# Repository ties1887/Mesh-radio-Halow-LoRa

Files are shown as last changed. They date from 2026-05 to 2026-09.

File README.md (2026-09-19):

# Mesh Radio

Open-source 3D-printable radio enclosures for Wi-Fi HaLow, MANET and LoRa experiments.

This repository contains CAD files, printable files, hardware references and short build notes. It is a DIY hardware/CAD release, not a full step-by-step wiring guide. Builders should verify fit, wiring, polarity, cooling, antenna mounting and power setup for their own hardware.

> [!TIP]
> **Support this project**  
> I am a **21-year-old full-time student** building this in my spare time. If this work helps you, donations help fund parts, prototypes and testing.  
> **[Support me on Ko-fi](https://ko-fi.com/ties1887)**

<p align="center">
  Mesh Radio V1, V2 and V3 prototypes
</p>

## Contents

- [Choose your build](#choose-your-build)
- [Standalone battery pack](#standalone-battery-pack)
- [What the files are for](#what-the-files-are-for)
- [Build notes](#build-notes)
- [Bill of materials](#bill-of-materials)
- [Planned builds](#planned-builds)
- [Software](#software)
- [Contributing and support](#contributing-and-support)
- [License](#license)

## Choose your build

| Build | Generation | Main hardware | Files |
|---|---|---|---|
| **[P4-Wio](./Second-Generation-Builds/P4-Wio/)** | Second generation | Raspberry Pi 4 + WM1302 Pi HAT + Wio-WM6108 | 3MF, STEP, SolidWorks 2025 |
| **[CM4 Carrier Board](./Second-Generation-Builds/CM4-Carrier-Board/)** | Second generation, development | Raspberry Pi CM4 + M.2 E-key Wi-Fi + optional MM8108 HaLow | KiCad source, local libraries, 3D models, review report |
| **[V3](./First-Generation-Builds/V3_18-6-2026/)** | First generation | Raspberry Pi 4 + WM1302 Pi HAT + Wio-WM6108 + RAK WisMesh 1W kit | 3MF, STEP, SolidWorks 2023/2025 |
| **[V2](./First-Generation-Builds/V2_30-5-2026/)** | First generation | Raspberry Pi 4 + WM1302 Pi HAT + Wio-WM6108 + RAK WisMesh 1W kit | 3MF, STL, STEP, SolidWorks 2023/2025 |
| **[V1](./First-Generation-Builds/V1_5-5-2026/)** | First generation | Raspberry Pi 4 + WM1302 Pi HAT + Wio-WM6108 + RAK WisMesh 1W kit | 3MF, STEP, SolidWorks 2023/2025 |

V1, V2 and V3 are still valid first generation builds. They may need more fitting or manual finishing, but they have been built, printed and used.

> [!CAUTION]
> **HaLow and LoRa together:** early tests with Wi-Fi HaLow and LoRa/Meshtastic running at the same time did not work well. The radios appeared to interfere with each other, even when using different channels. These tests were limited, so this is not a final RF conclusion, but builders should not expect HaLow and LoRa to work perfectly together without extra testing or design changes. Treat LoRa as a fallback/secondary system unless you have verified your own setup.

## Standalone battery pack

The **[Twist-Lock Battery Pack](./Twist-Lock-Battery-Pack/)** is a separate design, not part of only one build.

It is intended as a shared battery-pack design for both:

- first generation builds;
- second generation builds.

Available files include 3MF, STEP, STL and SolidWorks 2025 source archive.

## What the files are for

| File type | Use |
|---|---|
| `3MF` | Preferred print/project files for slicers |
| `STL` | Individual mesh exports when available |
| `STEP` | CAD exchange files for inspection, remixing or non-SolidWorks workflows |
| `SolidWorks` / `.zip` | Native source files or complete SolidWorks archives |

Download the complete build folder before opening a SolidWorks assembly so referenced parts remain available.

## Build notes

- **P4-Wio** is the current second generation build. It uses a Raspberry Pi 4, WM1302 Pi HAT style adapter and Seeed Studio Wio WM6108 Wi-Fi HaLow module.
- **P4-Wio is HaLow-only.** It does not include the separate LoRa/Meshtastic subsystem from the first generation prototypes.
- **V1** uses an integrated battery layout.
- **V2 and V3** use a removable twist-lock battery layout.
- **CM4 Carrier Board** source files are available for review and collaboration, but the design is not yet released for fabrication. Read its production-check report before making hardware.

<details>
<summary><strong>Prototype component and power-flow reference</strong></summary>

<br>

Prototype component and power-flow reference

This is a prototype reference for component relationships and power flow. It combines ideas from different versions and is not a final wiring guide.

</details>

<details>
<summary><strong>Prototype wiring reference</strong></summary>

<br>

Prototype wiring reference

This image documents prototype wiring. Verify every connection against the exact version and modules you are building.

</details>

## Bill of materials

The shared BOM contains parts used across multiple prototypes. **Do not order every listed part.** Check the build you are making first.

**[Open the current shared BOM](https://docs.google.com/spreadsheets/d/1Nt8EjYsgWTId0Qjl1BAAxPci3bh1FSZ7VQxQRFxyHnk/edit?usp=sharing)**

Supplier links, prices and availability may change. Confirm dimensions, connector type, voltage range and module version before ordering.

## Planned builds

<details>
<summary><strong>Future build names and targets</strong></summary>

<br>

| Build | Hardware target | Notes |
|---|---|---|
| `P4-LongWave` | Raspberry Pi 4 + Lunpid/LongWave MM8108 USB HaLow | Planned Pi 4 USB HaLow build |
| `C4-LongWave` | Raspberry Pi CM4 + Lunpid/LongWave MM8108 USB HaLow | Planned compact CM4 build |
| `C4-DualMesh` | Raspberry Pi CM4 + MM8108 HaLow + MT7916EUD | Research path for HaLow plus 2.4/5/6 GHz mesh |

```text
P4 = Raspberry Pi 4
C4 = Raspberry Pi Compute Module 4
Wio = Seeed Studio Wio WM6108 HaLow
LongWave = Lunpid/LongWave MM8108 USB HaLow
DualMesh = MM8108 HaLow plus MT7916EUD for 2.4/5/6 GHz mesh
```

A planned build should get its own folder when it has a selected hardware stack, CAD layout, printable/exported files and a short build README.

</details>

## Software

Software installation and support are provided by the upstream projects:

- **[OpenMANET documentation](https://openmanet.github.io/docs/)**
- **[OpenMANET firmware](https://github.com/OpenMANET/firmware)**
- **[Meshtastic documentation](https://meshtastic.org/docs/)**
- **[Meshtastic firmware](https://github.com/meshtastic/firmware)**

OpenMANET, Meshtastic and third-party hardware remain subject to their own licenses, documentation and support policies.

## Contributing and support

Questions, measurements, test results, issue reports, documentation corrections and design improvements are welcome.

- **[Open an issue](https://github.com/ties1887/Mesh-radio-Halow-LoRa/issues)**
- **[Create a pull request](https://github.com/ties1887/Mesh-radio-Halow-LoRa/pulls)**
- **Support the project:** https://ko-fi.com/ties1887
- **Contact:** Discord `ties1887`

Thank you to everyone who supports the project with feedback, testing, tips, donations or useful hardware/design suggestions.

## License

This repository is released under the **[Creative Commons Attribution-NonCommercial-ShareAlike 4.0 International License](./LICENSE)** (**CC BY-NC-SA 4.0**).

You may copy, build, modify and share the designs for personal, educational and non-commercial community use. You may not sell these designs, sell printed parts based on these designs, or use them commercially without written permission from the author.

Private modifications are allowed and do not need to be uploaded or published. If you share modified files publicly, they must stay under the same non-commercial share-alike license.

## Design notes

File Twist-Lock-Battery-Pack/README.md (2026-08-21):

# Twist-Lock Battery Pack

Standalone twist-lock battery pack design compatible with generation 1 and generation 2 builds.

## Status

Standalone battery pack CAD/export files are included.

## Files

| Folder | Contents |
|---|---|
| [`3MF`](./3MF/) | Print-ready project files |
| [`STEP`](./STEP/) | STEP exports |
| [`STL`](./STL/) | Individual STL exports |
| [`SolidWorks-2025`](./SolidWorks-2025/) | Native SolidWorks 2025 source files or archives |

## Notes

- Download the complete folder before opening SolidWorks assemblies so referenced parts remain available.
- Verify fit, polarity, wiring, cell configuration, BMS/charger setup and mechanical locking before use.

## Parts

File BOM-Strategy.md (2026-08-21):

# BOM Strategy Proposal

This note proposes a cleaner BOM structure for Mesh Radio builds.

## Current BOM observations

The current public Google Sheet BOM uses one shared table with version columns.

Observed structure:

- 27 part rows
- Categories: HaLow, LoRa, Battery and powermanagement, Enclosure, Extra hardware
- Version columns: V1, V2, V3, V4
- The sheet metadata still says `License: MIT`
- V4 is still present in the BOM although V4 was removed from the repository branch
- Many parts are shared across V1, V2 and V3, so fully separate BOMs would duplicate a lot of data

## Recommended approach

Use a **master parts list plus build-specific BOM views**.

This gives one place to maintain shared parts, while still making each build easy to understand.

## Suggested workbook tabs

| Tab | Purpose |
|---|---|
| `Parts` | Master list of every reusable part/component |
| `Build-Matrix` | Which build uses which part, with quantity per build |
| `V1-BOM` | Filtered view/export for V1 |
| `V2-BOM` | Filtered view/export for V2 |
| `V3-BOM` | Filtered view/export for V3 |
| `P4-Wio-BOM` | Filtered view/export for P4-Wio |
| `Battery-Pack-BOM` | Standalone twist-lock battery pack BOM, compatible with generation 1 and 2 builds |
| `Suppliers` | Supplier links, EU links, alternatives and notes |
| `Archive` | Deprecated/removed build references such as V4, if kept for history |

## Parts tab columns

| Column | Notes |
|---|---|
| `part_id` | Stable ID, e.g. `HALOW-WM6108`, `SBC-RPI4-2GB` |
| `category` | HaLow, LoRa, Power, Battery, Enclosure, Fasteners, Cables, Tools |
| `part_name` | Human-readable name |
| `description` | Short note |
| `manufacturer` | Optional |
| `mpn` | Manufacturer part number if known |
| `supplier` | Store/vendor |
| `supplier_url` | Purchase link |
| `unit_cost_eur` | Approximate cost |
| `notes` | Fitment, alternatives, warnings |
| `status` | active / optional / deprecated / unknown |

## Build-Matrix columns

| Column | Notes |
|---|---|
| `build_id` | `V1`, `V2`, `V3`, `P4-Wio`, `Battery-Pack` |
| `part_id` | Links to `Parts.part_id` |
| `quantity` | Quantity for this build |
| `required` | yes / optional / alternative |
| `role` | Main computer, HaLow module, LoRa module, power, fastener, etc. |
| `build_note` | Build-specific note |

## Why this is better

- Shared parts are maintained once.
- Each build can still have a simple filtered BOM.
- P4-Wio and the battery pack can each have their own clean view.
- Removed/experimental builds can be archived without confusing new builders.
- It avoids one giant confusing BOM and avoids many duplicated per-version BOMs.

## README recommendation

Keep the main README simple:

```md
## Bill of materials

The BOM is maintained as a shared parts list with build-specific views.
Open the BOM and use the tab for the build you are making.

- P4-Wio BOM
- Twist-Lock Battery Pack BOM
- First Generation V1/V2/V3 BOM views
```

## Next cleanup tasks

- Change BOM license metadata from MIT to CC BY-NC-SA 4.0.
- Remove or archive V4 from the active BOM tabs.
- Add `P4-Wio` and `Battery-Pack` as build IDs.
- Replace YES/NO version columns with a `Build-Matrix` tab if the sheet becomes hard to maintain.
- Keep supplier links and prices as approximate, because availability changes.

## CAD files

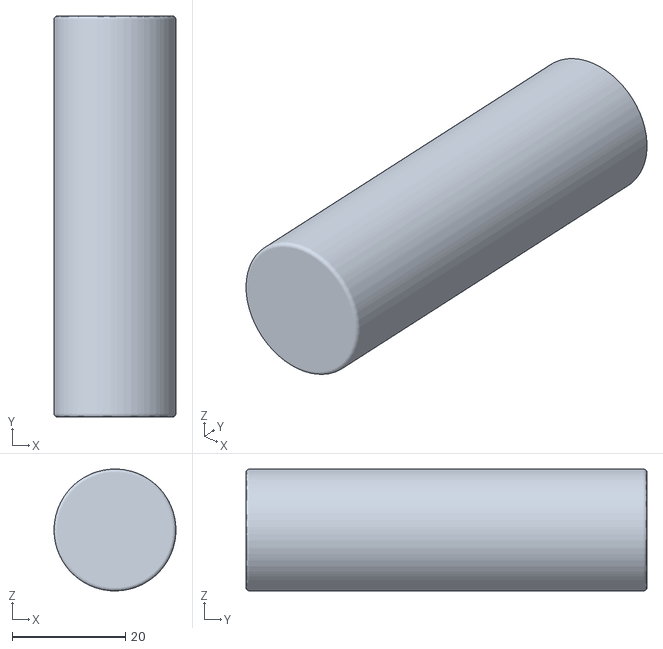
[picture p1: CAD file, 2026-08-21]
Twist-Lock-Battery-Pack/STL/Battery_Twist_Lock_Pack.SLDASM - Cell_21700-4.STL
21.5 x 70.7 x 21.5

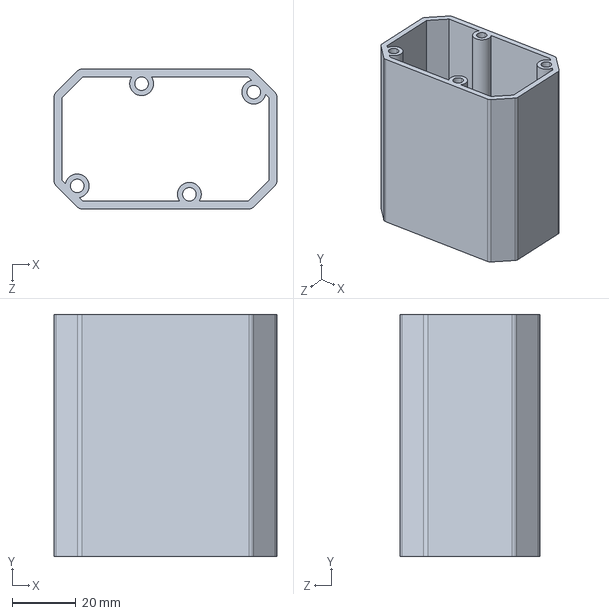
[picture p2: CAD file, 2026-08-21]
Twist-Lock-Battery-Pack/STEP/Battery_Case_Main.STEP
70.0 x 76.0 x 44.0 mm

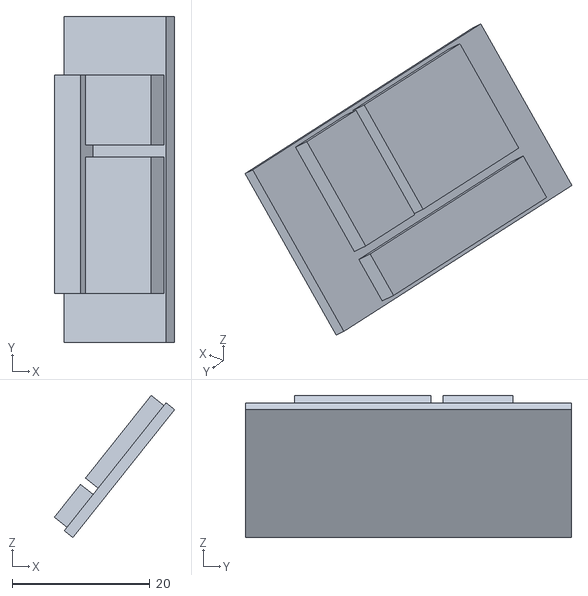
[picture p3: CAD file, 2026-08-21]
Twist-Lock-Battery-Pack/STL/Battery_Twist_Lock_Pack.SLDASM - bms 2s-1.STL
17.5 x 47.4 x 20.7

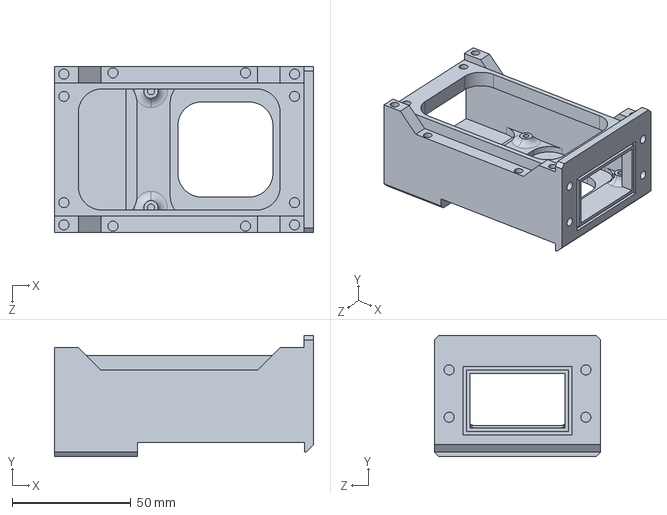
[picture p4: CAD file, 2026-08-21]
Second-Generation-Builds/P4-Wio/STEP/enclosure_main_chassis.STEP
109.0 x 51.0 x 70.0 mm

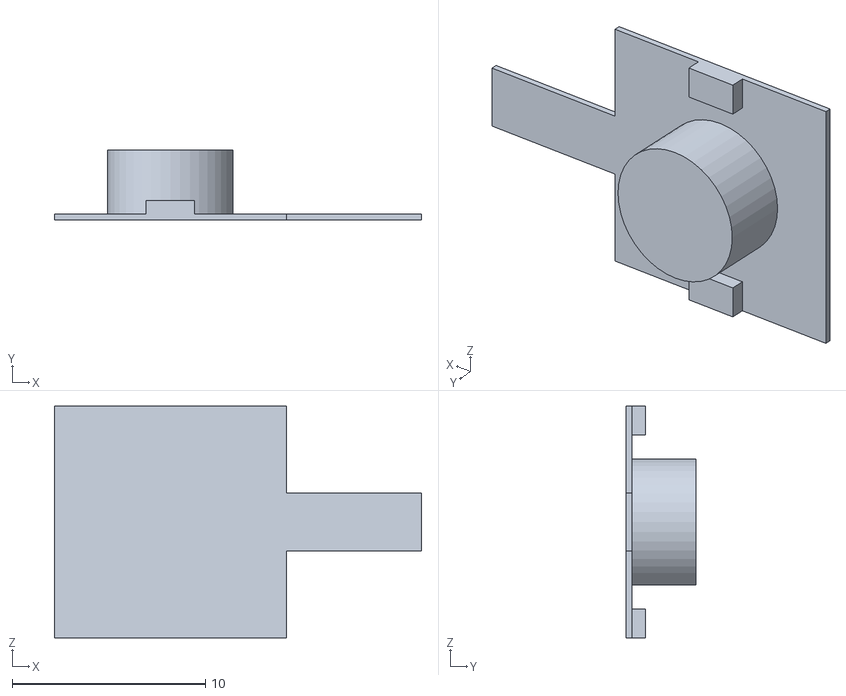
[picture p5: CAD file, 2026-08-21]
Twist-Lock-Battery-Pack/STL/Battery_Twist_Lock_Pack.SLDASM - Battery_Spring_Contact-3.STL
19.0 x 3.60 x 12.0

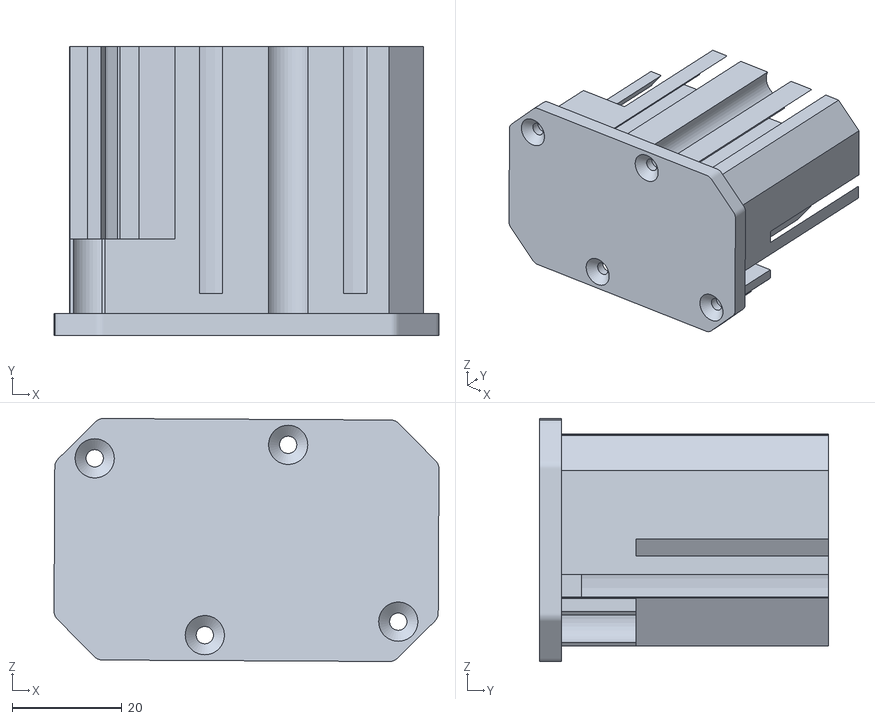
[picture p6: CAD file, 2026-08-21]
Twist-Lock-Battery-Pack/STL/Battery_Twist_Lock_Pack.SLDASM - Battery_Case_Bottom_Cover-1.STL
70.1 x 52.6 x 44.3

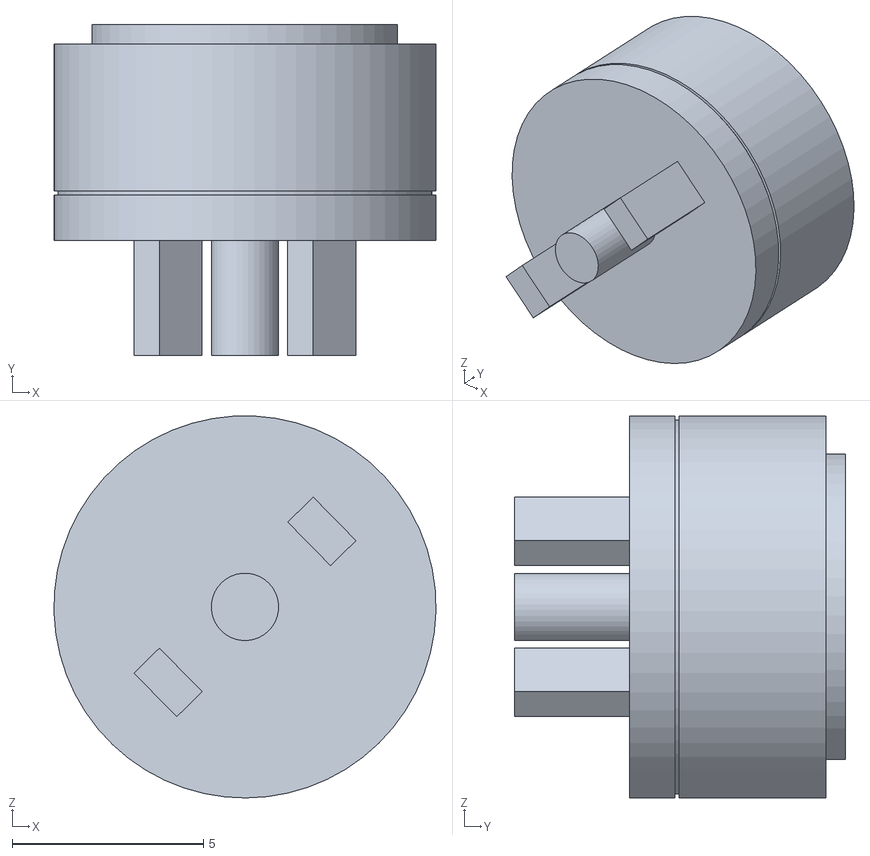
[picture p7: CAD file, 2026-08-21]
Twist-Lock-Battery-Pack/STL/Battery_Twist_Lock_Pack.SLDASM - magnetic pogo pin connector-1.STL
10.00 x 8.65 x 9.99

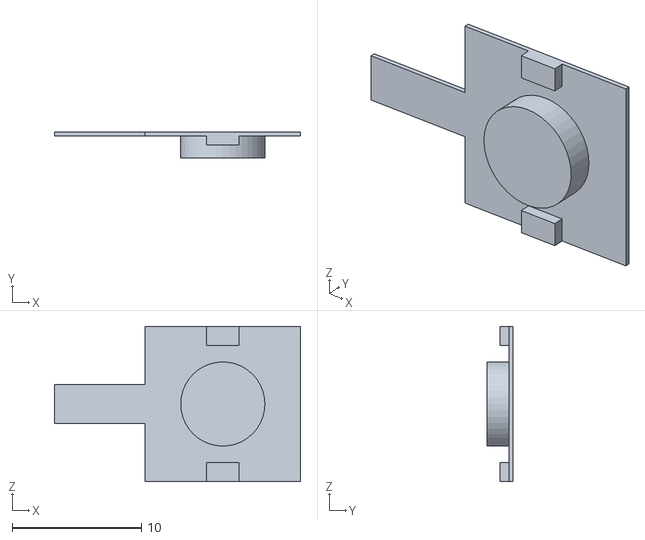
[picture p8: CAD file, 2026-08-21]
Twist-Lock-Battery-Pack/STL/Battery_Twist_Lock_Pack.SLDASM - Battery_pin_Contact-3.STL
19.0 x 2.00 x 12.0

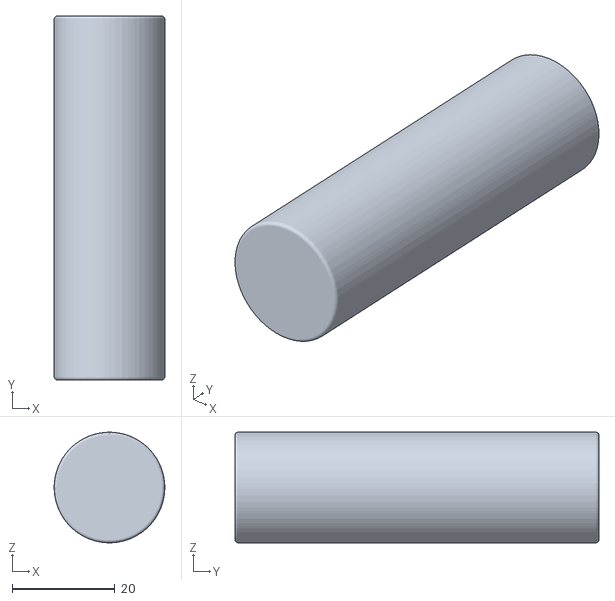
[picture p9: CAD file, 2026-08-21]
Twist-Lock-Battery-Pack/STL/Battery_Twist_Lock_Pack.SLDASM - Cell_21700-3.STL
21.5 x 70.7 x 21.5

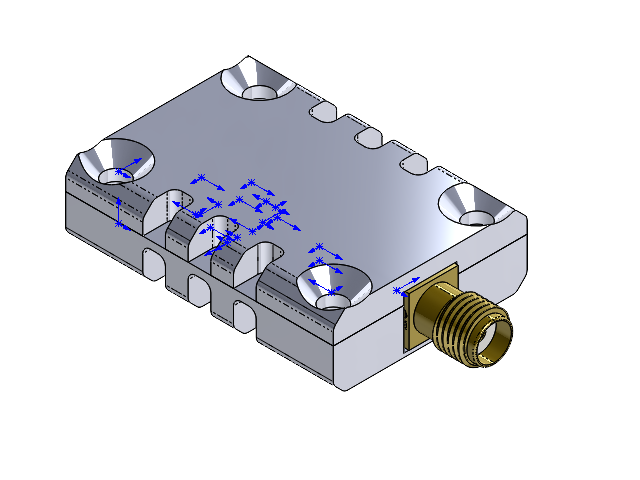
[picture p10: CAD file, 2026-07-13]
First-Generation-Builds/Standalone-Lunpid-enclosure/Solidworks 2023/enclosure.SLDASM
Bottom part
Part5^enclosure
SOT-23-5_L2.9-W1.6-P0.95-LS2.8-BL~SOT-23-5_L2.9-W1.6-P0.95-LS2.8-BL~8fiY.step
R0402~C0402_L1.0-W0.5-H0.5~8fiY.step x 8
R0402~R0402_L1.0-W0.5-H0.4~8fiY.step x 3
SMA-SMD_BWSMA-KE-P001~SMA-TH_5P-L6.5-W6.5-H9.5_BWSMA-KE-P001~8fiY.step
SC-70-3_L2.0-W1.3-P0.65-LS2.1-BL~SC-70-3_L2.0-W1.3-P0.65-LS2.1-BL~8fiY.step
LGA-38_L11.0-W10.0-P1.00-TL~LGA-38_L11.0-W10.0-P1.00-TL~8fiY.step
USB-C-SMD_TYPE-C-6PIN-2MD-073~USB-C-SMD_TYPEC-304YDSW-ACP16~8fiY.step
Board~8fiY.step

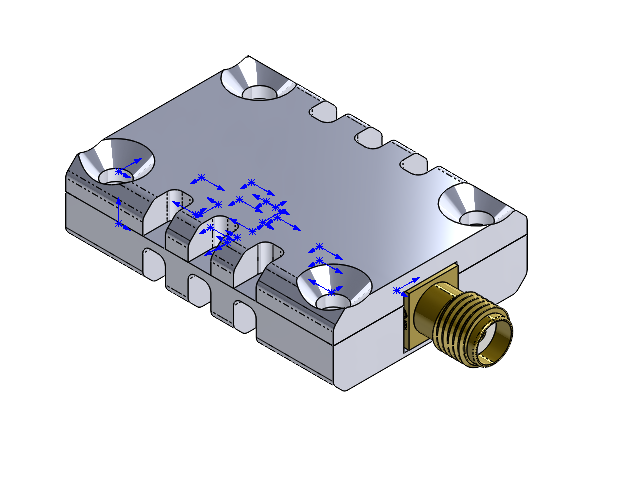
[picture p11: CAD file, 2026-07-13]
First-Generation-Builds/Standalone-Lunpid-enclosure/Solidworks 2025/enclosure.SLDASM
Bottom part
Part5^enclosure
SOT-23-5_L2.9-W1.6-P0.95-LS2.8-BL~SOT-23-5_L2.9-W1.6-P0.95-LS2.8-BL~8fiY.step
R0402~C0402_L1.0-W0.5-H0.5~8fiY.step x 8
R0402~R0402_L1.0-W0.5-H0.4~8fiY.step x 3
SMA-SMD_BWSMA-KE-P001~SMA-TH_5P-L6.5-W6.5-H9.5_BWSMA-KE-P001~8fiY.step
SC-70-3_L2.0-W1.3-P0.65-LS2.1-BL~SC-70-3_L2.0-W1.3-P0.65-LS2.1-BL~8fiY.step
LGA-38_L11.0-W10.0-P1.00-TL~LGA-38_L11.0-W10.0-P1.00-TL~8fiY.step
USB-C-SMD_TYPE-C-6PIN-2MD-073~USB-C-SMD_TYPEC-304YDSW-ACP16~8fiY.step
Board~8fiY.step

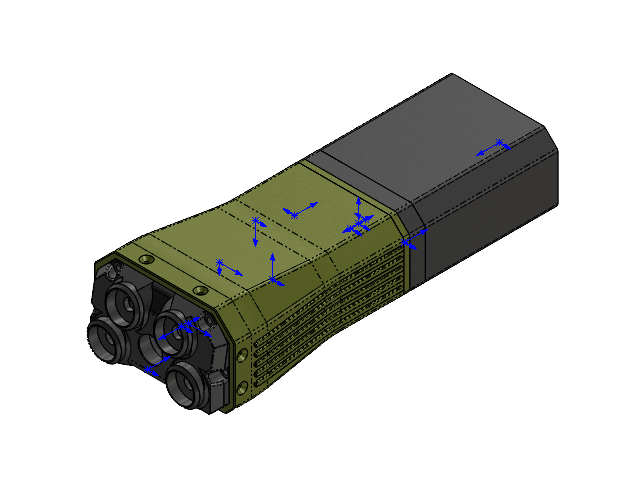
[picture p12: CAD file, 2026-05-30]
First-Generation-Builds/V2_30-5-2026/Solidworks 2025/Assem2.SLDASM
3D_RAK19007 base module + booster
pi4withall
buck converter
base
Twist lock radio part V3
middel part
Twist lock battery part V3
batcase
top
PCB frame
wing part x 2

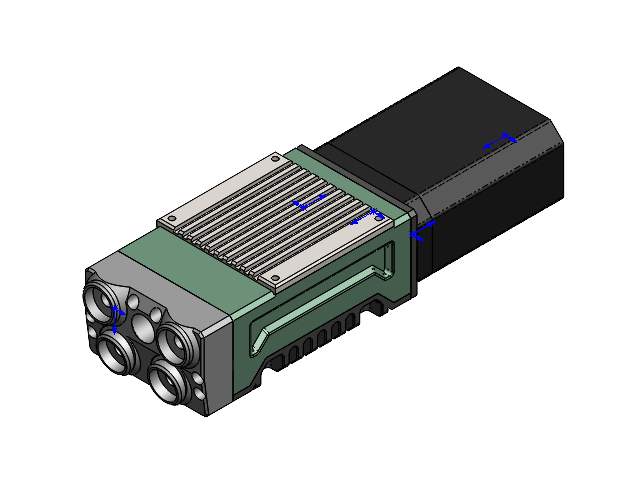
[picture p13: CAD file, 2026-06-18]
First-Generation-Builds/V3_18-6-2026/Solidworks 2025/Assem2.SLDASM
3D_RAK19007 base module + booster
pi4withall
buck converter
PCB frame
cooling
Twist lock radio part V3
Top new
middel part
batcase
Twist lock battery part V3
wing part x 2

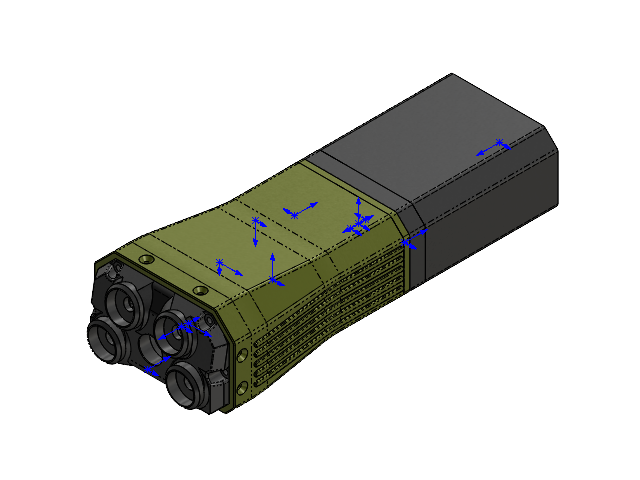
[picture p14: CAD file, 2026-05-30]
First-Generation-Builds/V2_30-5-2026/Solidworks 2023/Assem2.SLDASM
3D_RAK19007 base module + booster
pi4withall
buck converter
base
Twist lock radio part V3
middel part
Twist lock battery part V3
batcase
top
PCB frame
wing part x 2

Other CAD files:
Twist-Lock-Battery-Pack/STEP/Battery_Twist_Lock_Pack.SLDASM.STEP
First-Generation-Builds/V3_18-6-2026/Solidworks 2023/Assem2.SLDASM
Twist-Lock-Battery-Pack/STL/Battery_Twist_Lock_Pack.SLDASM - bms 2s-2.STL
Twist-Lock-Battery-Pack/STL/Battery_Twist_Lock_Pack.SLDASM - Battery_Spring_Contact-2.STL
First-Generation-Builds/Standalone-Lunpid-enclosure/3MF/enclosure.3MF
First-Generation-Builds/Standalone-Lunpid-enclosure/STEP/Bottom part.STEP
First-Generation-Builds/Standalone-Lunpid-enclosure/STEP/Top part.STEP
First-Generation-Builds/Standalone-Lunpid-enclosure/Solidworks 2023/Bottom part.SLDPRT
First-Generation-Builds/Standalone-Lunpid-enclosure/Solidworks 2023/lunpid_longwave_v0.1.step
First-Generation-Builds/Standalone-Lunpid-enclosure/Solidworks 2025/Bottom part.SLDPRT
First-Generation-Builds/Standalone-Lunpid-enclosure/Solidworks 2025/lunpid_longwave_v0.1.step
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

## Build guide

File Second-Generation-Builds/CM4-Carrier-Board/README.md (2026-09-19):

# CM4 MANET carrier board

KiCad source project for the experimental Raspberry Pi Compute Module 4 MANET carrier board.

> [!WARNING]
> **Development design — not released for fabrication.** The current production review still lists unresolved ERC, GND-connectivity, SI/PI, mechanical and manufacturing-output items. Read [`docs/PRODUCTIECHECK-2026-09-19.md`](./docs/PRODUCTIECHECK-2026-09-19.md) before using the design.

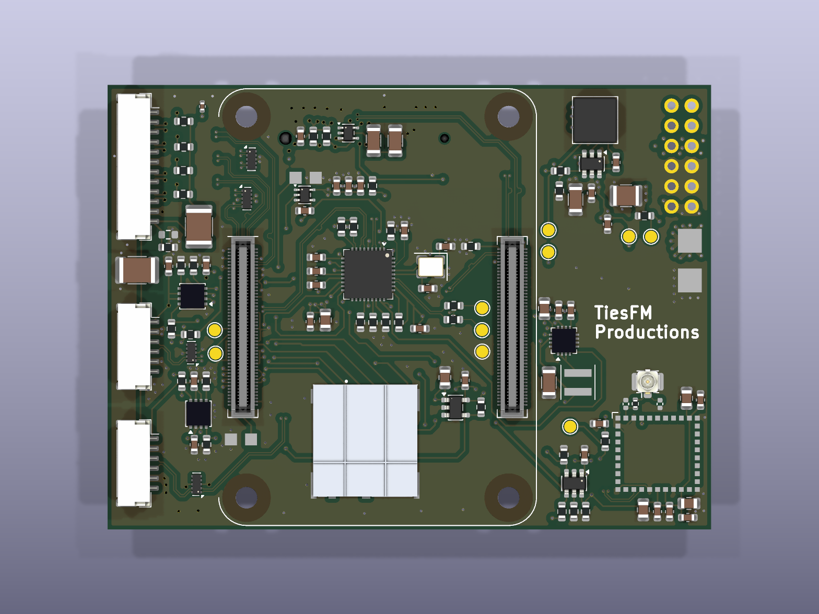
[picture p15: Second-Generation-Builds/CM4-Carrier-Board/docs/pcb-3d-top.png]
Current top-side 3D view


## Hardware target

The carrier combines:

- Raspberry Pi Compute Module 4;
- M.2 E-key Wi-Fi/MANET radio interface;
- onboard Morse Micro MM8108 HaLow option;
- USB2514B USB hub and two external USB interfaces;
- microSD, Ethernet, power regulation and service interfaces;
- Pololu D42V55F5 5 V regulator module.

## Open the project

1. Install **KiCad 10** or newer.
2. Download or clone this complete folder so the local libraries and 3D models remain beside the project.
3. Open [`CM4_MANET.kicad_pro`](./CM4_MANET.kicad_pro).
4. KiCad should resolve the bundled libraries through [`sym-lib-table`](./sym-lib-table) and [`fp-lib-table`](./fp-lib-table).

The project uses KiCad's standard symbol, footprint and 3D libraries in addition to the bundled local files.

## Included files

| Path | Purpose |
|---|---|
| `CM4_MANET.kicad_pro` | KiCad project settings and design rules |
| `CM4_MANET.kicad_sch` | Hierarchical top-level schematic |
| `01_…16_*.kicad_sch` | Schematic sheets |
| `CM4_MANET.kicad_pcb` | Routed six-layer PCB |
| `MANET.kicad_sym` | Bundled project symbols |
| `MANET.pretty/` | Bundled project footprints |
| `G2401CE.kicad_sym` | Ethernet magnetics symbol |
| `G2401CE.pretty/` | Ethernet magnetics footprint |
| `models/`, `G2401CE.3dshapes/` | Local 3D models referenced by the board |
| `docs/PLAN-EN-STATUS.md` | Canonical design context and decisions |
| `docs/PRODUCTIECHECK-2026-09-19.md` | Latest production-readiness review and correction checklist |
| `DATASHEET-INDEX-V0.11.md` | Component/source index |

## Verified source snapshot

The upload was prepared from the latest saved and synchronized project snapshot available on 19 September 2026.

| File | SHA-256 |
|---|---|
| `CM4_MANET.kicad_pro` | `29031d407538b3dbcb6472aa7c64797e4d6ba71f1556e2ef84310c6bf45d1d5d` |
| `CM4_MANET.kicad_sch` | `d8fc85620186ded0c0d289be1d9e3905773756102ce121de9318bc477c56a758` |
| `CM4_MANET.kicad_pcb` | `218439d0e7e71eeba17b0bce05ddc644826dbbb2ce876aa322ecba9a2478592e` |

## Deliberately not included

The following local files were excluded because they are stale, generated, machine-specific or not needed to inspect/edit the source:

- old Gerbers and drill files;
- old BOM/CPL quotation exports;
- old STEP assembly export;
- KiCad lock/preferences files;
- temporary validation output;
- `.history`, caches and backups;
- local copies of third-party datasheets.

Generate new fabrication files only after the correction checklist is closed and the design has passed a fresh production review.

## License

This folder follows the repository license: [CC BY-NC-SA 4.0](../../LICENSE).

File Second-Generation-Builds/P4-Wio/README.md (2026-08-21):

# P4-Wio

Second generation Mesh Radio build: Raspberry Pi 4 based HaLow-only radio enclosure using the Seeed Studio Wio WM6108 module through a WM1302 Pi HAT style adapter.

## Status

Updated P4-Wio CAD/export files are included for review and building.

## Hardware target

| Part | Role |
|---|---|
| Raspberry Pi 4 | Main computer for HaLow/IP networking |
| WM1302 Pi HAT style adapter | Mini-PCIe adapter path for the HaLow module |
| Seeed Studio Wio WM6108 | Wi-Fi HaLow radio module |

This is a **HaLow-only** build. It does not include the separate LoRa/Meshtastic subsystem from the first generation V1-V3 prototypes.

## Files

| Folder | Contents |
|---|---|
| [`3MF`](./3MF/) | Print-ready project file |
| [`STEP`](./STEP/) | Full assembly and individual CAD exchange files |
| [`SolidWorks-2025`](./SolidWorks-2025/) | Native SolidWorks 2025 source archive |

## Included CAD exports

| File | Purpose |
|---|---|
| [`P4-WIO_v1.1.3MF`](./3MF/P4-WIO_v1.1.3MF) | Print/project file |
| [`P4-WIO.STEP`](./STEP/P4-WIO.STEP) | Full assembly STEP export |
| [`raspberry_pi4_wm6108_halow_stack.STEP`](./STEP/raspberry_pi4_wm6108_halow_stack.STEP) | Pi 4 + WM6108 HaLow stack reference |
| [`enclosure_main_chassis.STEP`](./STEP/enclosure_main_chassis.STEP) | Main enclosure body |
| [`enclosure_front_cover.STEP`](./STEP/enclosure_front_cover.STEP) | Front cover |
| [`enclosure_top_cover.STEP`](./STEP/enclosure_top_cover.STEP) | Top cover |
| [`bottom seal.STEP`](./STEP/bottom%20seal.STEP) | Bottom seal |
| [`gasket_front_cover.STEP`](./STEP/gasket_front_cover.STEP) | Front cover gasket |
| [`gasket_top_cover.STEP`](./STEP/gasket_top_cover.STEP) | Top cover gasket |
| [`gasket_heatsink_external.STEP`](./STEP/gasket_heatsink_external.STEP) | External heatsink gasket |
| [`mount_twist_lock_magnetic_radio.STEP`](./STEP/mount_twist_lock_magnetic_radio.STEP) | Battery/radio interface mount |
| [`heatsink_external_70x70x3-6mm.STEP`](./STEP/heatsink_external_70x70x3-6mm.STEP) | External heatsink reference |
| [`pololu_buck_converter.STEP`](./STEP/pololu_buck_converter.STEP) | Buck regulator reference |
| [`Mpu5 antenna.STEP`](./STEP/Mpu5%20antenna.STEP) | Antenna reference |
| [`gnns gps.STEP`](./STEP/gnns%20gps.STEP) | GNSS/GPS reference |
| [`middel part.STEP`](./STEP/middel%20part.STEP) | Middle part |
| [`P4-WIO_v1.1.zip`](./SolidWorks-2025/P4-WIO_v1.1.zip) | SolidWorks 2025 source archive |

## Notes

- Download the complete folder before opening the SolidWorks assembly.
- The STEP files are provided for inspection, remixing and non-SolidWorks workflows.
- Verify tolerances, wiring, polarity, cooling, antenna fit and power setup for your own parts before applying power.

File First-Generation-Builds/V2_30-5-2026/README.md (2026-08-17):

# First Generation V2

More compact Pi 4/Wio prototype with the first integrated removable twist-lock battery.

## Visual Overview AI Render

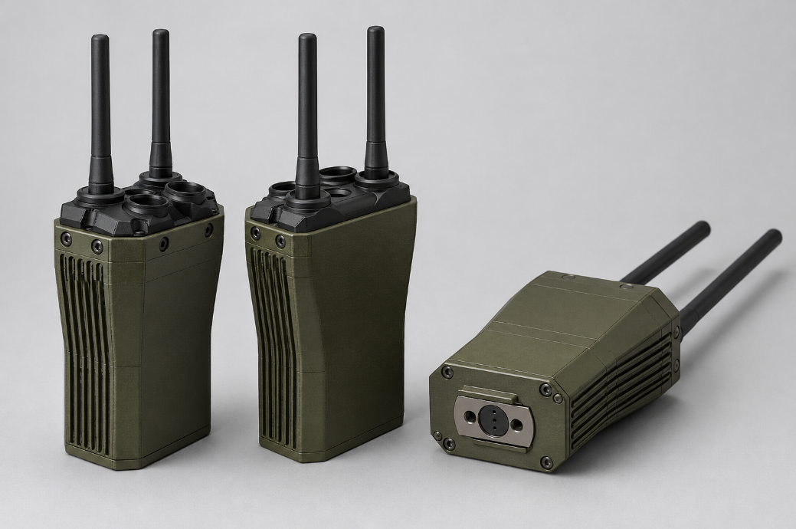
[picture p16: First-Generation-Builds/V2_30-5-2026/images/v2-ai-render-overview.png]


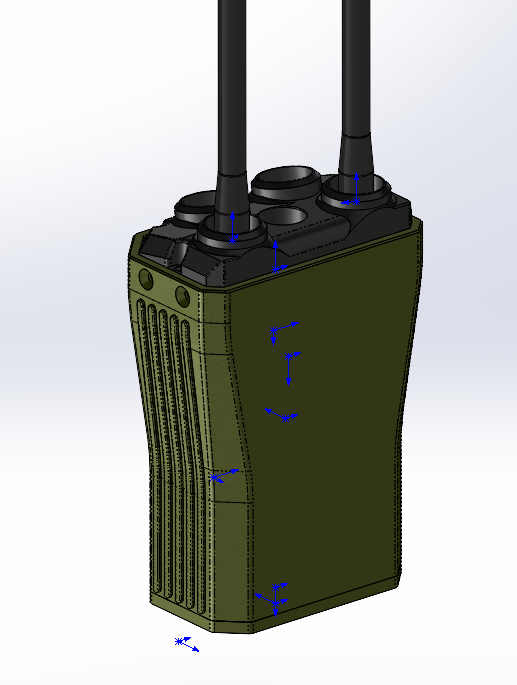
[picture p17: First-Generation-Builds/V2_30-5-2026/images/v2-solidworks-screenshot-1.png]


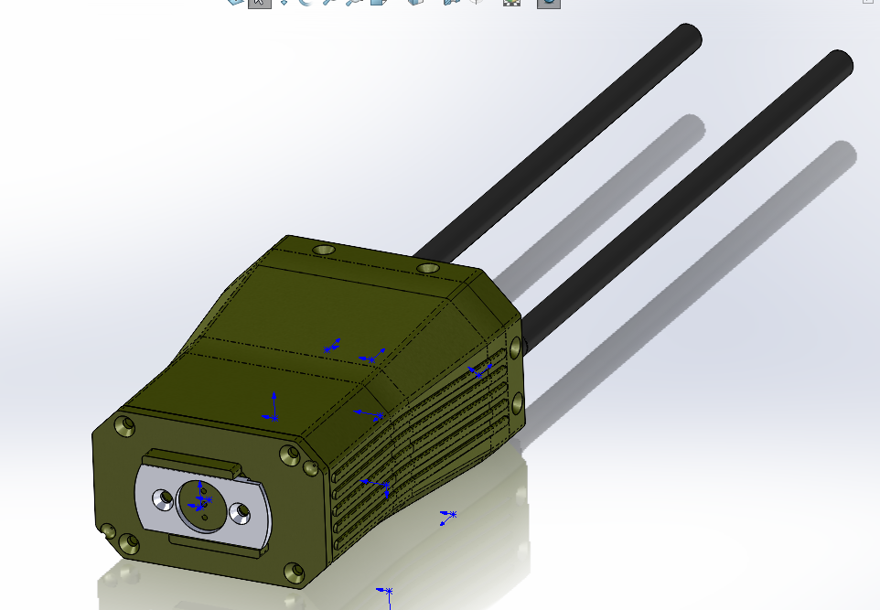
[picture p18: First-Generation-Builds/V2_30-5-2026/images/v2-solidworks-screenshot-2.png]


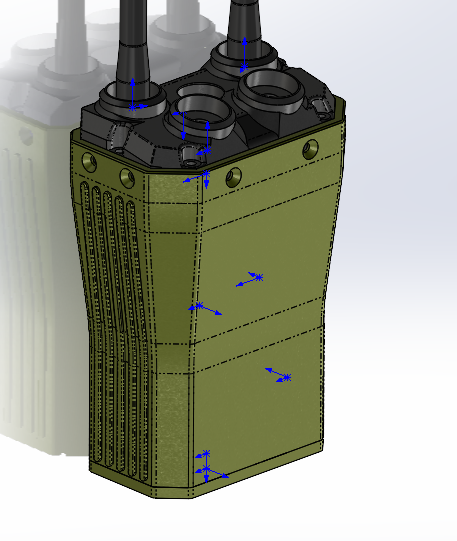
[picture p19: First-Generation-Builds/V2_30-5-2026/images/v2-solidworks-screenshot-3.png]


## Hardware

| Part | Notes |
|---|---|
| Raspberry Pi 4 | Main computer |
| WM1302 Pi HAT | Mini-PCIe adapter path |
| Seeed Studio Wio WM6108 | Wi-Fi HaLow module |
| RAK WisMesh 1W kit | Separate Meshtastic / LoRa subsystem |

## Battery

Removable twist-lock battery system.

## Files

- `3MF/` print-ready files
- `STL/` individual printable parts
- `step/` STEP exports
- `Solidworks 2023/` native files
- `Solidworks 2025/` native files

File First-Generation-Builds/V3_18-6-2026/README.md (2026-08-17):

# First Generation V3

Most complete old Raspberry Pi 4 prototype.

## Visual Overview AI Render

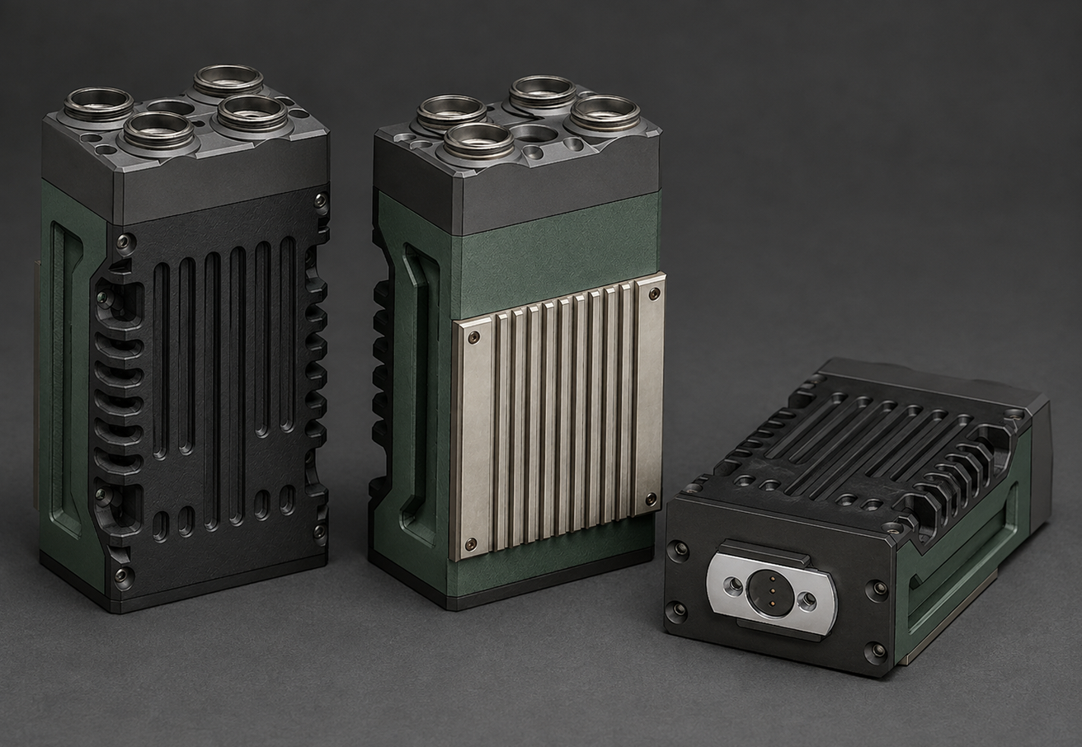
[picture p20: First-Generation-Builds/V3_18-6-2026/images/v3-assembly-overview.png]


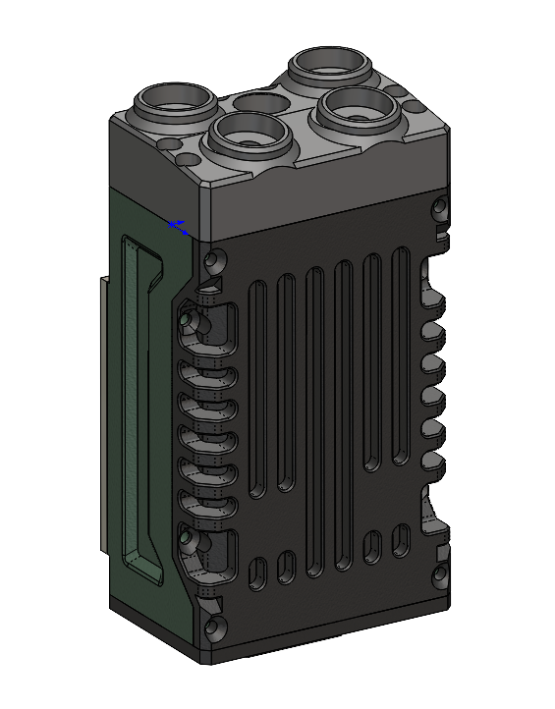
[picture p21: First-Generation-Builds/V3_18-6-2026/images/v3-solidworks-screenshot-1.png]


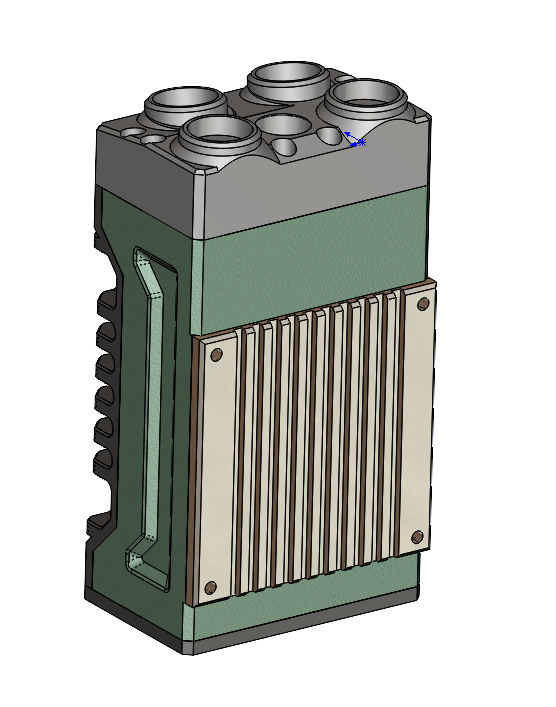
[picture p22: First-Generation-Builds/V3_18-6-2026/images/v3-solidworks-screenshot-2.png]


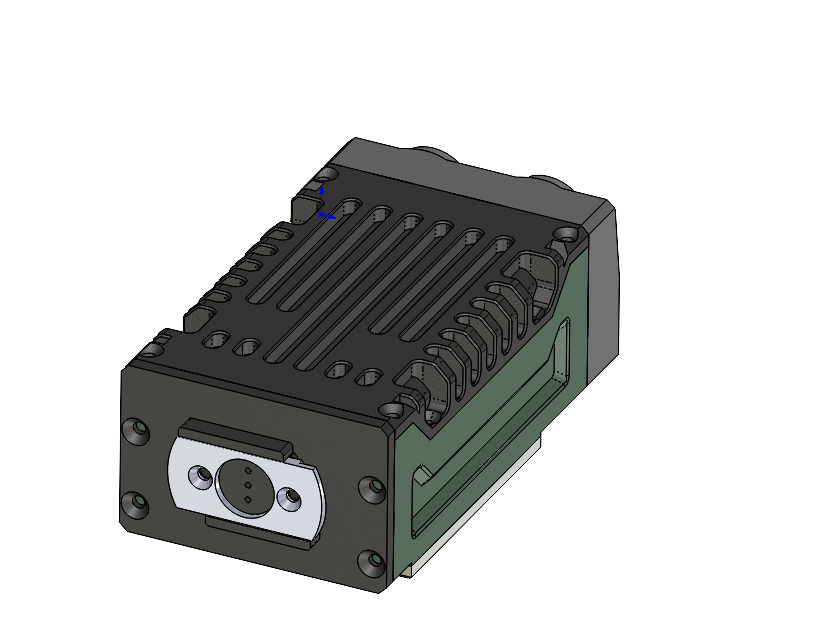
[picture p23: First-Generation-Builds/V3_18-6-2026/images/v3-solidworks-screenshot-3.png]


## Hardware

| Part | Notes |
|---|---|
| Raspberry Pi 4 | Main computer |
| WM1302 Pi HAT | Mini-PCIe adapter path |
| Seeed Studio Wio WM6108 | Wi-Fi HaLow module |
| RAK WisMesh 1W kit | Separate Meshtastic / LoRa subsystem |

## Battery

Revised removable twist-lock battery system.

## Files

- `3MF/` print-ready files
- `STEP/` STEP exports
- `Solidworks 2023/` native files
- `Solidworks 2025/` native files
- [`README BEFORE BUILD.md`](./README%20BEFORE%20BUILD.md) build notes

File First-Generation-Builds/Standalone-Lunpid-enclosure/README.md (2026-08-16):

# Standalone Lunpid enclosure

Standalone enclosure asset for the Lunpid/LongWave MM8108 USB HaLow module.

## Files

- `3MF/` print-ready files
- `STEP/` STEP exports
- `Solidworks 2023/` native files
- `Solidworks 2025/` native files

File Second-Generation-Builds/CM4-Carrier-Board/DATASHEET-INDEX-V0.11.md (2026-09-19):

# CM4-MANET v0.11 — gerichte bronindex

Deze index bevat alleen bronnen die nodig zijn om open ontwerpvragen te sluiten. De canonieke eisen en status staan in `PLAN-EN-STATUS.md`. Aanwezigheid van een bron is geen bewijs dat de review is uitgevoerd.

Legenda: **PRIMARY** officiële fabrikantbron; **REFERENCE** officieel referentieontwerp/appnote; **PENDING** nog te beoordelen of exact te selecteren; **SECONDARY** niet als enige bron gebruiken voor kritieke pinout.

## Vaste keuzes

- Pololu D42V55F5/product 5571 blijft de 5V-hoofdregelaar.
- PCB: JLCPCB JLC06161H-3313, 6 lagen, nominaal 1,6 mm.
- USB: CM4 → USB2514B → onboard MM8108-pad + twee externe USB2-poorten.
- Ethernetdoel: 100BASE-TX-magnetics op carrier → JST-GH J500 → korte twisted-pair kabel → externe RJ45.
- HaLow: onboard MM8108, met Lunpid via bestaande USB als fallback.

## Kritieke bronmatrix

| Blok | Lokale bron | Status | Nog te bewijzen |
|---|---|---|---|
| CM4 pinout en eisen | `datasheets/raspberry-pi/cm4-datasheet.pdf` | PRIMARY | alle gebruikte pinnen, voeding, boot/reset, Ethernet en PCIe |
| CM4 carrierreferentie | `datasheets/raspberry-pi/cm4iousb3-appnote.pdf` en `datasheets/raspberry-pi/CM4IOUSB3-KiCAD/` | REFERENCE | mapping, ESD, high-speed en connectorgebruik |
| CM4 connectors | Hirose-bron bij `models/DF40HC_3.0_100DS.stp` | PRIMARY | twee fysieke connectors, footprint, BOM/CPL-posities |
| Hoofdvoeding | `datasheets/pololu/D42V55F5-product-page.html` | PRIMARY/ACCEPTED | 2S–4S-belasting, thermiek en carrierkoper |
| Wi-Fi-regelaar | `datasheets/ti/tps565201.pdf`, `datasheets/ti/tps565201-EVM-user-guide.pdf` | PRIMARY/REFERENCE | stroomlus, feedback, thermiek en piekbelasting |
| Aux-regelaar | `datasheets/ti/tps62142.pdf` | PRIMARY | stroomlus, PG/EN/reset en belasting |
| AW7916 | `datasheets/asiarf/AW7916-AED-datasheet.pdf` | PRIMARY | PCIe/sideband/power en gelijktijdige belasting |
| M.2 socket J400 | `datasheets/lian-xin/APCI0085-P005A.pdf` | PRIMARY | actuele gecorrigeerde footprint, kaartregistratie en keepout |
| USB2514B | `datasheets/microchip/USB2514B-official-datasheet.pdf` | PRIMARY | configuratie, VBUS_DET, EN/OC, reset en klok |
| USB-hublayout | `datasheets/microchip/USB2514B-hardware-design-checklist.pdf`, `datasheets/microchip/AN15.17-USB2514-layout.pdf`, `datasheets/microchip/AN26.2-USB-layout.pdf` | PRIMARY/REFERENCE | ontkoppeling, kristal, routing en retourpad |
| USB-power switches | `datasheets/ti/tps2557.pdf`, `datasheets/ti/tps2553.pdf` | PRIMARY | 500 mA-poorten, ILIM, foutlogica en HaLow-rail |
| USB ESD | `datasheets/ti/tpd4eusb30.pdf` | PRIMARY | capaciteit, plaatsing en connectorovergangen |
| MM8108 | `datasheets/morse-micro/MM8108-MF15457_Data_Sheet.pdf`, `datasheets/morse-micro/MM8108-MF15457_Hardware_Design_Guide.pdf` | PRIMARY | voeding, USB, RF, matching, DNP-variant en layout |
| U.FL | `datasheets/hirose/U.FL-R-SMT-1-specsheet.pdf` | PRIMARY | footprint en U.FL/SMA-pigtailmechanica |
| microSD | `datasheets/molex/5033981892-product-brief.pdf`, `datasheets/richtek/RT9742-official.pdf` | PRIMARY | footprint, power switch en kaartdetectie/power |
| 24MHz hubkristal | actuele Y210-data plus USB2514B-eisen | PENDING | exacte fabrikantbron, CL, ESR, drive en condensatoren |

## Open bron-/onderdeelselecties

Deze punten moeten vóór schema- of productievrijgave worden gesloten:

1. **100BASE-TX-magnetics:** exact compact SMT-onderdeel, primaire datasheet, center-tap/terminatie, isolatiespecificatie, footprint en JLC-assemblagebaarheid.
2. **Ethernet ESD/chassis:** geschikte lage-capaciteitsbeveiliging en expliciete shield/chassisstrategie; TPD4EUSB30 niet zonder onderbouwing hergebruiken.
3. **Ethernet kabelpinout:** J500-pinout na magnetics, twisted-pairtoewijzing, maximale lengte en RJ45-bedrading.
4. **USB-kabels:** pinout voor J220/J240 naar externe USB-aansluitingen, twisted D+/D−, shield/chassis en maximale lengte.
5. **Y210:** exacte primaire fabrikantdatasheet voor TX322524M4DBDD2T/C5308005 of een bewust gekozen vervanger.
6. **MM8108-productievariant:** actuele beschikbaarheid en JLC-plaatsbaarheid; anders DNP-BOM en Lunpid-fallbackdocumentatie.
7. **U.FL-naar-SMA-pigtail:** exacte mechanische BOM-keuze voor behuizingsintegratie.
8. **JLC-stackup:** actuele fabrikantbevestiging van JLC06161H-3313 en productiegeometrie voor kritieke impedanties.

## Productiebronnen en momentopnamen

- `controle/JLCPCB-sourcing-audit.csv` is alleen een historische momentopname van 14 september 2026 en moet vóór vrijgave worden vervangen.
- `controle/DRC-modellen-footprint-2026-09-16.json` en `controle/ERC-na-sourcing.rpt` blijven voorlopig bewijs van de huidige niet-vrijgegeven toestand; vervang ze na geldige nieuwe native controles.
- `datasheets/SOURCE-MANIFEST.json` registreert bronbestanden. Gebruik voor kritieke beslissingen altijd de primaire lokale bron, niet alleen een productpagina of distributeurtekst.

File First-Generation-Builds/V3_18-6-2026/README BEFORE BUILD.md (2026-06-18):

# Read before building V3

The V3 build is a slightly more complex build than the earlier versions, so here are some tips to help you on your way!
Please take your time and check every part carefully before assembly.

This version is still in beta. Some parts may need small adjustments, sanding, fitting, or extra work during the build.

## Important notes

* Make sure you use the correct screw lengths.
* Screws that are too long can go too deep into the frame and may cause shorts by touching internal electronics, PCB parts, or solder pads.
* When sliding the PCBs into the enclosure, there is very little tolerance. Move them in carefully and make sure you do not push off or damage any small components.
* All positive and negative power wires should be twisted together as pairs. This helps reduce electrical noise and keeps the wiring cleaner.
* It is recommended to use 16 AWG or 18 AWG wire for the main power wiring. Thicker wire has lower resistance, which helps reduce voltage drop and heat generation.
* The buck converter can generate a lot of electrical noise. It is recommended to shield/isolate the buck converter from the rest of the electronics using copper tape.
* If copper tape is used as shielding, it should be connected/soldered to ground. Make sure the copper tape cannot touch any live contacts, solder pads, or components, otherwise it can create a short.
* It is recommended to install a small heatsink kit on the Raspberry Pi.
* The rear heatsink included in the build files as a 3MF and STEP file is mainly intended for visual/reference purposes. In the BOM, there is a link to the real metal version of this heatsink. It is recommended to buy and use the metal version instead of the 3D-printed version.
* The twist-lock battery connection system is still being improved. The current pogo-pin connection will likely be replaced soon with a stronger magnetic connection that clicks in more firmly and is easier to solder.
* For the front and rear seals, there is a groove designed for a 2 mm diameter rubber cord or rubber O-ring material.
* A practical way to make these seals is to buy large rubber O-rings, cut them to the correct length, and glue the ends together.
* This should be considered water-resistant, not fully waterproof. No waterproof rating or guarantee is given.
* All parts are designed to be 3D printed without supports.db9d3973-dfbc-4dac-b72b-2cc7cdb6f751

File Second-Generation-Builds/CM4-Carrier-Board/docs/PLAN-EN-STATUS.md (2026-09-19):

# CM4-MANET v0.11 — canonieke status en plan

Bijgewerkt: 19 september 2026 na een volledige productiecheck van de nieuwste aantoonbaar gesynchroniseerde schema-, PCB- en fabricagebestanden.

> **Status: niet productierijp; niet bestellen.** Dit document is de enige canonieke ontwerpcontext. Het plan geeft volgorde en acceptatiecriteria, maar machtigt een AI-model alleen voor de expliciet toegewezen taak of fase.

## 1. Productdoel

Een productierijpe CM4-MANET-carrier voor één serie van **5 identieke boards**, grotendeels geassembleerd door JLCPCB. De carrier combineert CM4, AW7916 Wi-Fi, HaLow, USB, Ethernet, microSD, voeding en servicefuncties.

**Productierijp betekent hier:** reproduceerbaar ontwerp en assemblagepakket, gesloten elektrische en mechanische ontwerpvragen, actuele sourcing, nul onverklaarde ontwerpcontrolefouten en een uitvoerbare acceptatietest. Het betekent niet dat werking zonder fysieke prototypes kan worden gegarandeerd.

## 2. Actieve bestanden en bewijs

- Project: `CM4_MANET.kicad_pro`
- Top-schema: `CM4_MANET.kicad_sch` met 16 genummerde subsheets
- PCB: `CM4_MANET.kicad_pcb`
- Lokale bibliotheken: `MANET.kicad_sym`, `MANET.pretty/`
- Modellen: `models/`
- Bronnen: `datasheets/`
- Bewijs: `controle/`

### Actuele productiecheck — 19 september 2026

- Volledig rapport en afvinkbare correctielijst: `PRODUCTIECHECK-2026-09-19.md`.
- PCB SHA256: `218439d0e7e71eeba17b0bce05ddc644826dbbb2ce876aa322ecba9a2478592e`; Nextcloud-metadata en lokale mtime kwamen overeen op `2026-09-19 12:25:02 UTC` en er stond geen pending transfer/conflict geregistreerd.
- Schema en projectinstellingen zijn sinds de vorige audit niet gewijzigd; PCB wel.
- Schema-ERC: 2 fouttypen op dezelfde `U100 pin 2 [GND]`: niet aangesloten en power-input niet aangedreven; 0 waarschuwingen.
- Schema↔PCB-pariteit: 0 meldingen; 122 schemaonderdelen en 122 PCB-footprints.
- PCB-DRC verbeterde van 65 naar **37** onverbonden items, allemaal GND. Resterende losse eindpunten zijn 30 GND-pads van U100, U120.2, U20.15 en gescheiden GND-zones.
- Standaard-DRC: U100-librarymismatch, 2 dangling via's (`BAT_POS`, `CM4_nRPIBOOT`) en 2 geïsoleerde `+3V3_AUX`-kopereilanden. Strikte audit voegt J120-footprinttype en ontbrekende courtyards van J1/J110/J111 toe.
- Geen niet-GND-signaalopens, shorts, clearancefouten of parityproblemen gevonden. D500/D501 en J400 staan niet meer in de openlijst.
- Ethernet is gerouteerd, maar `ETH_C0…ETH_C3` valt nog op de standaard 0,2-mm-netclass; ook ETH3 bevat een afwijkend 0,2-mm-segment.
- Retourvia-afstanden zijn verbeterd maar nog onvoldoende bij meerdere PCIe-, USB- en Ethernetlaagwissels; powerdimensionering en thermiek zijn nog niet gesloten.
- BOM/CPL-varianttransformatie blijft niet reproduceerbaar: actuele POS heeft 122 refs, offerte-BOM/CPL 106; U100 wordt handmatig gesplitst naar J100/J101 en uitsluitingen staan niet eenduidig in de bron.
- 3D-render slaagt zonder evidente botsing, maar PS1, U300, J1/J110/J111 missen een model en L20 verwijst naar een niet-bestaand modelbestand.
- Productie-output is verouderd: actuele verse drill heeft 411 PTH-hits tegenover 310 in het bestaande bestand; bestaande Gerbers, drills, BOM/CPL, STEP en sourcing-audit mogen niet worden gebruikt voor bestelling.
- Na de nacontrole is KiCad opgeslagen en gesloten; de opnieuw gecontroleerde hash bleef gelijk aan de hierboven genoemde baseline.
- Vrijgavebesluit: **niet bestellen** totdat de volledige P0/P1-correctielijst is afgewerkt en alle vrijgavepoorten opnieuw zijn gecontroleerd.

### Actuele 3D-modelcontrole — 18 september 2026

- Actuele PCB SHA256: `e055fe37a17c02e47db81858e040c445bb8d37cab2e0fce70c23fd5a6851b239`.
- Uitgangspunt: gebruikersbestand van 18 september, SHA256 `2ae3ba5cbf042bc7f38d0ddd3b72e0417ed1c64bb4559dcbb51462d4b373d992`; geen actieve KiCad-editor of lock aangetroffen.
- J120: ontbrekend `./CM4IO.3dshapes/5033981892.stp` vervangen door `models/Molex_5033981892_simplified.wrl`, met nuloffset en nulrotatie. Vereenvoudigde houder met metalen kap, opening, basis en contacten; 13,10 × 14,05 mm volgens bestaande footprint en hoogte 1,28 mm volgens de lokale Molex-productbrief. Geen fabrikant-CAD of mechanische vrijgave; WRL voor de 3D-viewer, niet voor STEP-export. De officiële Molex STEP-download gaf herhaaldelijk verbindingsfouten.
- T500: lokale Z-offset van 0 naar +2,25 mm. STEP-geometrie gemeten met OpenCascade: oorspronkelijke Z-grenzen −2,25 tot +2,00 mm, gecorrigeerd 0 tot +4,25 mm ten opzichte van het montagevlak. T500 blijft B.Cu; de positieve lokale offset verplaatst het model naar buiten aan de onderzijde.
- Beide aanpassingen ook verwerkt in de bijbehorende lokale footprintbibliotheken.
- Via KiCad opnieuw geladen en gecontroleerd: na verwijderen van uitsluitend modelvelden uit tijdelijke vergelijkingskopieën zijn alle overige geserialiseerde PCB-gegevens byte-identiek. Andere modelkoppelingen en transformaties gelijk. Geen elektrische wijzigingen of nieuwe ERC/DRC uitgevoerd.
- Nieuwe renders van boven- en onderzijde visueel bekeken: `controle/3D-modellen-boven.png` en `controle/3D-modellen-onder.png`. Meet- en vergelijkingsresultaat: `controle/3D-modelcontrole.json`.
- Back-up en werkscripts zijn lokaal buiten deze repository bewaard.
- Gebruikersafspraken in `AGENTS.md`: vrije toolkeuze, opdracht inclusief noodzakelijke kleine correcties, grotere ontwerpkeuzes eerst bespreken, bij open editor eerst laten opslaan en sluiten.

### Eerdere 3D-modelcontrole — 17 september 2026

- Actuele PCB SHA256: `d0ff44ffc95e4b04cfe4c602514808cdaec2135e3ad440347146007d0f9684dd`.
- Uitgangspunt was de nieuwere PCB met SHA256 `059a720c1e970e70148941845fc17f877f1abb17a8ee9d698a9f030afc41d92f`; T500 was daarin al geplaatst aan B.Cu. Eerdere vermeldingen hieronder dat T500 ontbreekt beschrijven dus een oudere momentopname.
- U200/USB2514B: lokaal KiCad STEP-model, QFN-36 6 × 6 mm, pitch 0,5 mm, exposed pad 3,7 × 3,7 mm volgens de Microchip-datasheet, pagina 49. Het bestaande footprintkoper is niet aangepast.
- U220/U240/TPS2557: lokaal, vereenvoudigd VRML-behuizingsmodel op basis van TI DRB0008B, 3 × 3 mm, pitch 0,65 mm, exposed pad 1,65 × 2,4 mm; bron `datasheets/ti/tps2557.pdf`, pagina 27.
- U20/TPS62142: lokaal, vereenvoudigd VRML-behuizingsmodel op basis van TI RGT0016C, 3 × 3 mm, pitch 0,5 mm, exposed pad 1,68 × 1,68 mm; bron `datasheets/ti/tps62142.pdf`, pagina 39. De twee TI-modellen zijn nominale visualisatiemodellen, geen originele fabrikant-CAD; WRL is bedoeld voor de 3D-viewer en niet voor STEP-export.
- T500/G2401CE: bestaand STEP-model gekopieerd naar `models/G2401CE.step`; zichtbaar aan de onderzijde. Alle vijf koppelingen gebruiken `${KIPRJMOD}/models/`. Ook de vier bijbehorende lokale footprintbibliotheekbestanden zijn bijgewerkt, inclusief het oude `/tmp/`-pad in de G2401CE-library.
- Gecontroleerd na opnieuw laden met KiCads native API: footprintposities/rotaties/zijden, padposities/afmetingen/netten, tracks/via's, zonekenmerken en boardtekeningen gelijk; overige 3D-modelkoppelingen gelijk. Geen schemawijziging of routing uitgevoerd. `kicad-tool` was niet beschikbaar; uitsluitend 3D-links zijn via de native API gewijzigd.
- Beide zijden visueel gecontroleerd: `controle/3D-modellen-boven.png` en `controle/3D-modellen-onder.png`. Geen nieuwe ERC/DRC-vrijgaveclaim.
- De historische lokale backup is niet in deze repository opgenomen.

Volledige signaalpadcontrole op 17 september 2026:

- PCB SHA256: `0a4a7189c81cf52d06b4d5ab019335664fc9d19bbfe7e0259a17088c8192a2b1`.
- Project SHA256: `9b9278b30e732ab3ec014140c1c49c85556643b9aa0d8f65db484c9f89e72d88`.
- Volledig rapport: `controle/SIGNAALPADEN-STATUS-2026-09-17.md`.
- Geen signal-shorts of clearancefouten gevonden.
- USB-, PCIe- en RF-breedtes en hoofd-pair-gaps zijn correct; `USBA/USBB` zijn van `In3.Cu` naar F.Cu/B.Cu verplaatst.
- Buiten Ethernet blijft één gewone signaalopen: `AUX_SS` tussen U20.9 en C23.1.
- Twee dangling signaalvia's blijven: `USBA_FAULT_N` en `USBB_EN`.
- Kritieke P/N-via-aantallen zijn symmetrisch. Er zijn 23 GND-via's, maar geen lokale retourvia binnen 1 mm van een kritieke laagwissel.
- Ethernet-schema is herontworpen: CM4-MDI0..3 → D500/D501 → `T500` G2401CE → `ETH_C0..3_P/N` → J500. PHY-center taps gaan via `C501` 100 nF naar GND; kabel-center taps via `R502`–`R505` 75 Ω en `C502` 1 nF/2 kV naar CHASSIS.
- Verse schema-ERC: 2 fouten, beide reeds bestaande `U100.2`-GND-problemen; geen nieuwe Ethernet-ERC-meldingen. De netlist bevestigt alle 24 T500-pinnen en de bedoelde galvanische netscheiding.
- PCB is nog niet gesynchroniseerd: `T500`, `C501`, `C502` en `R502`–`R505` ontbreken op de PCB (naast het reeds ontbrekende `PS1`). Actuele PCB-controle: 30 DRC-meldingen, 218 unconnected items en 142 paritymeldingen.
- Ethernetsporen hebben op de huidige PCB geen segmenten; impedantie en routing van het nieuwe magnetics-pad zijn daarom nog niet vrijgegeven.

**Bewijslabel:** nominale breedte en gap zijn geometrisch gecontroleerd; fysieke impedantie, elektrische werking, thermiek, mechanica, assemblage en sourcing zijn nog niet bewezen.

## 3. Vaste architectuur en gebruikersbesluiten

### Assemblage en varianten

- Serieomvang: exact 5 boards.
- JLCPCB plaatst vrijwel alle vaste SMD- en THT-carrieronderdelen die hun proces ondersteunt.
- CM4, AW7916 en Pololu D42V55F5 worden altijd door de gebruiker gemonteerd en moeten correct uit BOM/CPL-plaatsing worden uitgesloten.
- MM8108 blijft als onboard ontwerpoptie aanwezig.
- Als MM8108 niet leverbaar is of niet werkt, wordt een Lunpid HaLow-module via een bestaande externe USB-poort gebruikt.
- Onboard MM8108 en Lunpid hoeven niet gelijktijdig te werken.
- AW7916 plus de gekozen HaLow-oplossing moeten wel gelijktijdig onder hoge belasting werken.

### Voeding

- Ingang: 2S–4S Li-ion/LiPo via de bestaande BAT+/GND-soldeerpads, maximaal 16,8 V en maximaal 7 A.
- Accu/BMS verzorgt celbewaking, onderspanningsafschakeling en accubeveiliging; de carrier voegt dit niet toe.
- Hoofdregelaar blijft Pololu D42V55F5/product 5571, 5 V. Geen alternatief of eigen moduleontwerp zonder opdracht.
- Externe USB-poorten: circa 500 mA per poort.
- Voedingsbudget, spanningsval, thermiek, contacten, sporen, via’s en retourpaden moeten AW7916 plus MM8108 óf Lunpid onder gelijktijdige belasting dragen.

### USB en HaLow

- USB-topologie blijft: CM4 USB2 → USB2514B → onboard MM8108-pad en twee externe USB2-poorten.
- `J220` en `J240` blijven 6-polige JST-GH-connectors. De gebruiker maakt kabels naar externe USB-aansluitingen.
- Voor onboard MM8108 blijft de RF-keten: U.FL op carrier → U.FL-naar-SMA-pigtail → SMA-antenne.
- C307–C309 zijn actieve bypasscondensatoren. C305/C306 blijven DNP en R301 blijft 0 Ω totdat RF-review iets anders onderbouwt.

### Ethernet

- Ethernet blijft aanwezig; snelheid is ondergeschikt aan compactheid en betrouwbaarheid.
- Doelarchitectuur: robuuste 100BASE-TX, met vierpaar/Gigabit-compatibele `G2401CE`-magnetics zodat alle CM4-MDI-paren behouden blijven.
- `T500` is G2401CE, LCSC `C2904710`, op de carrier tussen CM4/ESD en kabelconnector.
- De bestaande 12-polige JST-GH `J500` blijft, tenzij een aantoonbaar vergelijkbare compacte connector noodzakelijk is.
- De gebruiker maakt een korte kabel van J500 naar een gewone externe RJ45.
- De directe CM4 → J500-schemaverbinding is vervangen; PCB-plaatsing/routing en fysieke kabelvalidatie staan nog open.

### Mechanica en PCB

- Fabrikant/stackup: JLCPCB `JLC06161H-3313`, 6 lagen, nominaal 1,6 mm, ENIG.
- Lagen: F.Cu kritisch/high-speed; In1.Cu GND; In2.Cu voeding/signaal; In3.Cu voeding/signaal; In4.Cu GND; B.Cu kritisch/high-speed.
- Geen signaalrouting op de twee GND-lagen.
- Gewone through-via’s zijn de standaard; HDI/blind/buried vias zijn niet vrijgegeven.
- Hoofdposities en zijden van U100, J400, PS1, J220, J240 en J500 blijven vast tenzij expliciet anders opgedragen.
- Onderdelen onder de CM4 zijn door de gebruiker mechanisch geaccepteerd; heropen dit niet zonder nieuwe concrete botsing.
- PS1 blijft verhoogd op F.Cu; alleen soldeergaten worden gebruikt.
- Geen componenten onder het AW7916-kaartvlak aan de kaartzijde; geïsoleerde sporen mogen daar lopen.
- Carrierafmetingen, montagegaten, connectorposities, kabelrichtingen en kaart-envelopes worden vóór vrijgave definitief. De behuizing volgt daarna de carrier.

## 4. Actuele blokkades

### P0 — architectuur en schema

1. **Schema afgerond:** G2401CE (`C2904710`) met vier PHY-paren, center taps, Bob-Smith-afsluiting, bestaande ESD en J500-pinout. Nog open: PCB-plaatsing/routing en prototypevalidatie.
2. Verbind en controleer `U100.2` als GND in het schema; verifieer alle 200 CM4-pinnen en de samengestelde footprint tegen primaire Raspberry Pi/Hirose-bronnen.
3. Beoordeel `U200.20` slash-escaping en zorg dat schema en PCB exact dezelfde bedoelde ongebruikte netstatus hebben.
4. Leg twee assemblagevarianten vast: MM8108 geplaatst en MM8108 DNP/Lunpid extern. Voorkom zwevende rails/signalen of misleidende BOM-regels.
5. Sluit nog open elektrische reviews: U10/U20 stroomlussen en feedback, USB2514B-klok/ontkoppeling/defaults, reset/enable/boot, CM4/AW7916-mapping, microSD, USB-power switches, Ethernet-ESD/chassis en MM8108 RF.

### P1 — schema/PCB-pariteit en routing

1. Los de twee echte parity-netconflicten op.
2. Synchroniseer het `Review`-veldbeleid en BOM-exclude-instellingen zonder nuttige metadata te verliezen.
3. Werk J400-herstelrouting af: PCIe TX/RX/CLK, CLKREQ en GND; behoud bewust ongebruikte PS1-VRP-functie.
4. Verwijder of herstel alle doodlopende koperstukken en de doodlopende via.
5. Los de U100-bibliotheekafwijking bewust op; behoud het gevalideerde footprintmodel en de twee fysieke Hirose-connectors.
6. Controleer planecontinuïteit, retourpaden en stitching na routing.
7. Synchroniseer en plaats `T500`, `C501`, `C502`, `R502`–`R505`; routeer de vier MDI-paren gecontroleerd aan beide zijden van de magnetics en herhaal DRC/parity/impedantiecontrole.

### P2 — layout, SI/PI, thermiek en mechanica

1. Bevestig JLC-stackup en werkelijke impedantiegeometrie met fabrikantdata.
2. Controleer PCIe/USB2/RF/Ethernet-paarvoering, lengtes, skew, laagwissels en referentievlakken.
3. Dimensioneer BAT+, 5 V, 3V3_WIFI, 3V3_AUX en 3V3_HALOW inclusief halsjes, via’s, contacten en temperatuurstijging.
4. Controleer schakelregelaars tegen referentielayouts en voer een gerichte EMC-/retourstroomreview uit.
5. Valideer J400-kaartregistratie, connectoren, kabeluitgangen, U.FL/SMA-pigtail, soldeermasker/paste en via-in-pad-afwerking.

### P3 — productie en test

1. Maak actuele JLC-sourcingaudit voor exact 5 boards plus passende reserveonderdelen.
2. Verifieer alle MPN/LCSC/Manufacturer-velden en maak correcte BOM/CPL-regels; CM4, AW7916 en Pololu uitsluiten.
3. Behandel de twee fysieke CM4-Hirose-connectors als afzonderlijke plaatsingsregels met echte positie en rotatie.
4. Maak gecontroleerde Gerber-, boor-, BOM- en CPL-export en voer onafhankelijke import-/viewercontrole uit.
5. Documenteer handmontage van CM4, AW7916 en Pololu en de kabelpinouts voor USB, Ethernet en U.FL/SMA.
6. Test alle 5 boards volledig; voer op minstens 1 board een langdurige gecombineerde stresstest uit.

## 5. Uitvoeringsvolgorde

Voer alleen een expliciet toegewezen fase uit.

| Fase | Werk | Klaar wanneer |
|---|---|---|
| 0 | Baseline en requirements | Actuele hashes/lock/status bekend; opdracht begrensd; backup buiten project |
| 1 | Ethernet-architectuur + schemafixes | Exacte 100BASE-TX-oplossing gekozen; ERC schoon; netlistwijzigingen verklaard |
| 2 | Volledige elektrische review | Elk kritisch blok tegen primaire bron gecontroleerd; besluiten en restpunten vastgelegd |
| 3 | Schema-PCB-sync en J400-routing | Nul onbedoelde parityconflicten of opens; DRC-uitzonderingen verklaard |
| 4 | SI/PI/thermiek/mechanica | Geometrie, stroomcapaciteit, thermiek en fysieke interfaces aantoonbaar beoordeeld |
| 5 | BOM/CPL/sourcing | Exacte productievariant en alle plaatsings-/handmontageregels reproduceerbaar |
| 6 | Productie-export | Native controles en onafhankelijke exportcontrole voldoen aan vrijgavepoort |
| 7 | Bouw en acceptatietest | Alle 5 functioneel geslaagd; 1 langdurige stresstest geslaagd |

## 6. Vrijgavepoort

Vrijgave voor productie vereist tegelijk:

- 0 ERC-fouten;
- 0 onverklaarde schema↔PCB-netconflicten;
- 0 onbedoelde onverbonden items;
- 0 onbedoelde DRC-errors of waarschuwingen;
- elke genegeerde DRC-categorie afzonderlijk beoordeeld en gemotiveerd;
- primaire-broncontrole van pinmapping, footprints en kritieke schakelingen;
- geverifieerde zeslaagse stackup en kritieke impedantie-/retourpaden;
- gesloten stroom-, spanningsval- en thermische beoordeling;
- gesloten mechanische interfaces en kabelpinouts;
- actuele sourcing en gecontroleerde BOM/CPL;
- onafhankelijk gecontroleerde Gerber-/boorbestanden;
- gedocumenteerde testprocedure en handmontage-instructies.

Na assemblage vereist acceptatie:

- alle 5 boards: rails/shorts, CM4-opstart, USB-hub en beide externe poorten, AW7916, gekozen HaLow-pad, Ethernet, microSD en reset/servicefuncties;
- minstens 1 board: langdurige AW7916 + HaLow + USB-belasting met gemeten temperaturen en spanningsval, zonder brown-out, instabiliteit of overschrijding van componentlimieten.

## 7. Bewijsbeheer en bekende toolbeperking

- In `controle/` blijven uiteindelijk alleen de nieuwste geldige vrijgave-ERC, DRC/parity, BOM/CPL-audit en sourcingmomentopname.
- Verwijder oude bewijzen pas nadat geldige vervangers bestaan.
- `kicad-tool pcb sync --dry-run` faalde op dit KiCad-10-board met `block does not start with (footprint ...)`. Dit is een toolbeperking, geen ontwerpbewijs. Volgens de gebruikersafspraak van 18 september zijn betrouwbare alternatieven zoals KiCads native API toegestaan. Maak een back-up, begrens wijzigingen tot de opdracht en controleer na opnieuw laden de bedoelde wijziging en het behoud van overige ontwerpgegevens; gebruik geen blinde hergeneratie als workaround.
- Let op: `kicad-tool pcb drc` roept KiCad aan met `--refill-zones --save-board`; de controle van 17 september heeft daardoor zones opnieuw gevuld en de PCB-hash gewijzigd naar `979001498ecc9217cee7c8b02d6a73fc7c589d4343fa0a0866a73a7a9f0731f2`, zonder componentplaatsing of handmatige power/GND-layoutwijziging. Gebruik voortaan een werkkopie voor DRC.
- Een actieve KiCad-lock betekent: niet schrijven totdat de gebruiker/editor gesloten is en de actuele bestanden opnieuw zijn gecontroleerd.

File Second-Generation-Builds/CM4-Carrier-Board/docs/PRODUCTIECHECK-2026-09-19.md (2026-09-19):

# CM4-MANET v0.11 — productiecheck en correctielijst

Datum: 19 september 2026  
Status: **NIET PRODUCTIERIJP — NIET BESTELLEN**

## 1. Geldigheid van deze controle

Deze controle geldt voor de nieuwste aantoonbaar opgeslagen en gesynchroniseerde versie die tijdens de audit beschikbaar was.

| Bestand | SHA-256 |
|---|---|
| `CM4_MANET.kicad_pro` | `29031d407538b3dbcb6472aa7c64797e4d6ba71f1556e2ef84310c6bf45d1d5d` |
| `CM4_MANET.kicad_sch` | `d8fc85620186ded0c0d289be1d9e3905773756102ce121de9318bc477c56a758` |
| `CM4_MANET.kicad_pcb` | `218439d0e7e71eeba17b0bce05ddc644826dbbb2ce876aa322ecba9a2478592e` |

Bewijs voor de syncstatus:

- de Nextcloud-client draaide en bereikte de `Codex`-map succesvol;
- de lokale Nextcloud-syncdatabase vermeldde voor de PCB dezelfde mtime als het lokale bestand: `2026-09-19 12:25:02 UTC`;
- voor de PCB stond geen pending upload/download/conflict geregistreerd;
- bij aanvang waren geen KiCad-locks aanwezig;
- bron en auditkopie hadden identieke hashes;
- na de controles waren alle drie bronhashes nog onveranderd.

Na afloop verscheen tijdelijk opnieuw een KiCad-lock. Voor deze GitHub-snapshot is KiCad vervolgens opgeslagen en gesloten; een nieuwe stabiliteitscontrole bevestigde dat de drie bronhashes gelijk bleven aan de hierboven genoemde baseline.

Alle ERC/DRC- en exporthandelingen zijn op een tijdelijke werkkopie uitgevoerd. De KiCad-bronnen zijn niet door deze audit gewijzigd.

## 2. Korte conclusie

Er is duidelijke vooruitgang ten opzichte van 18 september:

- onverbonden items: **65 → 37**;
- tracks: **1578 → 1791**;
- via's: **321 → 399**;
- GND-opens bij `D500`, `D501` en `J400` zijn niet meer aanwezig;
- schema↔PCB-pariteit blijft schoon: **0 meldingen**;
- alle beoordeelde USB-, PCIe- en Ethernetparen zijn gerouteerd en hebben symmetrische P/N-via-aantallen.

De vrijgave blijft geblokkeerd door twee ERC-fouten, 37 GND-opens, twee dangling via's, twee geïsoleerde `+3V3_AUX`-kopereilanden, niet-afgeronde Ethernet-/retourpad-/powercontrole en verouderde productie-uitvoer.

# 3. Correctielijst

## P0 — eerst oplossen; harde productieblokkers

### [ ] P0.1 — Schema: `U100 pin 2 [GND]` correct verbinden

Verse ERC: **2 errors, 0 warnings**.

Beide fouten staan op `/04 CM4 Power GPIO/`, `(161,29 mm, 44,45 mm)`:

1. `pin_not_connected` — `U100 Pin 2 [GND, Power input]`;
2. `power_pin_not_driven` — dezelfde GND-power-inputpin wordt niet door een power-output gevoed.

**Correctie:** verbind de pin aantoonbaar met GND en gebruik zo nodig een correcte `PWR_FLAG`/powertype-oplossing. Onderdruk deze controle niet zonder elektrische onderbouwing.

### [ ] P0.2 — PCB: alle 37 GND-unconnected items oplossen

Verse DRC: **37 unconnected items**, allemaal net `GND`. Dit zijn geen 37 verschillende componentpinnen maar de door KiCad berekende ontbrekende verbindingen tussen één verzameling losse GND-eilanden.

Aangetoonde losse eindpunten:

- `U100`: 30 unieke GND-pads:
  - oneven rij: `107, 113, 119, 125, 131, 137, 155, 161, 167, 173, 179, 185, 191, 197`;
  - even rij: `108, 114, 120, 126, 132, 138, 144, 150, 156, 162, 168, 174, 180, 186, 192, 198`;
- `U120.2 [GND]` rond `(146,825; 108,825)`;
- `U20.15 [GND]` rond `(160,158; 100,645)`;
- verbinding tussen de multilayer-GND-zone en `GND_In4.Cu_1` ontbreekt.

**Correctie:**

1. controleer na zone-refill welke U100-padgroepen werkelijk geen planecontact hebben;
2. verbind beide CM4-connectorrijen met voldoende lokale GND-via's naar de referentielagen;
3. verbind `U120.2` en `U20.15` direct en kort met het GND-net;
4. verbind de In4-GND-zone met de overige GND-zones;
5. refill alle zones en herhaal DRC totdat `unconnected_items = 0`.

### [ ] P0.3 — Twee dangling via's herstellen of verwijderen

- `BAT_POS` via op `(176,500; 76,125)`;
- `CM4_nRPIBOOT` via op `(127,825; 79,875)`.

**Correctie:** sluit beide via's op de bedoelde tweede laag aan of verwijder ze wanneer zij geen functie hebben. Controleer bij `BAT_POS` daarna opnieuw stroompad en koperdoorsnede.

### [ ] P0.4 — Twee geïsoleerde `+3V3_AUX`-kopereilanden oplossen

DRC meldt tweemaal `isolated_copper` in de `+3V3_AUX`-zone op `In3.Cu` (zoneanker `(110,975; 97,300)`).

**Correctie:** refill en inspecteer de volledige zone. Verwijder niet-functionele eilanden of verbind bedoelde eilanden met voldoende koper/via's. Controleer daarna dat er geen smalle nek of onbedoeld afgesneden voedingsgebied overblijft.

### [ ] P0.5 — Actuele fabricagebestanden maken; huidige pakket niet gebruiken

De bestaande outputs zijn ouder dan de gecontroleerde PCB:

- actuele PCB: `2026-09-19 12:25 UTC`;
- bestaande Gerbers/drills: `2026-09-17`;
- offerte-BOM/CPL: `2026-09-17`;
- STEP: `2026-09-16`;
- sourcing-audit: `2026-09-15`.

Vergelijking drillbestanden:

| Bestand | Bestaand | Vers uit actuele PCB |
|---|---:|---:|
| PTH-hits | 310 | 411 |
| NPTH-hits | 6 | 6 |

De actuele PTH-set bevat 106 nieuwe en mist 5 oude boorlocaties ten opzichte van het bestaande bestand. **Het oude fabricagepakket mag niet worden besteld.**

**Correctie:** pas na alle elektrische/layoutcorrecties opnieuw Gerbers, drills, BOM, CPL, jobfile en STEP exporteren en onafhankelijk in een viewer/importcontrole beoordelen.

### [ ] P0.6 — Ontwerpbesluit voor `U200.20` formeel sluiten

De verse netlist bevat nog:

`unconnected-(U200-PRTPWR4{slash}BC_EN4-Pad20)`.

De slash-escaping werkt, maar de USB2514B-pin is nog een expliciet unconnected net zonder gesloten productieargument.

**Correctie:** controleer de bedoelde functie tegen de USB2514B-configuratie. Markeer de pin aantoonbaar als bewust NC wanneer dat correct is, of sluit hem volgens het gekozen hub-/battery-chargingbeleid aan.

## P1 — SI/PI, layout en reproduceerbaarheid

### [ ] P1.1 — Ethernet kabelzijde aan de juiste impedantieklasse koppelen

De projectconfiguratie koppelt alleen `ETH0_?` t/m `ETH3_?` aan `ETH_100ohm_3313`:

- bedoelde klasse: width `0,10414 mm`, gap `0,1524 mm`;
- `ETH_C0_?` t/m `ETH_C3_?` ontbreekt in de netclass-patterns;
- alle kabelzijdetracks gebruiken daardoor nog `0,200 mm`.

Ook `ETH3_P/N` bevat naast `0,10414 mm` nog een segment van `0,200 mm`.

**Correctie:** voeg `ETH_C0_?` t/m `ETH_C3_?` aan de 100-ohmklasse toe, verwijder de afwijkende `ETH3`-breedte en routeer/refill opnieuw. Laat de uiteindelijke geometrie bevestigen tegen de definitieve JLC06161H-3313-stackup; een naam of trackbreedte alleen bewijst geen 100 Ω.

### [ ] P1.2 — Nabije GND-retourvia's bij alle kritieke laagwissels afwerken

Na de verbeteringen zijn er meer GND-via's, maar meerdere kritieke via's liggen nog meer dan 1 mm van de dichtstbijzijnde GND-via.

Belangrijkste resterende afstanden:

- PCIe TX: circa `9,1–9,7 mm`;
- PCIe RX: circa `6,0–6,3 mm`;
- PCIe CLK: circa `1,5–1,8 mm`;
- HaLow USB: circa `2,6–4,4 mm`;
- Ethernet PHY-zijde: veelal `2,3–5,3 mm`;
- Ethernet kabelzijde: circa `1,5–6,0 mm`;
- externe USB-paren: enkele overgangen circa `1,4–2,9 mm`.

**Correctie:** plaats per P/N-laagwissel een nabije GND-retourvia of compact via-paar zonder het differentiële pad te verstoren. Controleer dat de gebruikte referentielaag continu blijft.

### [ ] P1.3 — U100-footprint/library-afwijking bewust sluiten

DRC: `U100` footprint `Raspberry-Pi-4-Compute-Module` wijkt af van de actuele kopie in library `MANET`.

**Correctie:** vergelijk pads, connectorafstand, courtyard, modellen en pinmapping. Kies daarna bewust één gevalideerde versie en update óf footprint óf library. Niet blind “update from library”.

### [ ] P1.4 — Strikte footprintmeldingen beoordelen

- `J120`: footprinttype verwacht SMD maar bevat through-hole-pads;
- ontbrekende courtyards: `J1`, `J110`, `J111`.

**Correctie:** zet voor `J120` het juiste footprinttype of motiveer de hybride constructie. Voeg realistische courtyards toe aan de drie connectoren/soldeerinterfaces.

### [ ] P1.5 — Voedingsdimensionering en thermiek aantoonbaar sluiten

De boarddata bevat voor `BAT_POS`, `+5V_MAIN`, `+3V3_WIFI`, `+3V3_AUX` en `+3V3_HALOW` veel 0,2-mm-segmenten naast zones. Uit alleen de layoutdata is niet bewezen dat halsjes, via's, connectorpads en planes de gecombineerde AW7916 + HaLow + USB-belasting dragen.

**Correctie:** maak per rail een stroomtabel en controleer minimaal:

- maximale continue en piekstroom;
- smalste effectieve koperdoorsnede;
- aantal/diameter van stroomvia's;
- spanningsval door sporen, connectoren en zekeringen/switches;
- temperatuurstijging van koper, U10/U20 en Pololu-aansluiting;
- retourpad naar de voedingsbron.

### [ ] P1.6 — BOM/CPL-varianten reproduceerbaar maken

De actuele ruwe exports bevatten 122 schema-/PCB-referenties. Het offertepakket bevat 106 BOM- en 106 CPL-referenties. Voor de 104 gemeenschappelijke CPL-referenties zijn positie, zijde en rotatie nog gelijk, maar de omzetting is handmatig en niet reproduceerbaar uit de huidige bronvelden.

Actuele bron-POS maar niet in offerte-CPL:

`C305, C306, J1, J110, J111, PS1, R501, TP1, TP2, TP3, TP10, TP20, TP110, TP111, TP112, TP113, TP260, U100`.

Offerte-CPL maar niet als afzonderlijke actuele footprintreferentie:

`J100, J101` — de twee fysieke CM4-Hirose-connectoren zijn in `U100` gecombineerd.

**Correctie:**

1. leg in KiCad of in een gecontroleerd exportscript exact vast wat JLC plaatst;
2. sluit CM4, AW7916 en Pololu expliciet uit;
3. leg MM8108-geplaatst en MM8108-DNP/Lunpid als twee varianten vast;
4. documenteer hoe `U100` naar twee echte `J100/J101`-plaatsingsregels wordt omgezet;
5. zorg dat DNP/testpunten/handmontage niet per ongeluk in de upload-CPL belanden.

### [ ] P1.7 — Ontbrekende productievelden aanvullen

In de ruwe schema-BOM missen `Manufacturer`, `MPN` en `LCSC` bij 19 referenties. Een deel is bewust DNP, testpunt of handmontage; dat moet expliciet worden vastgelegd. Productierelevant:

- `T500`: waarde noemt `C2904710`, maar de eigen Manufacturer/MPN/LCSC-velden zijn leeg;
- `J1`, `J110`, `J111`: geen volledige partgegevens;
- `PS1`, `U100`: handmontage maar niet expliciet uitgesloten in de geëxporteerde velden;
- `C305`, `C306`: DNP is ingevuld, maar variantbeleid moet in de export worden toegepast;
- `R501`: part-/plaatsingsstatus expliciet vastleggen.

### [ ] P1.8 — Sourcing opnieuw uitvoeren

De sourcing-audit is ouder dan de Ethernetwijzigingen. De eerdere audit:

- bevat geen volledige actuele controle van `T500/C501/C502/R502–R505`;
- bevat nog de obsolete referentie `C900`;
- meldt voor MM8108 `NO_PROVEN_IN_STOCK_REPLACEMENT` en voorraad 0.

**Correctie:** voer na variantkeuze een nieuwe sourcingrun uit voor exact vijf boards plus reserve, met actuele prijs, voorraad, lifecycle en JLC assembly availability.

### [ ] P1.9 — JLC-assemblagemodus expliciet vastleggen

De actuele plaatsingsdata bevat bottom-side onderdelen `C221`, `C241`, `J400` en `T500`.

**Correctie:** gebruik bij JLCPCB een proces dat tweezijdige assemblage ondersteunt, zoals Standard; Economic/top-only is niet passend. Leg handmontage en uitgesloten onderdelen apart vast.

## P2 — 3D, mechanica en documentkwaliteit

### [ ] P2.1 — Ontbrekende en defecte 3D-modellen herstellen

Actuele telling:

- 122 footprints;
- 108 modelkoppelingen;
- 15 footprints zonder model.

Mechanisch belangrijke footprints zonder model:

- `PS1` Pololu;
- `U300` MM8108;
- `J1`, `J110`, `J111`;
- overige ontbrekende modellen zijn testpunten.

Daarnaast verwijst `L20` naar het niet-bestaande bestand:

`${KICAD10_3DMODEL_DIR}/Inductor_SMD.3dshapes/L_Coilcraft_XxL4020.step`.

Het bestaande `CM4_MANET.step` is 12.333.077 bytes met SHA-256 `d503ca9c…e045695`. Een verse export uit de gecontroleerde PCB produceerde 13.377.988 bytes met een andere hash. Die verse export eindigde zelf met exitcode 2 omdat vier lokale WRL-modellen niet betrouwbaar naar STEP konden worden omgezet. Zowel het oude STEP-bestand als deze tijdelijke export is daarom onvoldoende voor mechanische vrijgave.

De actuele top- en bottom-render konden worden gemaakt en tonen geen evidente botsing of onderdeel buiten de bordrand. Door de ontbrekende hoofdmodellen is dit echter geen volledige mechanische vrijgave.

### [ ] P2.2 — Mechanische interfaces definitief meten

Boardoutline: rechthoek circa `76,0 × 56,0 mm`.

**Nog te sluiten:** connector-envelope en kabelrichting, PS1-hoogte, MM8108-envelope/RF-pigtail, AW7916-kaartregistratie, CM4-standoff/onderdelen, montagegatvrijloop en behuizingsreferentie. Controleer deze met actuele modellen of fabrikanttekeningen.

### [ ] P2.3 — Schema leesbaarheid opschonen

De schema-inspectie vond geen nieuwe elektrische ERC-fouten buiten `U100 pin 2`, maar wel leesbaarheidsproblemen:

- op HaLow RF overlappen onder andere waarde-/referentieteksten rond `C303/C307/C308/C309`;
- op het Ethernetblad raken center-taplabels zoals `ETH_C0_CT…ETH_C3_CT` en `ETH_PHY_CT` pin-/draadteksten; de verbinding zelf is normaal, maar de tekst is moeilijk leesbaar.

Dit is geen elektrische blocker, wel aanbevolen documentatiecorrectie.

# 4. Gemeten kritieke paren

Alle onderstaande P/N-paren hebben symmetrische via-aantallen. Lengtes zijn geometrische spoorlengtes uit de PCB, geen volledige package-/connectorvertraging.

| Paar | P/N-lengte mm | Skew mm | Via's P/N | Breedte mm |
|---|---:|---:|---:|---:|
| CM4 USB | 16,459 / 16,836 | 0,377 | 2 / 2 | 0,135636 |
| USB-A | 66,170 / 66,301 | 0,131 | 2 / 2 | 0,135636 |
| USB-B | 47,289 / 47,428 | 0,139 | 2 / 2 | 0,135636 |
| HaLow USB | 54,539 / 54,620 | 0,081 | 2 / 2 | 0,135636 |
| PCIe TX | 37,811 / 37,942 | 0,131 | 1 / 1 | 0,135636 |
| PCIe RX | 33,134 / 33,265 | 0,131 | 1 / 1 | 0,135636 |
| PCIe CLK | 39,594 / 39,721 | 0,128 | 1 / 1 | 0,135636 |
| ETH0 | 31,156 / 31,006 | 0,150 | 2 / 2 | 0,10414 |
| ETH1 | 25,481 / 25,648 | 0,167 | 2 / 2 | 0,10414 |
| ETH2 | 24,367 / 24,310 | 0,058 | 2 / 2 | 0,10414 |
| ETH3 | 14,313 / 14,228 | 0,085 | 1 / 1 | 0,10414 + afwijkend 0,2-segment |
| ETH_C0 | 7,272 / 7,107 | 0,166 | 1 / 1 | 0,2 |
| ETH_C1 | 7,126 / 6,960 | 0,166 | 1 / 1 | 0,2 |
| ETH_C2 | 7,040 / 6,874 | 0,166 | 1 / 1 | 0,2 |
| ETH_C3 | 7,172 / 7,006 | 0,166 | 1 / 1 | 0,2 |

Deze geometrie is nuttig als regressiebaseline, maar is geen vervanging voor een stackup-/impedantieberekening en retourpadcontrole.

# 5. Positieve bevindingen

- 17 schema-sheets, 122 componenten/footprints.
- Netlistexport succesvol.
- Schema↔PCB-pariteit: **0**.
- Geen shorts of clearancefouten gemeld.
- Geen niet-GND-unconnected items.
- `D500`, `D501` en `J400` staan niet meer in de GND-openlijst.
- USB-, PCIe- en Ethernetparen zijn gerouteerd.
- P/N-via-aantallen zijn per beoordeeld paar gelijk.
- De twee GND-referentielagen bevatten geen gewone signaalrouting; `In1.Cu` bevat alleen GND-sporen en `In4.Cu` geen tracks.
- Boardoutline is gesloten en renderbaar.
- Actuele 3D-top- en bottomrenders tonen geen evidente componentbotsing of overschrijding van de bordrand.
- De 104 plaatsingen die zowel in actuele POS als bestaande offerte-CPL voorkomen, hebben gelijke positie, zijde en rotatie.

# 6. Hercontrolevolgorde

Voer na correcties deze volgorde aan:

1. opslaan en KiCad volledig sluiten;
2. Nextcloud-sync laten afronden;
3. nieuwe hashes vastleggen;
4. ERC: doel **0 errors**;
5. zones refill;
6. standaard en strikte DRC: doel **0 onbedoelde violations en 0 unconnected items**;
7. schema↔PCB-pariteit: doel **0**;
8. netclass-, pair-, retourpad- en powerreview herhalen;
9. actuele 3D-/mechanische controle;
10. definitieve variant en sourcing sluiten;
11. verse BOM/CPL/Gerber/drill/STEP exporteren;
12. drilltelling, Gerberviewer en JLC-import onafhankelijk controleren.

Pas daarna kan opnieuw een productievrijgave worden beoordeeld.

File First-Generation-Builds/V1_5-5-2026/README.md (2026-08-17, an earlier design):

# First Generation V1

First complete large prototype.

## Visual Overview

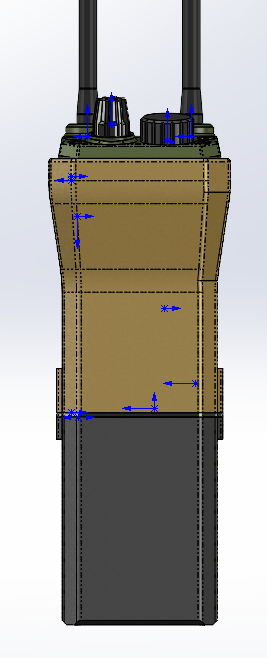
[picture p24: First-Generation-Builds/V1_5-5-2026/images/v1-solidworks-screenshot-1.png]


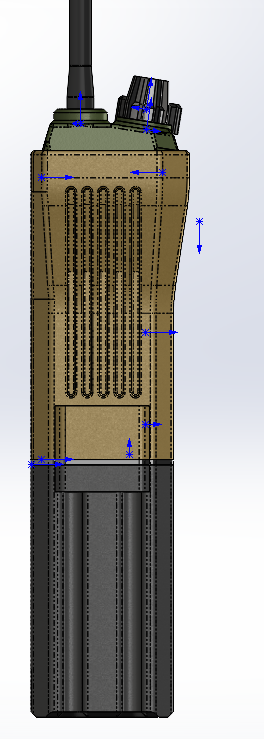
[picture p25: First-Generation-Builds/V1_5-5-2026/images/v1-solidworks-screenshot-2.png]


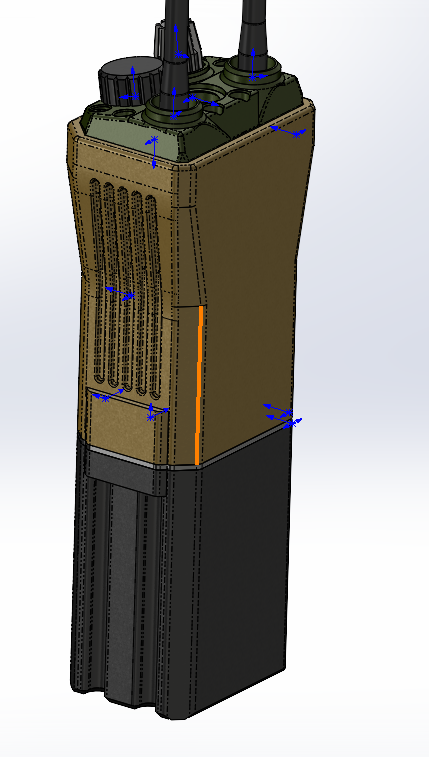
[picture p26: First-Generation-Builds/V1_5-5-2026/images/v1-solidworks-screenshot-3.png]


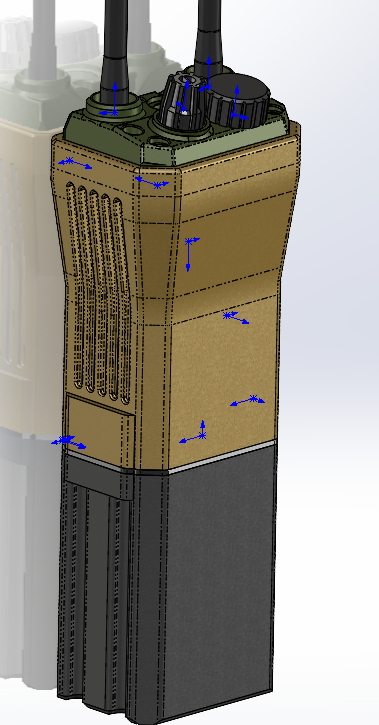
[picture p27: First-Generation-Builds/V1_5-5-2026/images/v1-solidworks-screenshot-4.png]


## Hardware

| Part | Notes |
|---|---|
| Raspberry Pi 4 | Main computer |
| WM1302 Pi HAT | Mini-PCIe adapter path |
| Seeed Studio Wio WM6108 | Wi-Fi HaLow module |
| RAK WisMesh 1W kit | Separate Meshtastic / LoRa subsystem |

## Battery

Integrated battery. The original V1 build does **not** use the twist-lock battery system. A later twist-lock add-on is included in [`Twist lock add on`](./Twist%20lock%20add%20on/).

## Files

- `3MF/` print-ready files
- `step/` STEP exports
- `Solidworks 2023/` native files
- `Solidworks 2025/` native files

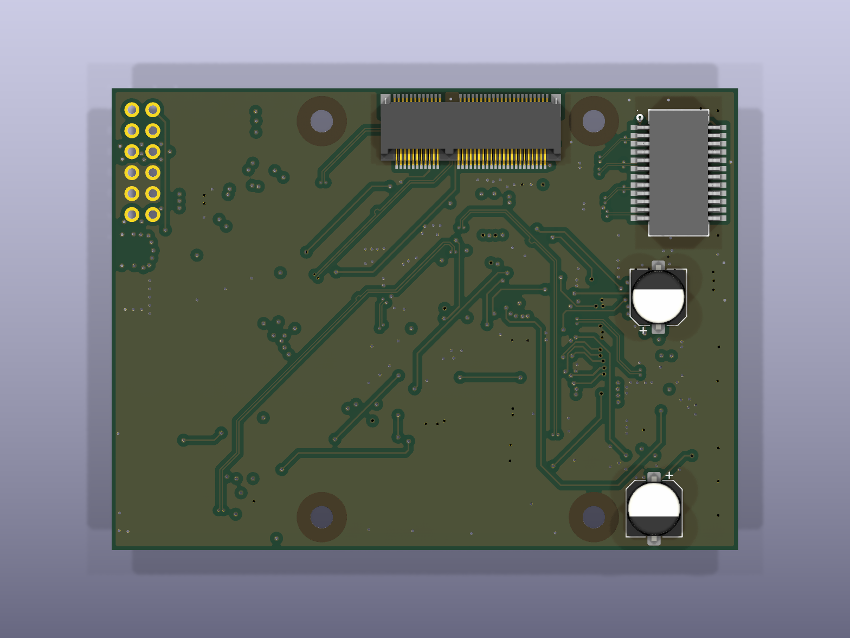
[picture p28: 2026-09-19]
Second-Generation-Builds/CM4-Carrier-Board/docs/pcb-3d-bottom.png

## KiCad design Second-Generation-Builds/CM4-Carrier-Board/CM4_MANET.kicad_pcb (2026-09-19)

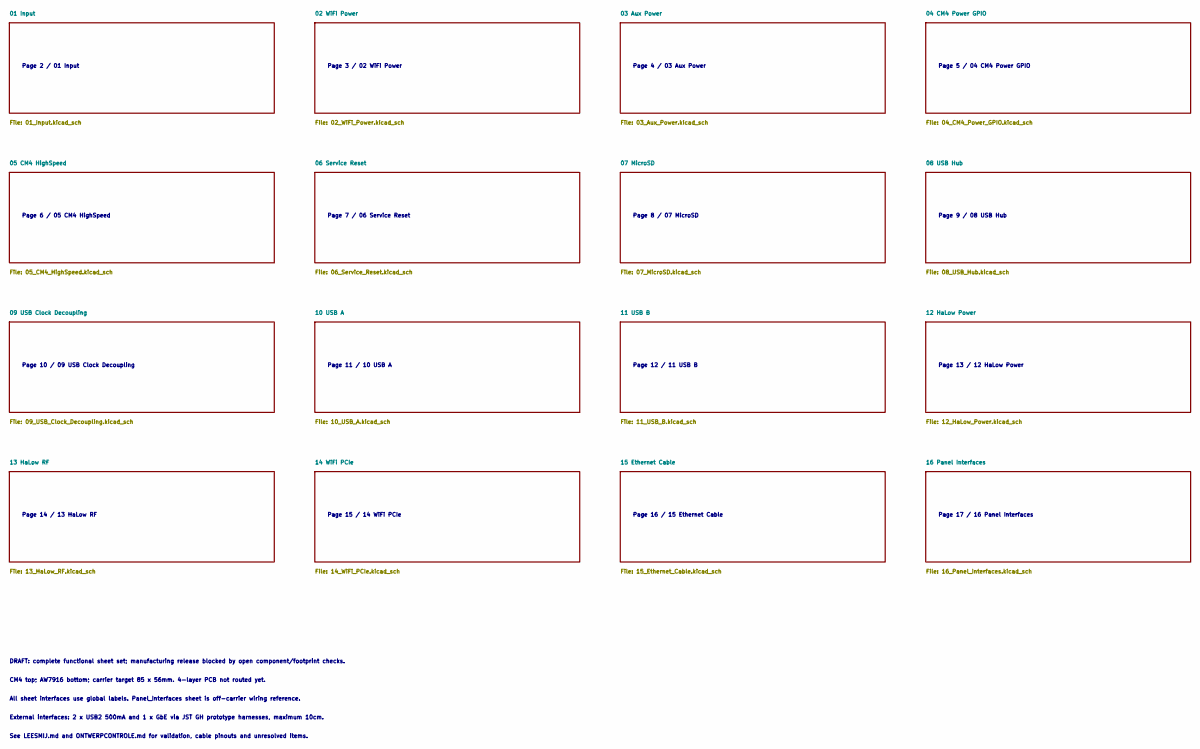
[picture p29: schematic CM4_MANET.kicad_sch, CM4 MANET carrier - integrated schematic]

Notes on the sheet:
DRAFT: complete functional sheet set; manufacturing release blocked by open component/footprint checks.
Page 11 / 10 USB A
CM4 top; AW7916 bottom; carrier target 85 x 56mm. 4-layer PCB not routed yet.
Page 4 / 03 Aux Power
Page 16 / 15 Ethernet Cable
Page 8 / 07 MicroSD
Page 5 / 04 CM4 Power GPIO
Page 15 / 14 WiFi PCIe
Page 12 / 11 USB B
Page 9 / 08 USB Hub
Page 17 / 16 Panel Interfaces
Page 14 / 13 HaLow RF
External interfaces: 2 x USB2 500mA and 1 x GbE via JST GH prototype harnesses, maximum 10cm.
Page 2 / 01 Input
Page 13 / 12 HaLow Power
See LEESMIJ.md and ONTWERPCONTROLE.md for validation, cable pinouts and unresolved items.
Page 7 / 06 Service Reset
All sheet interfaces use global labels. Panel_Interfaces sheet is off-carrier wiring reference.
Page 3 / 02 WiFi Power
Page 10 / 09 USB Clock Decoupling
Page 6 / 05 CM4 HighSpeed

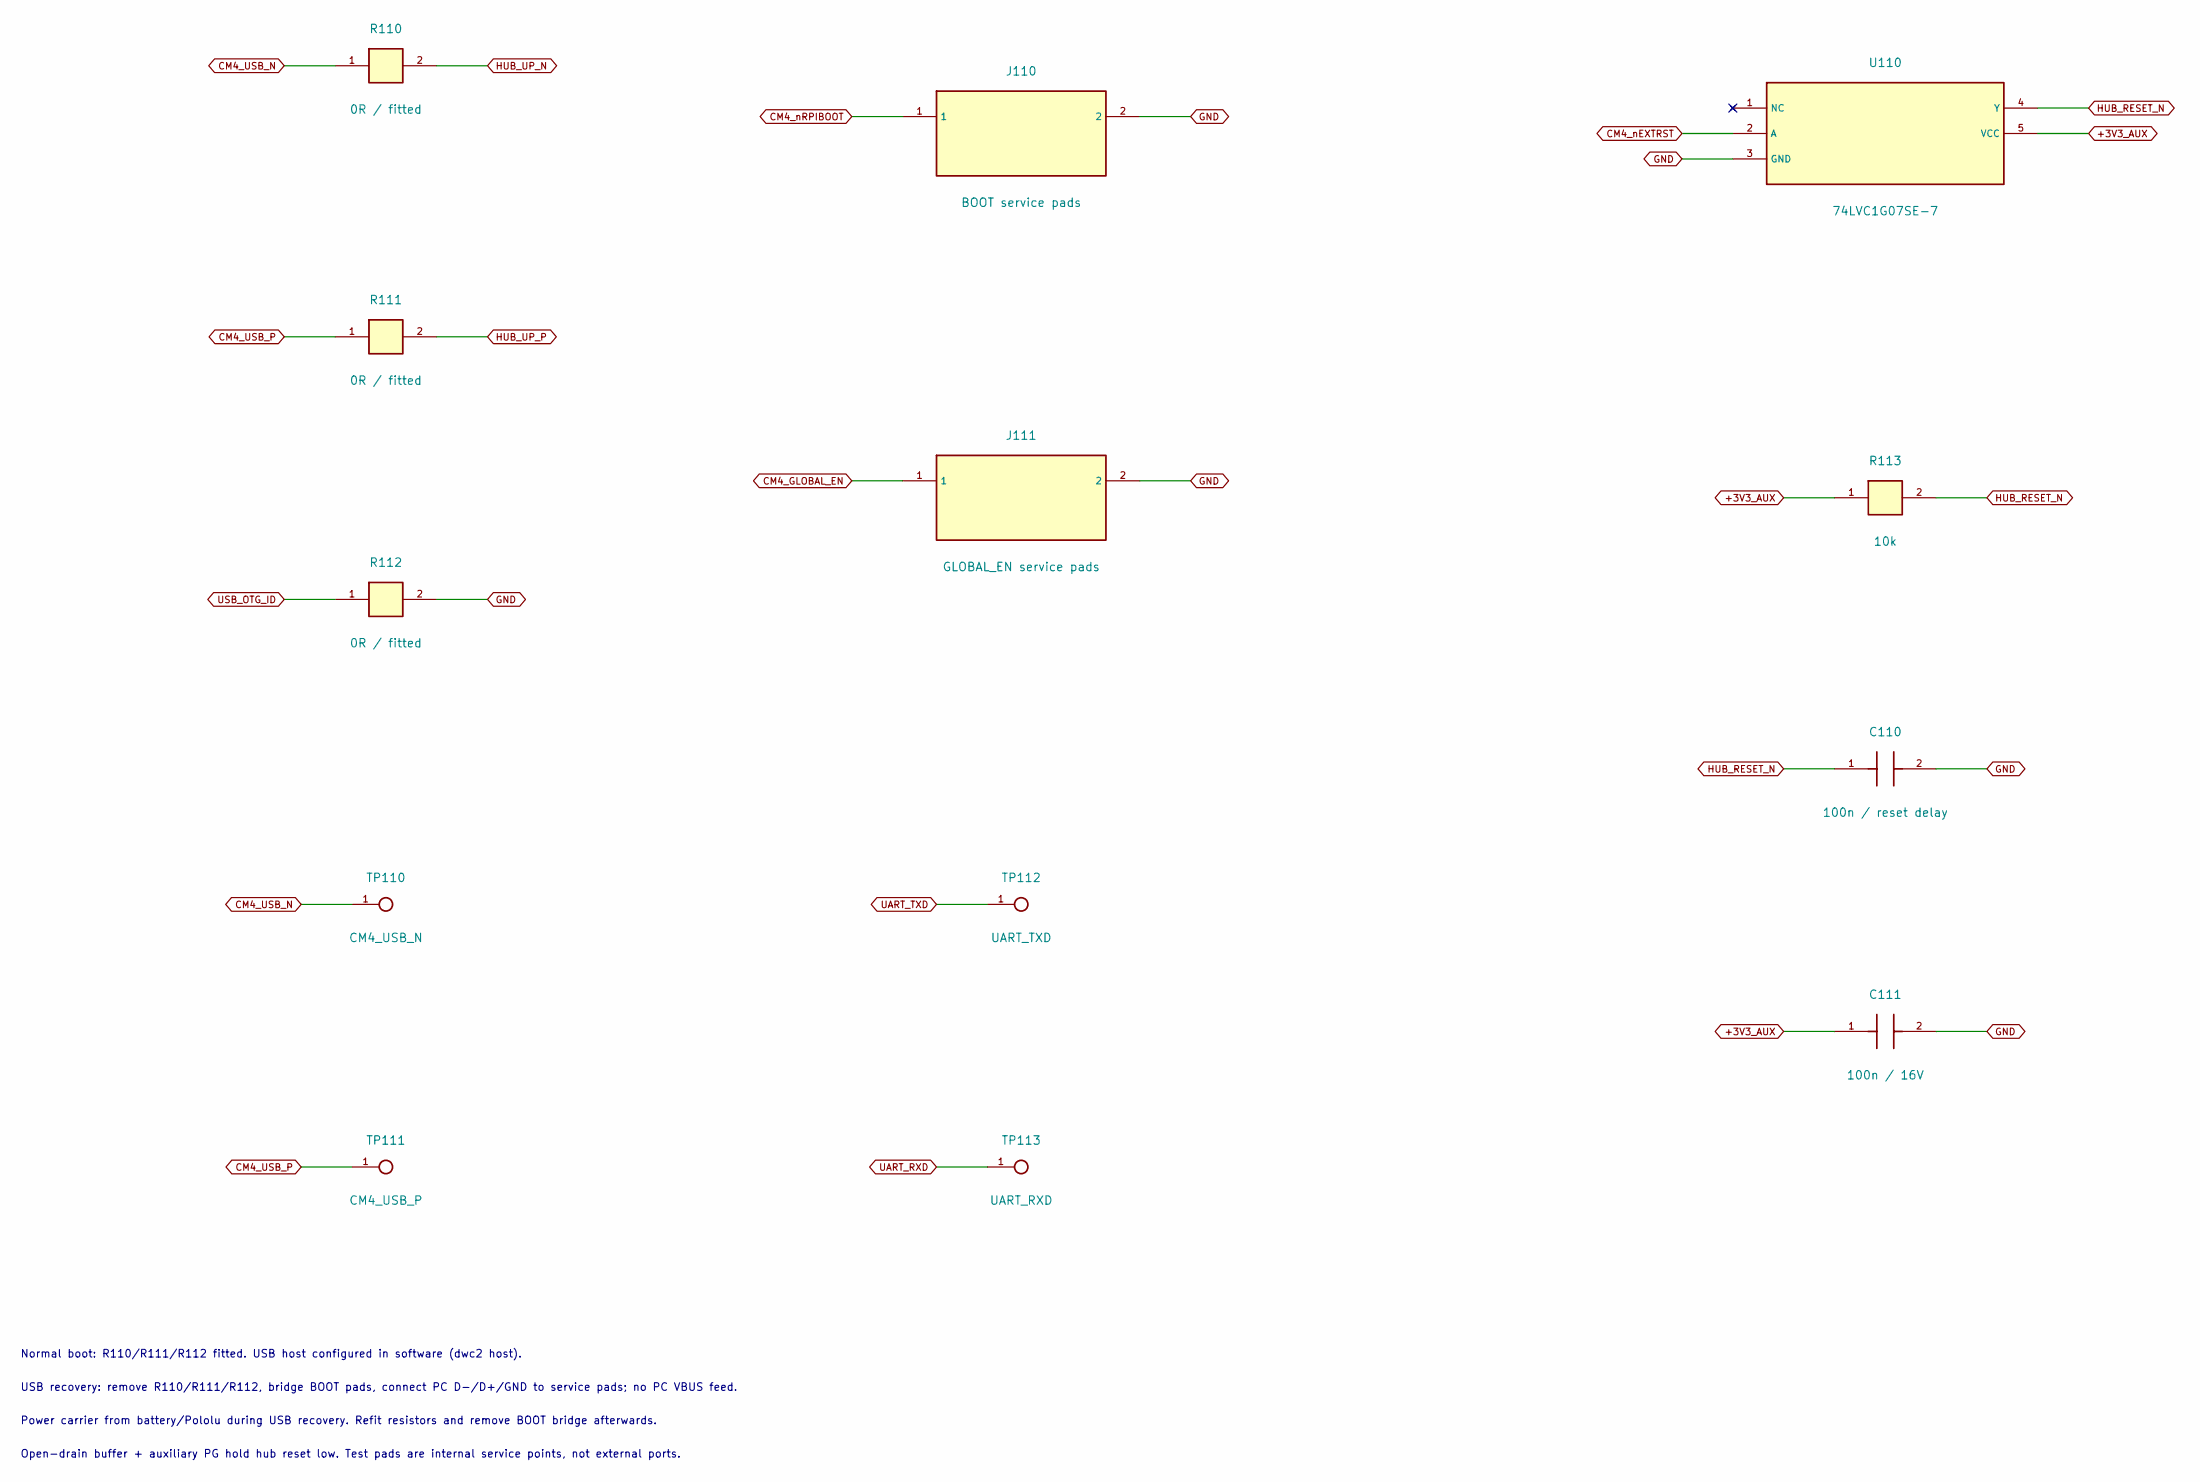
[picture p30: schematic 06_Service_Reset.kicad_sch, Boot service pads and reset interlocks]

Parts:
C110: 100n / reset delay; C_0603_1608Metric; MPN CL10B104KB8NNNC; LCSC C1591
C111: 100n / 16V; C_0603_1608Metric; MPN CL10B104KB8NNNC; LCSC C1591
J110: BOOT service pads; Service_Pads; JLCPCB Status EXCLUDE_FROM_JLCPCB_ASSEMBLY
J111: GLOBAL_EN service pads; Service_Pads; JLCPCB Status EXCLUDE_FROM_JLCPCB_ASSEMBLY
R110, R111, R112: 0R / fitted; R_0603_1608Metric; MPN 0603WAF0000T5E; LCSC C21189
R113: 10k; R_0603_1608Metric; MPN 0603WAF1002T5E; LCSC C25804
TP110: CM4_USB_N; TestPoint_Pad_D1.5mm; JLCPCB Status EXCLUDE_FROM_JLCPCB_ASSEMBLY
TP111: CM4_USB_P; TestPoint_Pad_D1.5mm; JLCPCB Status EXCLUDE_FROM_JLCPCB_ASSEMBLY
TP112: UART_TXD; TestPoint_Pad_D1.5mm; JLCPCB Status EXCLUDE_FROM_JLCPCB_ASSEMBLY
TP113: UART_RXD; TestPoint_Pad_D1.5mm; JLCPCB Status EXCLUDE_FROM_JLCPCB_ASSEMBLY
U110: 74LVC1G07SE-7; SOT-353_SC-70-5; MPN 74LVC1G07SE-7; LCSC C67531

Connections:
+3V3_AUX: C111.1, R113.1, U110.5 (VCC); also elsewhere on the board
CM4_GLOBAL_EN: J111.1; also elsewhere on the board
CM4_USB_N: R110.1, TP110.1; also elsewhere on the board
CM4_USB_P: R111.1, TP111.1; also elsewhere on the board
CM4_nEXTRST: U110.2 (A); also elsewhere on the board
CM4_nRPIBOOT: J110.1; also elsewhere on the board
GND: C110.2, C111.2, J110.2, J111.2, R112.2, U110.3 (GND); also elsewhere on the board
HUB_RESET_N: C110.1, R113.2, U110.4 (Y); also elsewhere on the board
HUB_UP_N: R110.2; also elsewhere on the board
HUB_UP_P: R111.2; also elsewhere on the board
UART_RXD: TP113.1; also elsewhere on the board
UART_TXD: TP112.1; also elsewhere on the board
USB_OTG_ID: R112.1; also elsewhere on the board

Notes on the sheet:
Open-drain buffer + auxiliary PG hold hub reset low. Test pads are internal service points, not external ports.
Normal boot: R110/R111/R112 fitted. USB host configured in software (dwc2 host).
Power carrier from battery/Pololu during USB recovery. Refit resistors and remove BOOT bridge afterwards.
USB recovery: remove R110/R111/R112, bridge BOOT pads, connect PC D-/D+/GND to service pads; no PC VBUS feed.

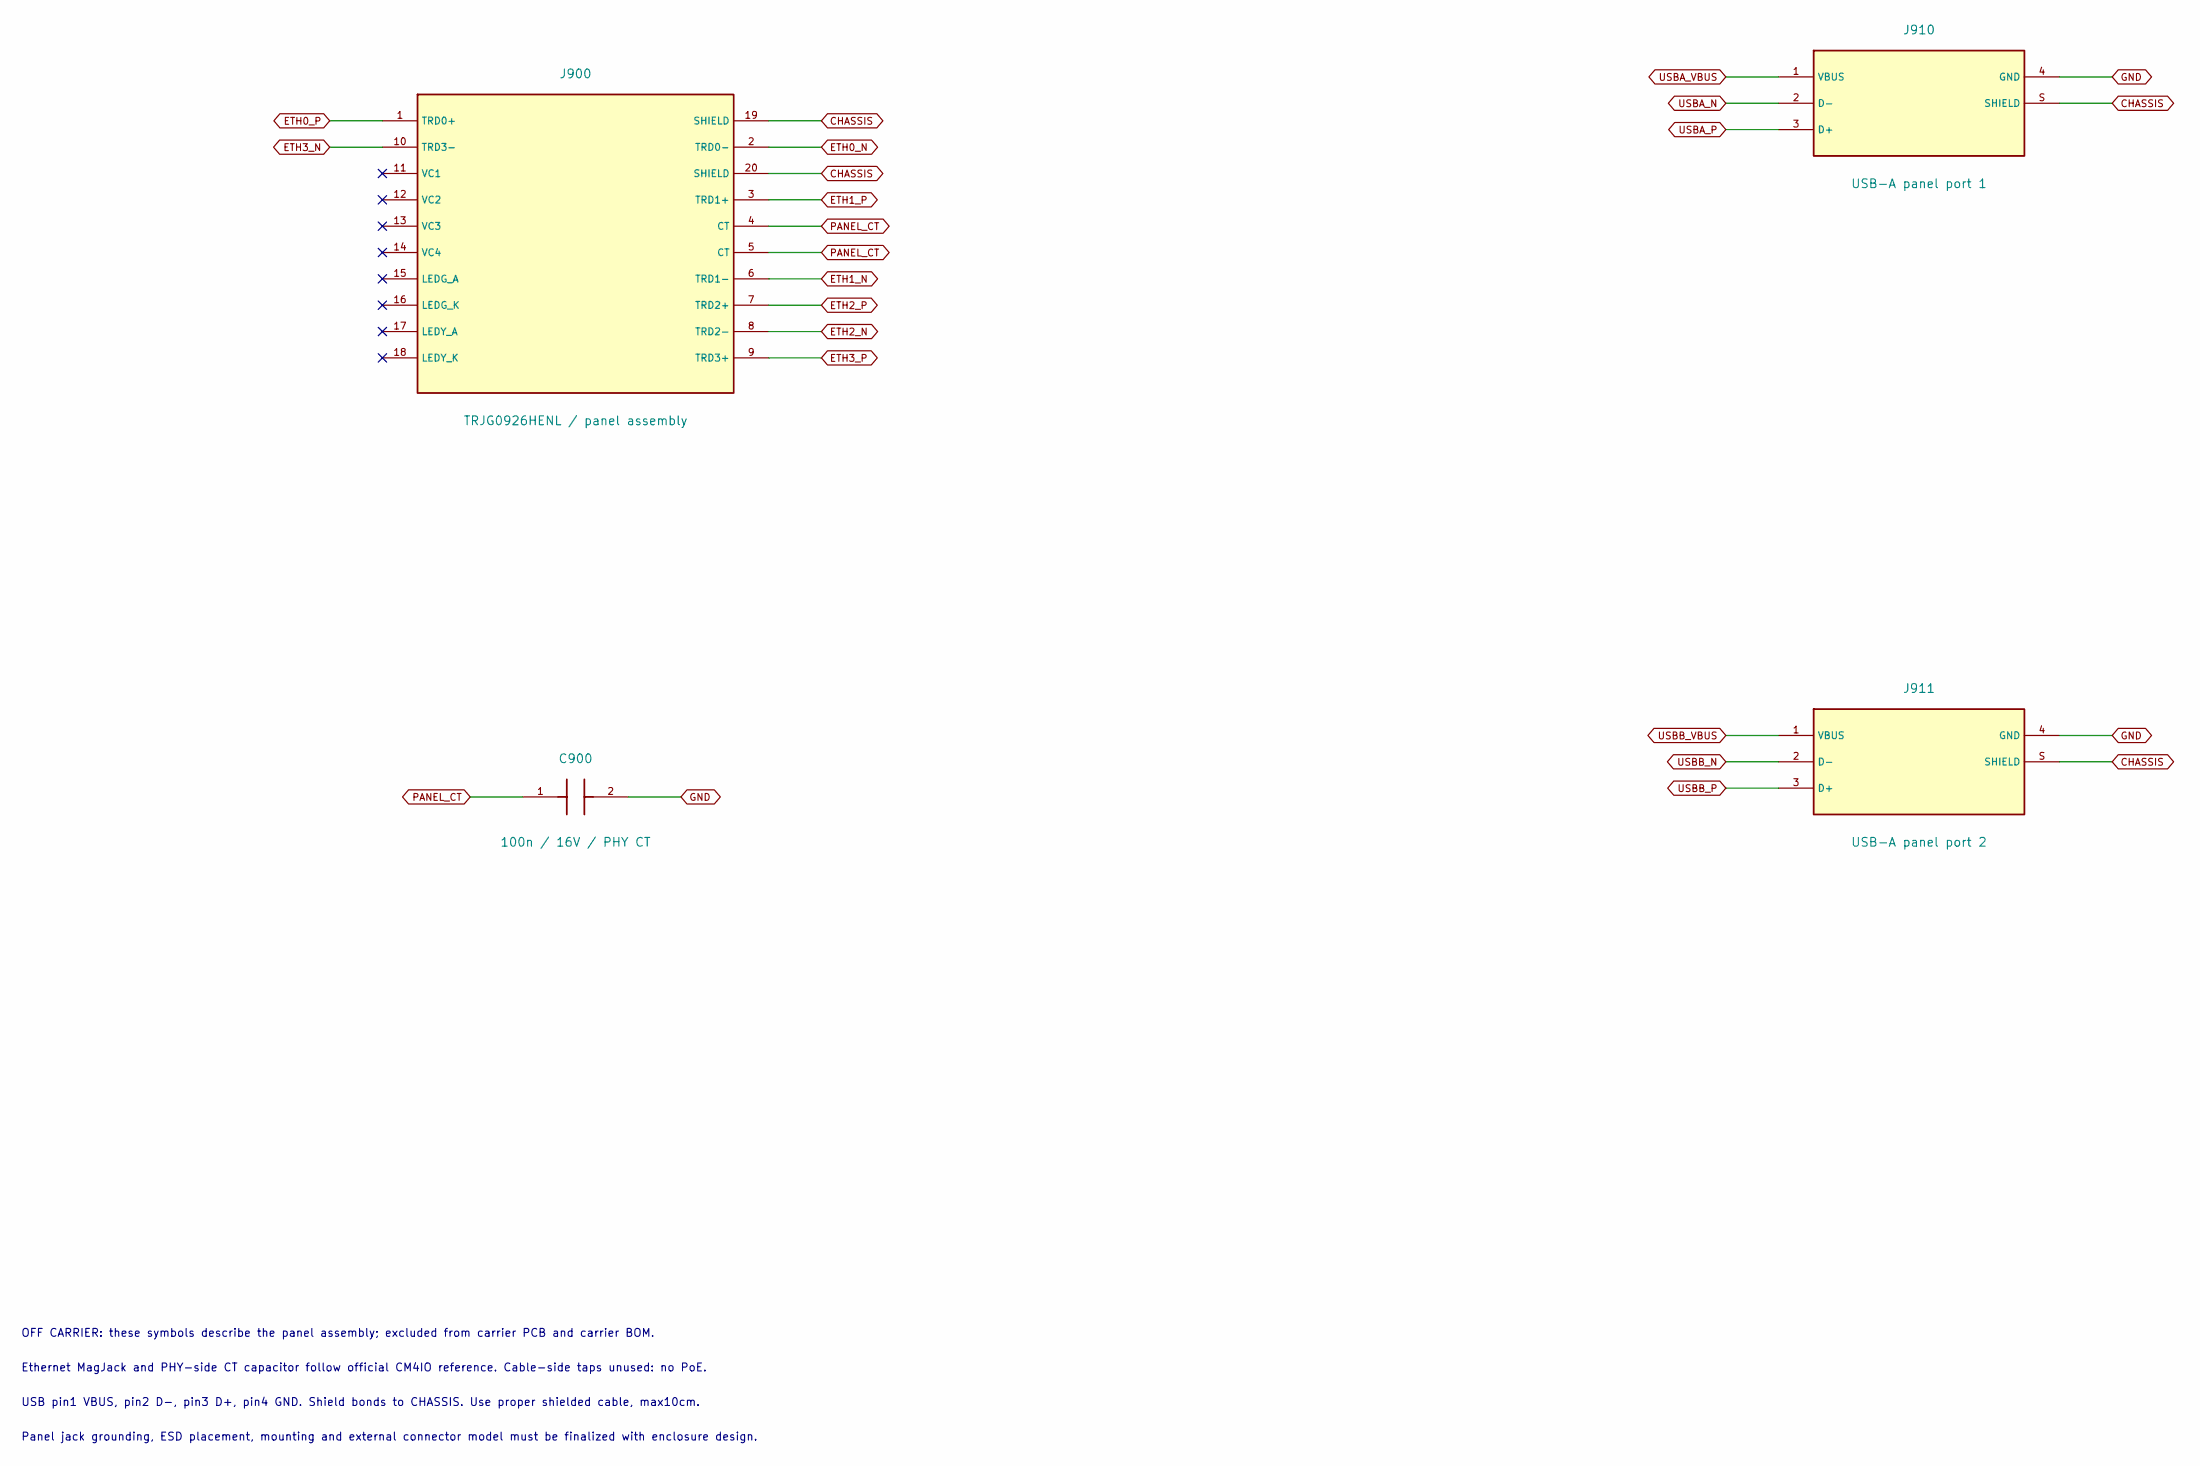
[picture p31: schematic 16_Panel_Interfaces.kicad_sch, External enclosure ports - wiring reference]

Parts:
C900: 100n / 16V / PHY CT; C_0603_1608Metric; JLCPCB Status EXCLUDE_FROM_JLCPCB_ASSEMBLY
J900: TRJG0926HENL / panel assembly; JLCPCB Status EXCLUDE_FROM_JLCPCB_ASSEMBLY
J910: USB-A panel port 1; JLCPCB Status EXCLUDE_FROM_JLCPCB_ASSEMBLY
J911: USB-A panel port 2; JLCPCB Status EXCLUDE_FROM_JLCPCB_ASSEMBLY

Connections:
unnamed: C900.1, J900.4 (CT), J900.5 (CT)
unnamed: C900.2, J910.4 (GND), J911.4 (GND)
unnamed: J900.19 (SHIELD), J900.20 (SHIELD), J910.S (SHIELD), J911.S (SHIELD)

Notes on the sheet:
Ethernet MagJack and PHY-side CT capacitor follow official CM4IO reference. Cable-side taps unused: no PoE.
Panel jack grounding, ESD placement, mounting and external connector model must be finalized with enclosure design.
USB pin1 VBUS, pin2 D-, pin3 D+, pin4 GND. Shield bonds to CHASSIS. Use proper shielded cable, max10cm.
OFF CARRIER: these symbols describe the panel assembly; excluded from carrier PCB and carrier BOM.

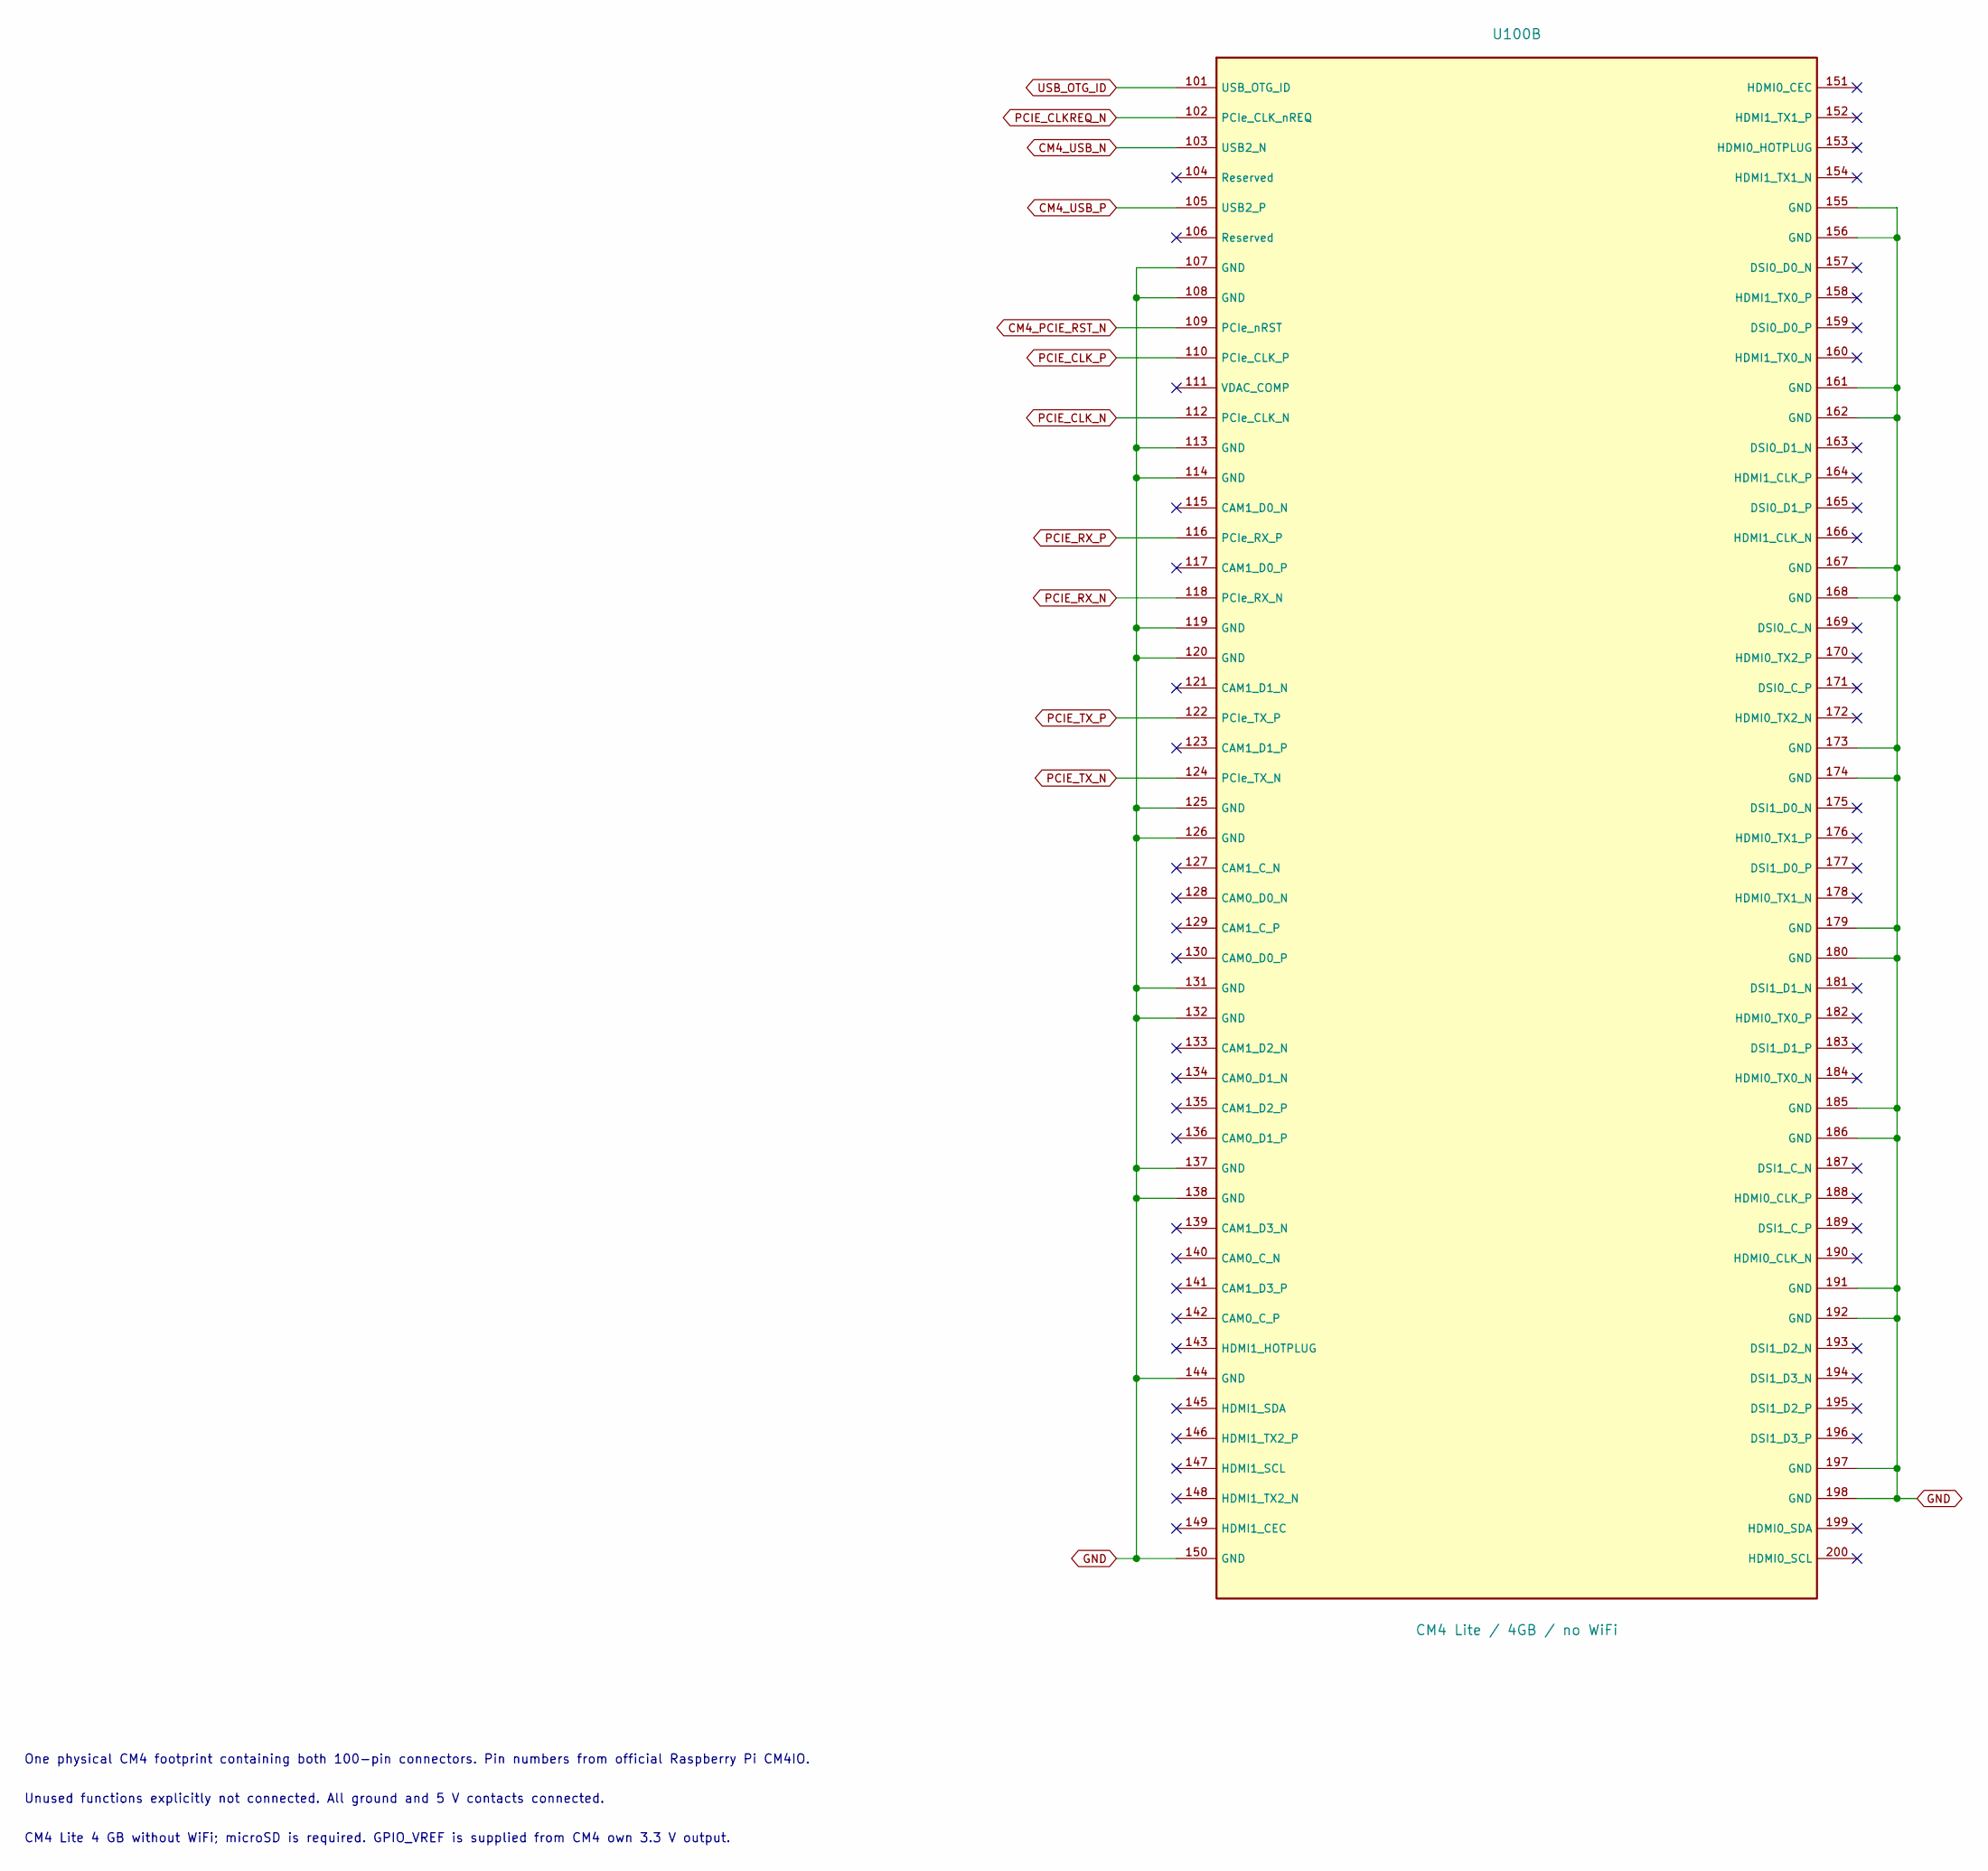
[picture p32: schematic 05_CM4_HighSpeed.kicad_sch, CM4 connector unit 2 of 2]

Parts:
U100: CM4 Lite / 4GB / no WiFi; Raspberry-Pi-4-Compute-Module; JLCPCB Status EXCLUDE_FROM_JLCPCB_ASSEMBLY

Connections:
CM4_PCIE_RST_N: U100.109 (PCIe_nRST); also elsewhere on the board
CM4_USB_N: U100.103 (USB2_N); also elsewhere on the board
CM4_USB_P: U100.105 (USB2_P); also elsewhere on the board
GND: U100.107 (GND), U100.108 (GND), U100.113 (GND), U100.114 (GND), U100.119 (GND), U100.120 (GND), U100.125 (GND), U100.126 (GND), U100.131 (GND), U100.132 (GND), U100.137 (GND), U100.138 (GND), U100.144 (GND), U100.150 (GND), U100.155 (GND), U100.156 (GND), U100.161 (GND), U100.162 (GND), U100.167 (GND), U100.168 (GND), U100.173 (GND), U100.174 (GND), U100.179 (GND), U100.180 (GND), U100.185 (GND), U100.186 (GND), U100.191 (GND), U100.192 (GND), U100.197 (GND), U100.198 (GND); also elsewhere on the board
PCIE_CLKREQ_N: U100.102 (PCIe_CLK_nREQ); also elsewhere on the board
PCIE_CLK_N: U100.112 (PCIe_CLK_N); also elsewhere on the board
PCIE_CLK_P: U100.110 (PCIe_CLK_P); also elsewhere on the board
PCIE_RX_N: U100.118 (PCIe_RX_N); also elsewhere on the board
PCIE_RX_P: U100.116 (PCIe_RX_P); also elsewhere on the board
PCIE_TX_N: U100.124 (PCIe_TX_N); also elsewhere on the board
PCIE_TX_P: U100.122 (PCIe_TX_P); also elsewhere on the board
USB_OTG_ID: U100.101 (USB_OTG_ID); also elsewhere on the board

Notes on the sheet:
One physical CM4 footprint containing both 100-pin connectors. Pin numbers from official Raspberry Pi CM4IO.
CM4 Lite 4 GB without WiFi; microSD is required. GPIO_VREF is supplied from CM4 own 3.3 V output.
Unused functions explicitly not connected. All ground and 5 V contacts connected.

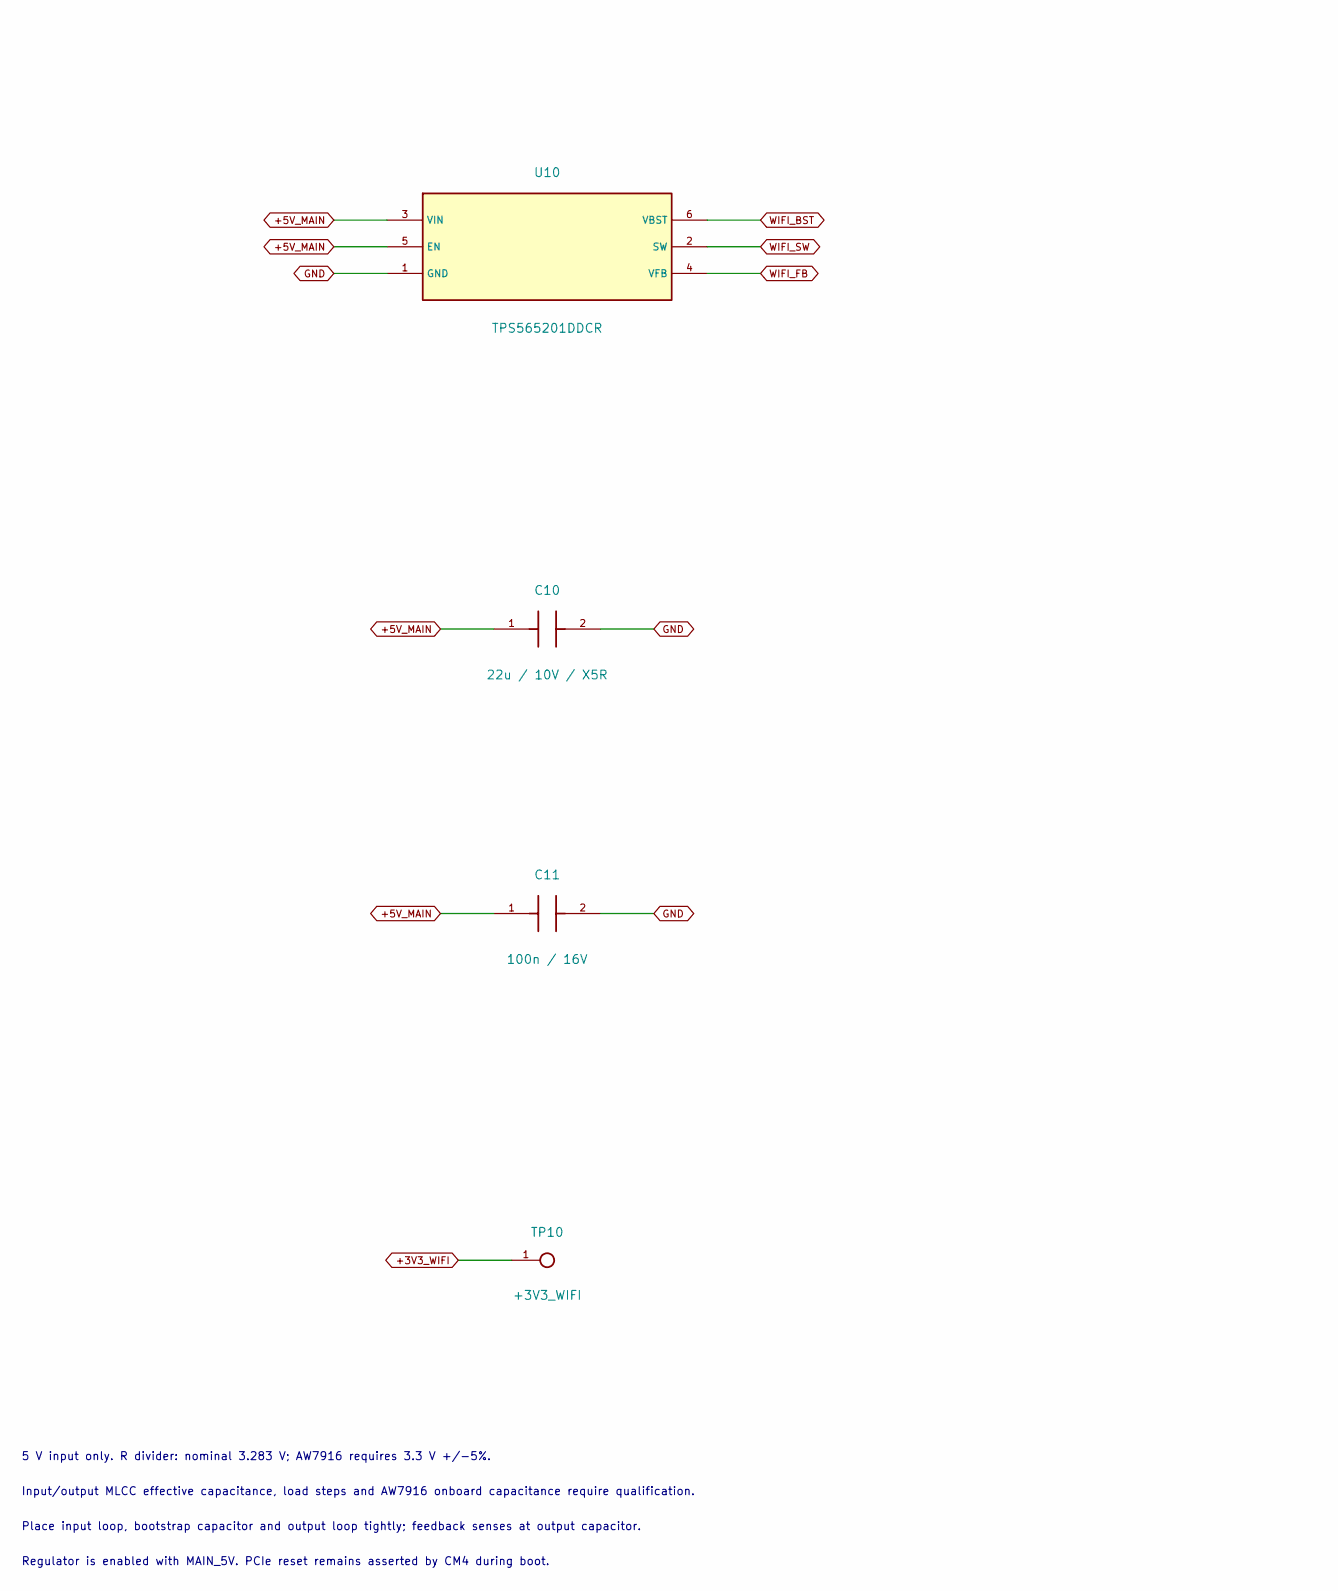
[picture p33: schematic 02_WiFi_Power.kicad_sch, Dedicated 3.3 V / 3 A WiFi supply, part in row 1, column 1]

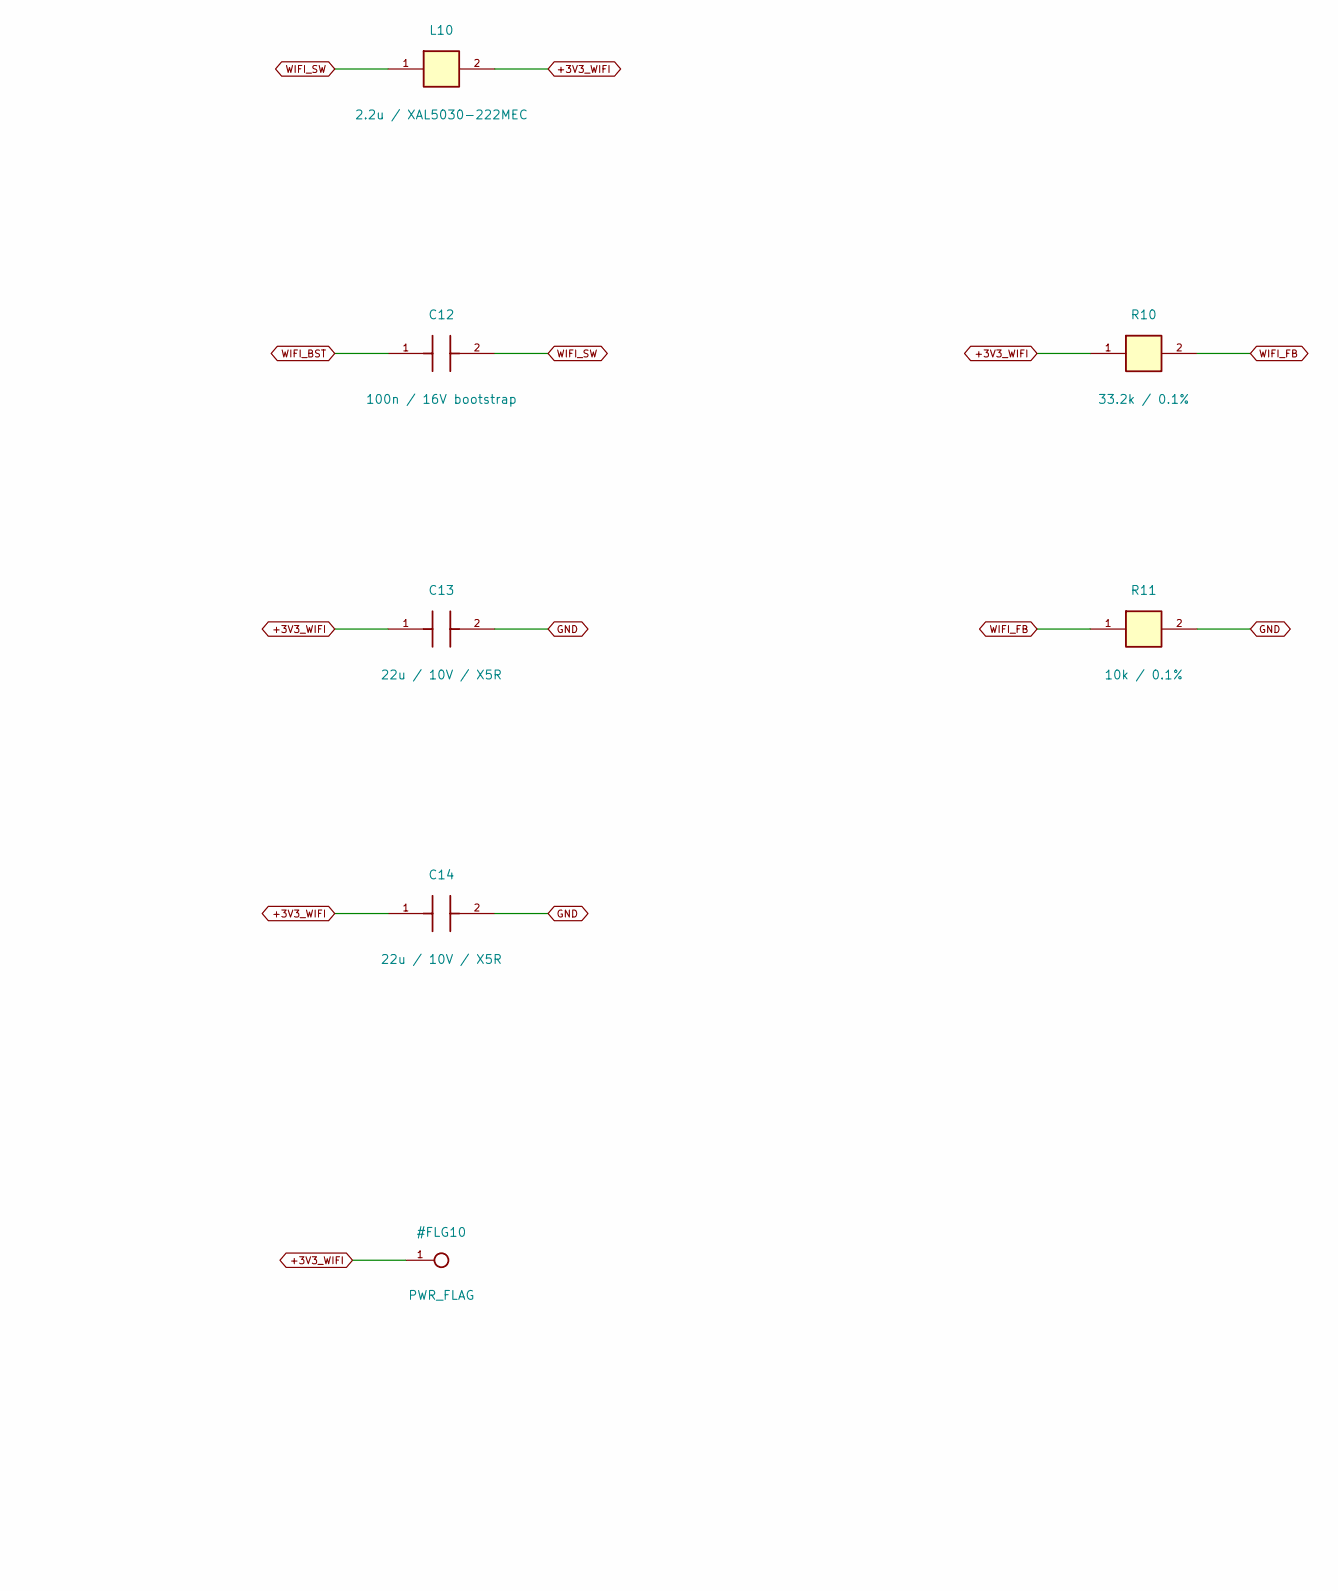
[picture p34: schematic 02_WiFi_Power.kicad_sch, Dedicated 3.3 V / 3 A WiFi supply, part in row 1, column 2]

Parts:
C10, C13, C14: 22u / 10V / X5R; C_1206_3216Metric; MPN 1206X226K160NT; LCSC C105480
C11: 100n / 16V; C_0603_1608Metric; MPN CL10B104KB8NNNC; LCSC C1591
C12: 100n / 16V bootstrap; C_0603_1608Metric; MPN CL10B104KB8NNNC; LCSC C1591
L10: 2.2u / XAL5030-222MEC; L_Coilcraft_XAL5030-XXX; MPN XAL5030-222MEC; LCSC C920280
R10: 33.2k / 0.1%; R_0603_1608Metric; MPN TNPW060333K2BEEA; LCSC C2075328
R11: 10k / 0.1%; R_0603_1608Metric; MPN PTFR0603B10K0P9; LCSC C328421
TP10: +3V3_WIFI; TestPoint_Pad_D1.5mm; JLCPCB Status EXCLUDE_FROM_JLCPCB_ASSEMBLY
U10: TPS565201DDCR; SOT-23-6; MPN TPS565201DDCR; LCSC C327676

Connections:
+3V3_WIFI: C13.1, C14.1, L10.2, R10.1, TP10.1; also elsewhere on the board
+5V_MAIN: C10.1, C11.1, U10.3 (VIN), U10.5 (EN); also elsewhere on the board
GND: C10.2, C11.2, C13.2, C14.2, R11.2, U10.1 (GND); also elsewhere on the board
WIFI_BST: C12.1, U10.6 (VBST)
WIFI_FB: R10.2, R11.1, U10.4 (VFB)
WIFI_SW: C12.2, L10.1, U10.2 (SW)

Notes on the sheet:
Regulator is enabled with MAIN_5V. PCIe reset remains asserted by CM4 during boot.
Input/output MLCC effective capacitance, load steps and AW7916 onboard capacitance require qualification.
5 V input only. R divider: nominal 3.283 V; AW7916 requires 3.3 V +/-5%.
Place input loop, bootstrap capacitor and output loop tightly; feedback senses at output capacitor.

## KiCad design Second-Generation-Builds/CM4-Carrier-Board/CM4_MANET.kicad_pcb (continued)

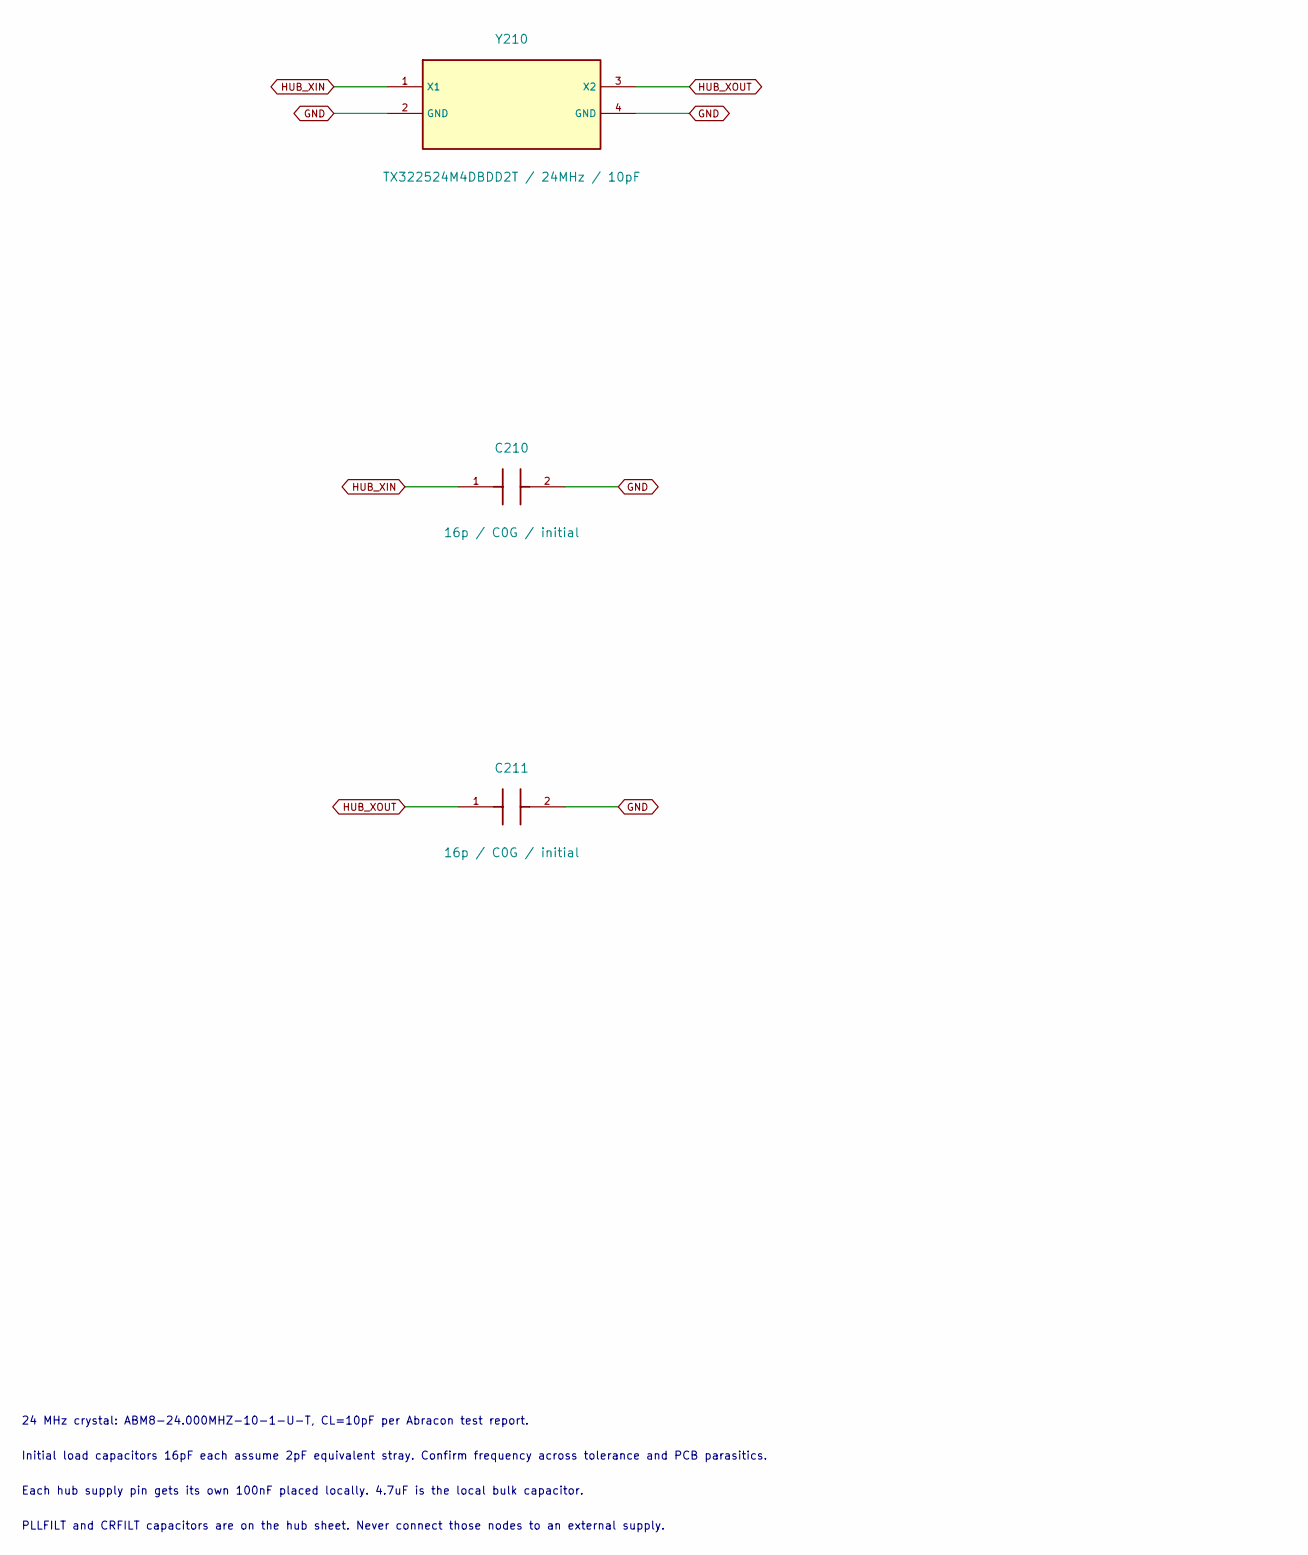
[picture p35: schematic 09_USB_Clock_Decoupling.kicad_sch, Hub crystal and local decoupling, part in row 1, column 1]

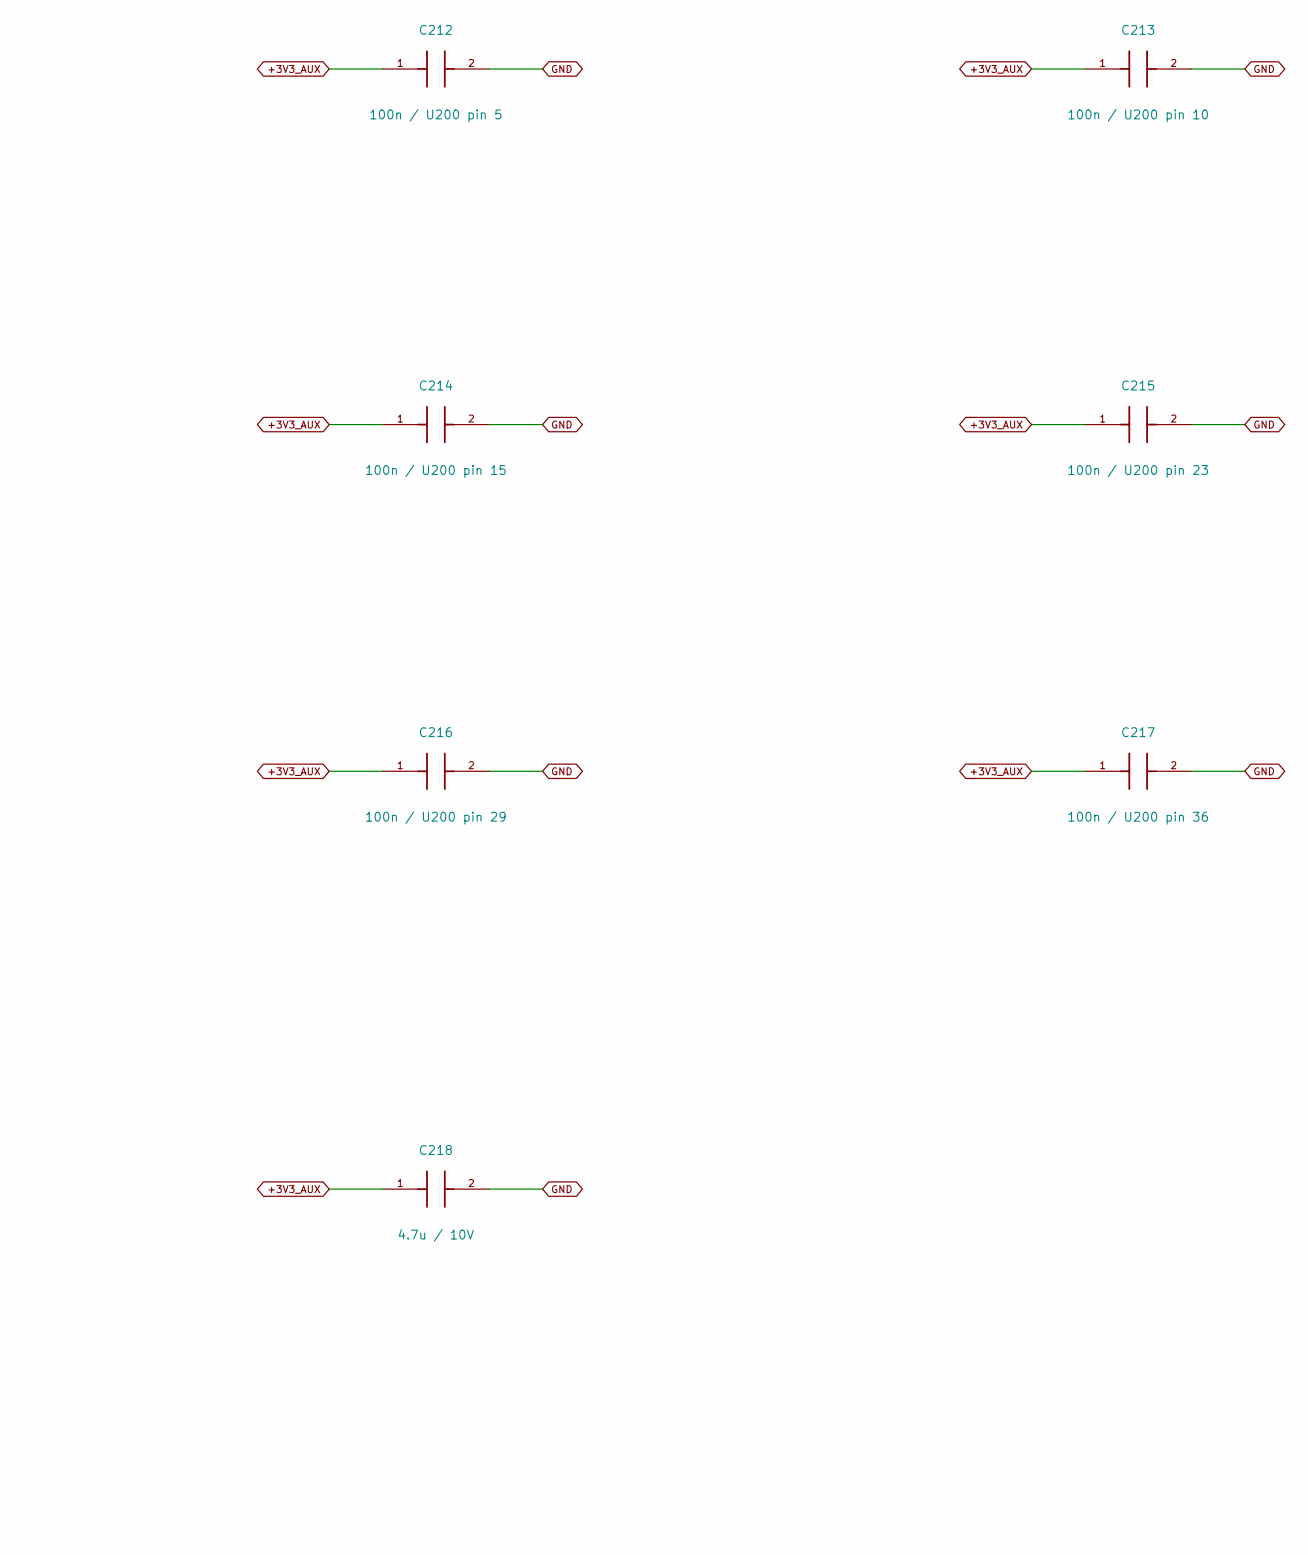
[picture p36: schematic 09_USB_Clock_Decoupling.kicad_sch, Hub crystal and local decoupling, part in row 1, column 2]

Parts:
C210, C211: 16p / C0G / initial; C_0603_1608Metric; MPN CGA0603C0G160J500JT; LCSC C51704736
C212: 100n / U200 pin 5; C_0603_1608Metric; MPN CL10B104KB8NNNC; LCSC C1591
C213: 100n / U200 pin 10; C_0603_1608Metric; MPN CL10B104KB8NNNC; LCSC C1591
C214: 100n / U200 pin 15; C_0603_1608Metric; MPN CL10B104KB8NNNC; LCSC C1591
C215: 100n / U200 pin 23; C_0603_1608Metric; MPN CL10B104KB8NNNC; LCSC C1591
C216: 100n / U200 pin 29; C_0603_1608Metric; MPN CL10B104KB8NNNC; LCSC C1591
C217: 100n / U200 pin 36; C_0603_1608Metric; MPN CL10B104KB8NNNC; LCSC C1591
C218: 4.7u / 10V; C_0805_2012Metric; MPN C0805C475M8PACTU; LCSC C2175388
Y210: TX322524M4DBDD2T / 24MHz / 10pF; Crystal_SMD_3225-4Pin_3.2x2.5mm; MPN TX322524M4DBDD2T; LCSC C5308005

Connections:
+3V3_AUX: C212.1, C213.1, C214.1, C215.1, C216.1, C217.1, C218.1; also elsewhere on the board
GND: C210.2, C211.2, C212.2, C213.2, C214.2, C215.2, C216.2, C217.2, C218.2, Y210.2 (GND), Y210.4 (GND); also elsewhere on the board
HUB_XIN: C210.1, Y210.1 (X1); also elsewhere on the board
HUB_XOUT: C211.1, Y210.3 (X2); also elsewhere on the board

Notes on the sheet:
Initial load capacitors 16pF each assume 2pF equivalent stray. Confirm frequency across tolerance and PCB parasitics.
Each hub supply pin gets its own 100nF placed locally. 4.7uF is the local bulk capacitor.
24 MHz crystal: ABM8-24.000MHZ-10-1-U-T, CL=10pF per Abracon test report.
PLLFILT and CRFILT capacitors are on the hub sheet. Never connect those nodes to an external supply.

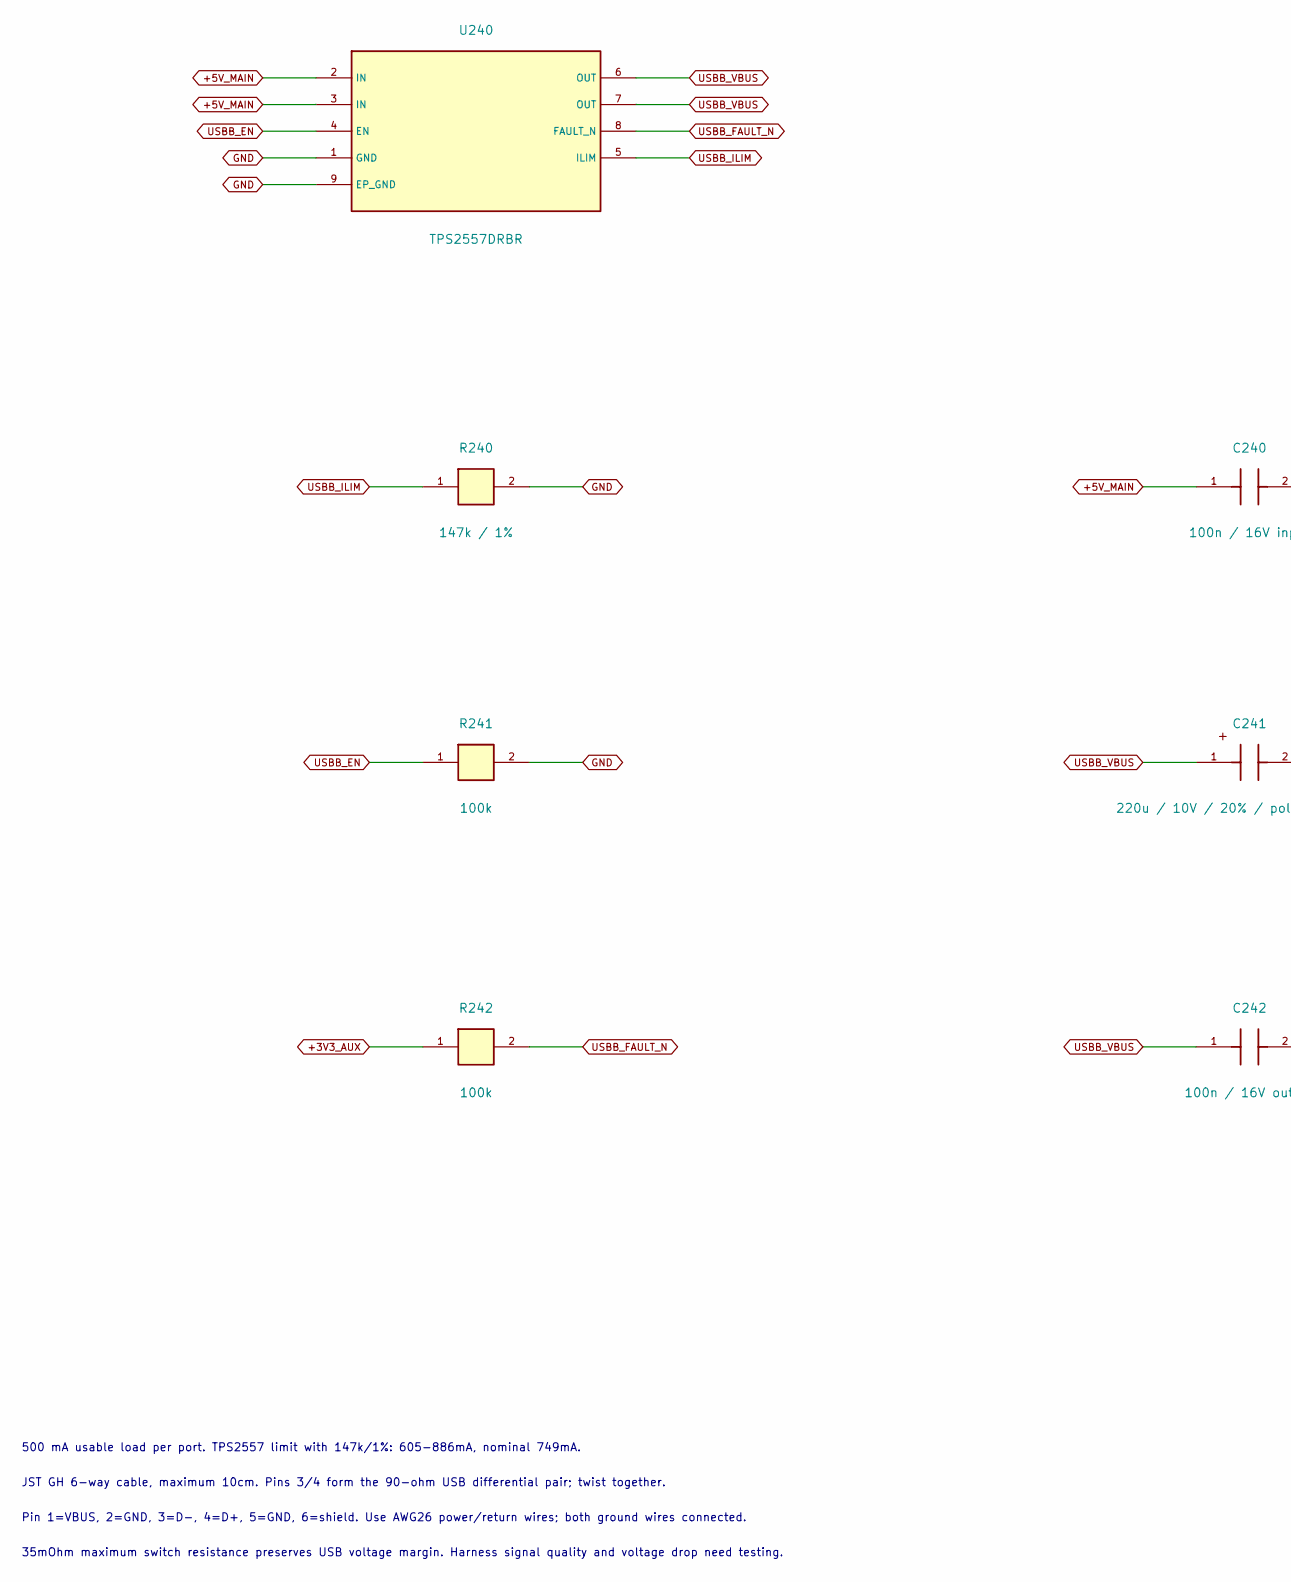
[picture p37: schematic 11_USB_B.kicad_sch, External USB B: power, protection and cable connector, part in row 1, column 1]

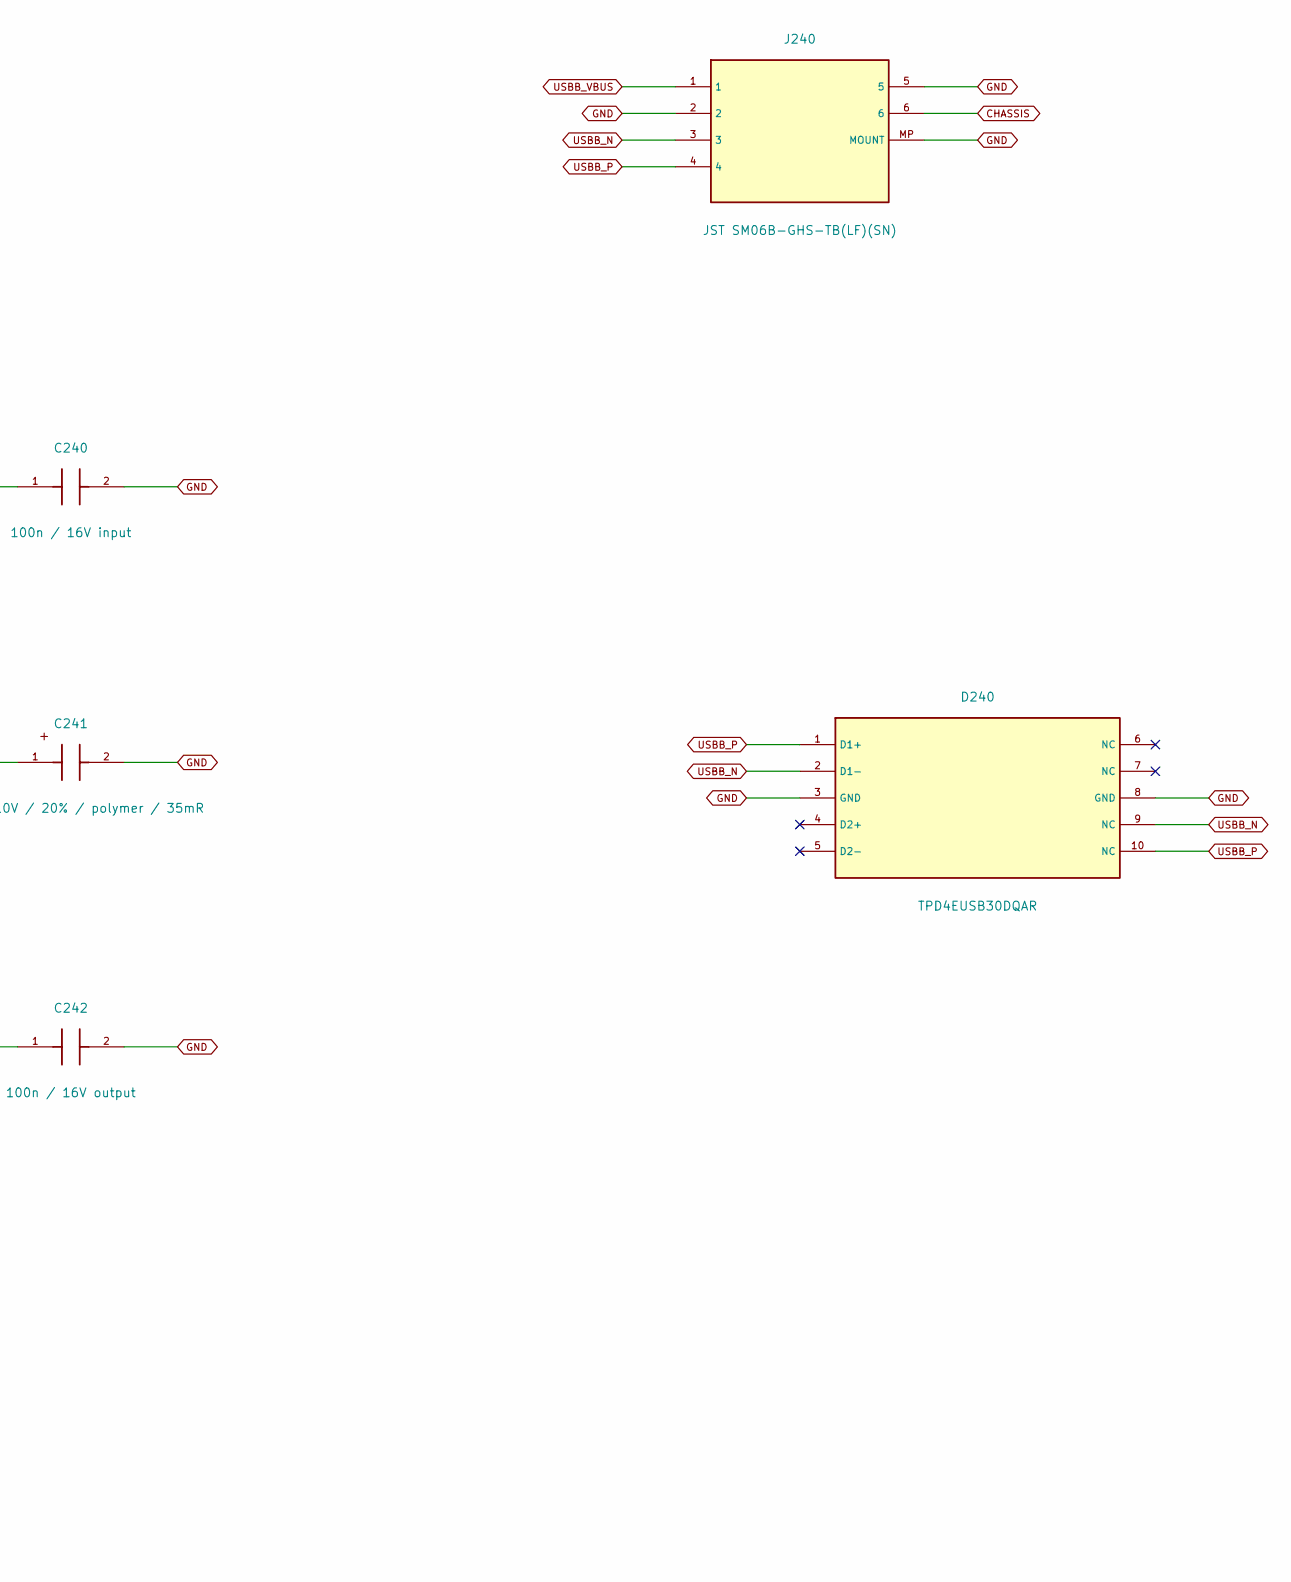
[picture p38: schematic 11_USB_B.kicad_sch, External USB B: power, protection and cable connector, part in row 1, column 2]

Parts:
C240: 100n / 16V input; C_0603_1608Metric; MPN CL10B104KB8NNNC; LCSC C1591
C241: 220u / 10V / 20% / polymer / 35mR; CP_Elec_6.3x5.8; MPN JBLM2221M010C058RTM 220UF 10V; LCSC C19270700
C242: 100n / 16V output; C_0603_1608Metric; MPN CL10B104KB8NNNC; LCSC C1591
D240: TPD4EUSB30DQAR; USON-10_2.5x1.0mm_P0.5mm; MPN TPD4EUSB30DQAR; LCSC C90627
J240: JST SM06B-GHS-TB(LF)(SN); JST_GH_SM06B-GHS-TB_1x06-1MP_P1.25mm_Horizontal; MPN SM06B-GHS-TB(LF)(SN); LCSC C133065
R240: 147k / 1%; R_0603_1608Metric; MPN CR-03FL7---147K; LCSC C216852
R241, R242: 100k; R_0603_1608Metric; MPN 0603WAF1003T5E; LCSC C25803
U240: TPS2557DRBR; VSON-8-1EP_3x3mm_P0.65mm_EP1.65x2.4mm; MPN TPS2557DRBR; LCSC C130056

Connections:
+3V3_AUX: R242.1; also elsewhere on the board
+5V_MAIN: C240.1, U240.2 (IN), U240.3 (IN); also elsewhere on the board
CHASSIS: J240.6; also elsewhere on the board
GND: C240.2, C241.2, C242.2, D240.3 (GND), D240.8 (GND), J240.2, J240.5, J240.MP (MOUNT), R240.2, R241.2, U240.1 (GND), U240.9 (EP_GND); also elsewhere on the board
USBB_EN: R241.1, U240.4 (EN); also elsewhere on the board
USBB_FAULT_N: R242.2, U240.8 (FAULT_N); also elsewhere on the board
USBB_ILIM: R240.1, U240.5 (ILIM)
USBB_N: D240.2 (D1-), D240.9 (NC), J240.3; also elsewhere on the board
USBB_P: D240.1 (D1+), D240.10 (NC), J240.4; also elsewhere on the board
USBB_VBUS: C241.1, C242.1, J240.1, U240.6 (OUT), U240.7 (OUT)

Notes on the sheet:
Pin 1=VBUS, 2=GND, 3=D-, 4=D+, 5=GND, 6=shield. Use AWG26 power/return wires; both ground wires connected.
35mOhm maximum switch resistance preserves USB voltage margin. Harness signal quality and voltage drop need testing.
500 mA usable load per port. TPS2557 limit with 147k/1%: 605-886mA, nominal 749mA.
JST GH 6-way cable, maximum 10cm. Pins 3/4 form the 90-ohm USB differential pair; twist together.

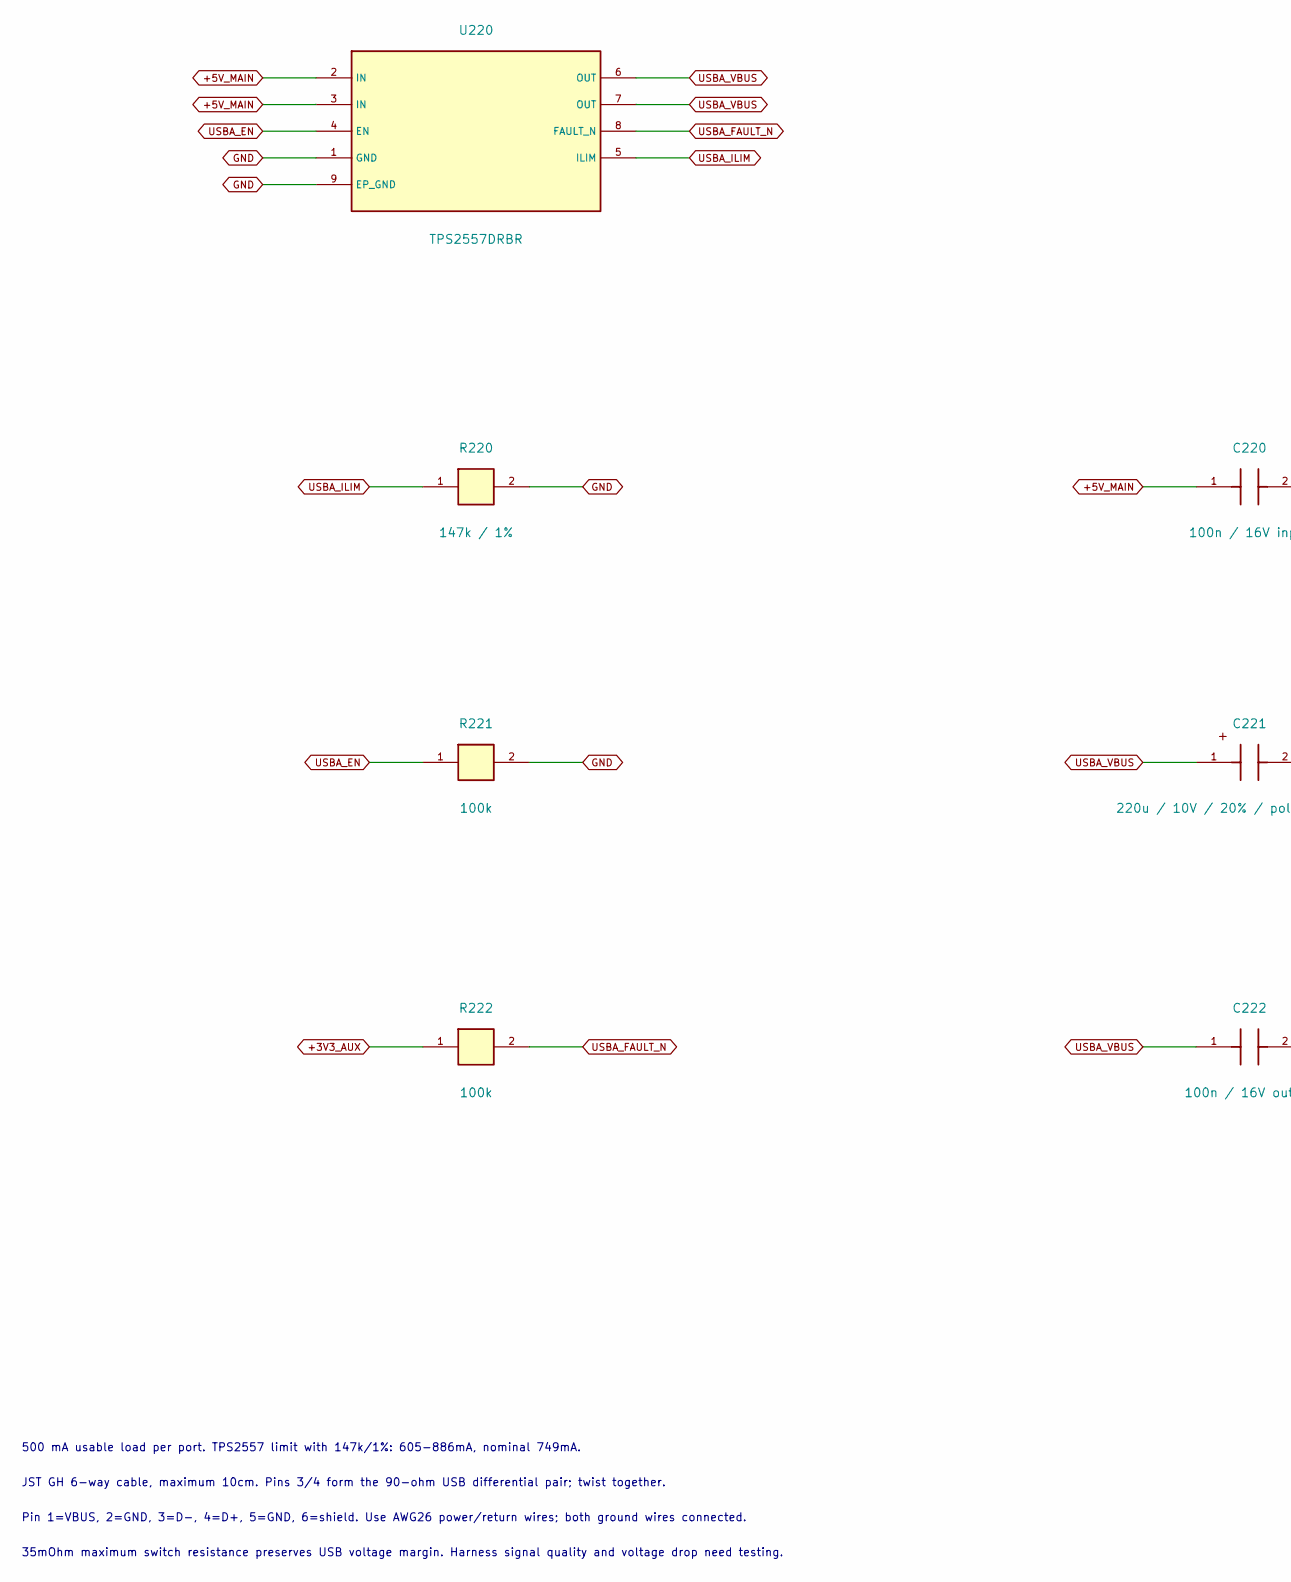
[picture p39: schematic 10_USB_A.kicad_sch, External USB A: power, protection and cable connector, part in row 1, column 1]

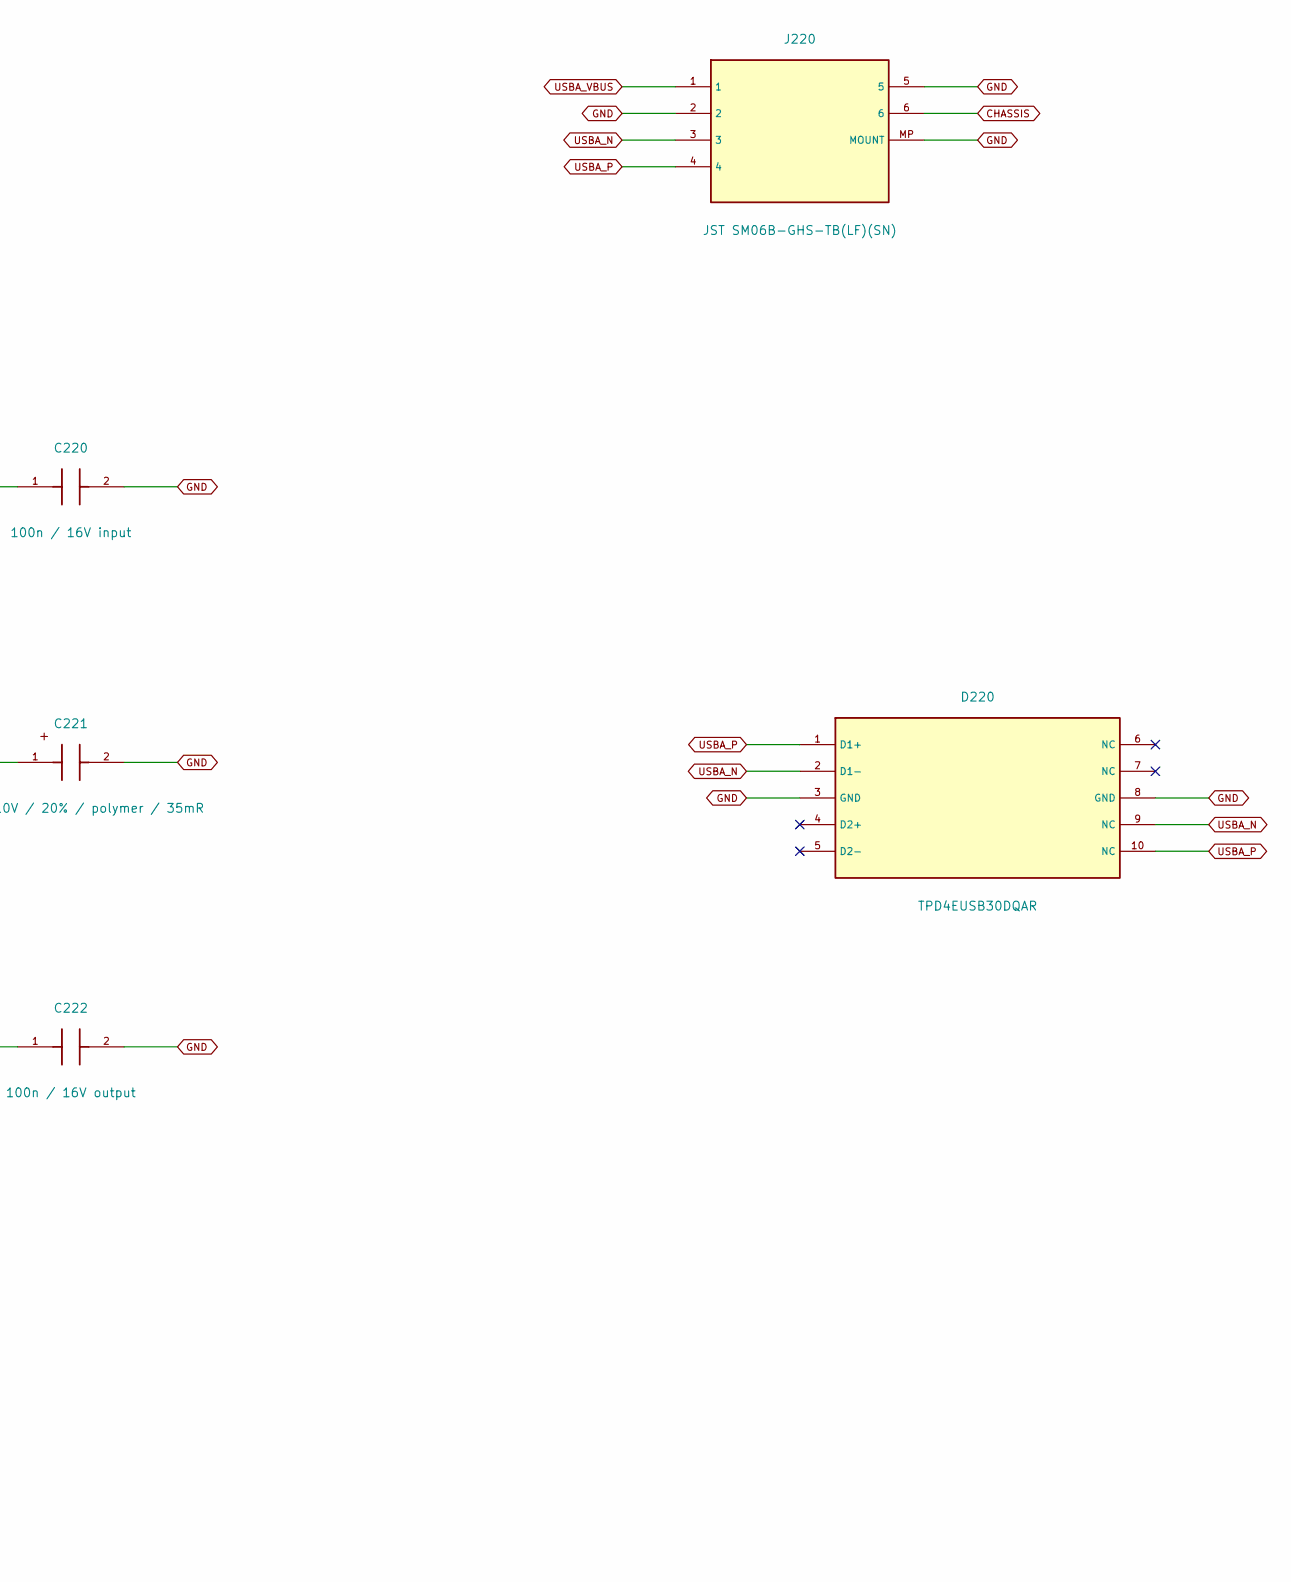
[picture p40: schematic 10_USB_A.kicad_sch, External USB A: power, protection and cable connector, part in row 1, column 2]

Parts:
C220: 100n / 16V input; C_0603_1608Metric; MPN CL10B104KB8NNNC; LCSC C1591
C221: 220u / 10V / 20% / polymer / 35mR; CP_Elec_6.3x5.8; MPN JBLM2221M010C058RTM 220UF 10V; LCSC C19270700
C222: 100n / 16V output; C_0603_1608Metric; MPN CL10B104KB8NNNC; LCSC C1591
D220: TPD4EUSB30DQAR; USON-10_2.5x1.0mm_P0.5mm; MPN TPD4EUSB30DQAR; LCSC C90627
J220: JST SM06B-GHS-TB(LF)(SN); JST_GH_SM06B-GHS-TB_1x06-1MP_P1.25mm_Horizontal; MPN SM06B-GHS-TB(LF)(SN); LCSC C133065
R220: 147k / 1%; R_0603_1608Metric; MPN CR-03FL7---147K; LCSC C216852
R221, R222: 100k; R_0603_1608Metric; MPN 0603WAF1003T5E; LCSC C25803
U220: TPS2557DRBR; VSON-8-1EP_3x3mm_P0.65mm_EP1.65x2.4mm; MPN TPS2557DRBR; LCSC C130056

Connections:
+3V3_AUX: R222.1; also elsewhere on the board
+5V_MAIN: C220.1, U220.2 (IN), U220.3 (IN); also elsewhere on the board
CHASSIS: J220.6; also elsewhere on the board
GND: C220.2, C221.2, C222.2, D220.3 (GND), D220.8 (GND), J220.2, J220.5, J220.MP (MOUNT), R220.2, R221.2, U220.1 (GND), U220.9 (EP_GND); also elsewhere on the board
USBA_EN: R221.1, U220.4 (EN); also elsewhere on the board
USBA_FAULT_N: R222.2, U220.8 (FAULT_N); also elsewhere on the board
USBA_ILIM: R220.1, U220.5 (ILIM)
USBA_N: D220.2 (D1-), D220.9 (NC), J220.3; also elsewhere on the board
USBA_P: D220.1 (D1+), D220.10 (NC), J220.4; also elsewhere on the board
USBA_VBUS: C221.1, C222.1, J220.1, U220.6 (OUT), U220.7 (OUT)

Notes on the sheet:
35mOhm maximum switch resistance preserves USB voltage margin. Harness signal quality and voltage drop need testing.
500 mA usable load per port. TPS2557 limit with 147k/1%: 605-886mA, nominal 749mA.
JST GH 6-way cable, maximum 10cm. Pins 3/4 form the 90-ohm USB differential pair; twist together.
Pin 1=VBUS, 2=GND, 3=D-, 4=D+, 5=GND, 6=shield. Use AWG26 power/return wires; both ground wires connected.

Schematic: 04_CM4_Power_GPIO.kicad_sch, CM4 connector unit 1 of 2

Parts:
U100: CM4 Lite / 4GB / no WiFi; Raspberry-Pi-4-Compute-Module; JLCPCB Status EXCLUDE_FROM_JLCPCB_ASSEMBLY

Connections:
+3V3_CM4: U100.78 (GPIO_VREF(1.8v/3.3v_Input)), U100.84 (+3.3v_(Output)), U100.86 (+3.3v_(Output)); also elsewhere on the board
+5V_MAIN: U100.77 (+5v_(Input)), U100.79 (+5v_(Input)), U100.81 (+5v_(Input)), U100.83 (+5v_(Input)), U100.85 (+5v_(Input)), U100.87 (+5v_(Input)); also elsewhere on the board
CM4_GLOBAL_EN: U100.99 (Global_EN); also elsewhere on the board
CM4_nEXTRST: U100.100 (nEXTRST); also elsewhere on the board
CM4_nRPIBOOT: U100.93 (nRPIBOOT); also elsewhere on the board
ETH0_N: U100.10 (Ethernet_Pair0_N); also elsewhere on the board
ETH0_P: U100.12 (Ethernet_Pair0_P); also elsewhere on the board
ETH1_N: U100.6 (Ethernet_Pair1_N); also elsewhere on the board
ETH1_P: U100.4 (Ethernet_Pair1_P); also elsewhere on the board
ETH2_N: U100.9 (Ethernet_Pair2_N); also elsewhere on the board
ETH2_P: U100.11 (Ethernet_Pair2_P); also elsewhere on the board
ETH3_N: U100.5 (Ethernet_Pair3_N); also elsewhere on the board
ETH3_P: U100.3 (Ethernet_Pair3_P); also elsewhere on the board
GND: U100.1 (GND), U100.7 (GND), U100.8 (GND), U100.13 (GND), U100.14 (GND), U100.22 (GND), U100.23 (GND), U100.32 (GND), U100.33 (GND), U100.42 (GND), U100.43 (GND), U100.52 (GND), U100.53 (GND), U100.59 (GND), U100.60 (GND), U100.65 (GND), U100.66 (GND), U100.71 (GND), U100.74 (GND), U100.98 (GND); also elsewhere on the board
SD_CLK: U100.57 (SD_CLK); also elsewhere on the board
SD_CMD: U100.62 (SD_CMD); also elsewhere on the board
SD_DAT0: U100.63 (SD_DAT0); also elsewhere on the board
SD_DAT1: U100.67 (SD_DAT1); also elsewhere on the board
SD_DAT2: U100.69 (SD_DAT2); also elsewhere on the board
SD_DAT3: U100.61 (SD_DAT3); also elsewhere on the board
SD_PWR_ON: U100.75 (SD_PWR_ON); also elsewhere on the board
UART_RXD: U100.51 (GPIO15); also elsewhere on the board
UART_TXD: U100.55 (GPIO14); also elsewhere on the board

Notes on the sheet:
CM4 Lite 4 GB without WiFi; microSD is required. GPIO_VREF is supplied from CM4 own 3.3 V output.
Unused functions explicitly not connected. All ground and 5 V contacts connected.
One physical CM4 footprint containing both 100-pin connectors. Pin numbers from official Raspberry Pi CM4IO.

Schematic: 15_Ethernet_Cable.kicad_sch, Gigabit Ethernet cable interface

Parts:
C500: 1n / 2kV / X7R / shield coupling; C_1812_4532Metric; MPN 1812B102K202NT; LCSC C36077
C501: 100n; C_0402_1005Metric; MPN GRM155R71C104KA88J; LCSC C106994
C502: 1n / 2kV; C_1812_4532Metric; MPN 1812B102K202NT; LCSC C36077
D500, D501: TPD4EUSB30DQAR; USON-10_2.5x1.0mm_P0.5mm; MPN TPD4EUSB30DQAR; LCSC C90627
J500: JST SM12B-GHS-TB(LF)(SN); JST_GH_SM12B-GHS-TB_1x12-1MP_P1.25mm_Horizontal; MPN SM12B-GHS-TB(LF)(SN); LCSC C265421
R500: 1M / shield bleed; R_0603_1608Metric; MPN 0603WAF1004T5E; LCSC C22935
R501: 0R / optional chassis bond; R_0603_1608Metric; JLCPCB Status EXCLUDE_FROM_JLCPCB_ASSEMBLY; not fitted
R502, R503, R504, R505: 75R; R_0603_1608Metric; MPN RC0603FR-0775RL; LCSC C112309
T500: G2401CE / C2904710; SMD-24_L15.1-W7.1-P1.00-LS10.0-BL

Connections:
CHASSIS: C500.1, C502.2, J500.12, R500.1, R501.1; also elsewhere on the board
ETH0_N: D500.2 (D1-), T500.3; also elsewhere on the board
ETH0_P: D500.1 (D1+), T500.2; also elsewhere on the board
ETH1_N: D500.5 (D2-), T500.6; also elsewhere on the board
ETH1_P: D500.4 (D2+), T500.5; also elsewhere on the board
ETH2_N: D501.2 (D1-), T500.9; also elsewhere on the board
ETH2_P: D501.1 (D1+), T500.8; also elsewhere on the board
ETH3_N: D501.5 (D2-), T500.12; also elsewhere on the board
ETH3_P: D501.4 (D2+), T500.11; also elsewhere on the board
ETH_BST: C502.1, R502.2, R503.2, R504.2, R505.2
ETH_C0_CT: R502.1, T500.24
ETH_C0_N: J500.3, T500.22
ETH_C0_P: J500.2, T500.23
ETH_C1_CT: R503.1, T500.21
ETH_C1_N: J500.5, T500.19
ETH_C1_P: J500.4, T500.20
ETH_C2_CT: R504.1, T500.18
ETH_C2_N: J500.8, T500.16
ETH_C2_P: J500.7, T500.17
ETH_C3_CT: R505.1, T500.15
ETH_C3_N: J500.10, T500.13
ETH_C3_P: J500.9, T500.14
ETH_PHY_CT: C501.1, T500.1, T500.4, T500.7, T500.10
GND: C500.2, C501.2, D500.3 (GND), D500.8 (GND), D501.3 (GND), D501.8 (GND), J500.1, J500.6, J500.11, J500.MP (MOUNT), R500.2, R501.2; also elsewhere on the board

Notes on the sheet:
No Ethernet transformer on carrier. External assembly must contain the specified magnetics; plain RJ45 alone will not work.
Pinout: 1 GND, 2/3 pair0 +/-, 4/5 pair1 +/-, 6 GND, 7/8 pair2 +/-, 9/10 pair3 +/-, 11 GND, 12 shield.
JST GH 12-way is a prototype candidate: four 100-ohm twisted pairs, short untwisted ends, shielded cable.
RJ45/MagJack is on enclosure panel, not on carrier. Maximum internal cable length 10cm.

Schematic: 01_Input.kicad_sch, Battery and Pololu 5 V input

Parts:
C1: 47u / 16V / X6S; C_1210_3225Metric; MPN GRM32EC81C476KE15L; LCSC C162512
C2: 100n / 16V / X7R; C_0603_1608Metric; MPN CL10B104KB8NNNC; LCSC C1591
J1: BATTERY SOLDER PADS; Battery_Pads; JLCPCB Status EXCLUDE_FROM_JLCPCB_ASSEMBLY
PS1: Pololu #5571 / D42V55F5; Pololu_D42V55F5; JLCPCB Status EXCLUDE_FROM_JLCPCB_ASSEMBLY
R1: 100k / 1%; R_0603_1608Metric; MPN 0603WAF1003T5E; LCSC C25803
TP1: +5V_MAIN; TestPoint_Pad_D1.5mm; JLCPCB Status EXCLUDE_FROM_JLCPCB_ASSEMBLY
TP2: GND; TestPoint_Pad_D1.5mm; JLCPCB Status EXCLUDE_FROM_JLCPCB_ASSEMBLY
TP3: MAIN_PG; TestPoint_Pad_D1.5mm; JLCPCB Status EXCLUDE_FROM_JLCPCB_ASSEMBLY

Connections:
+5V_MAIN: C1.1, C2.1, PS1.VOUT (VOUT_5V), R1.1, TP1.1; also elsewhere on the board
BAT_POS: J1.1, PS1.VIN
GND: C1.2, C2.2, J1.2, PS1.GND, TP2.1; also elsewhere on the board
MAIN_PG: PS1.PG, R1.2, TP3.1

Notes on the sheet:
Total 5 V budget remains near the regulator capability; thermal/load qualification is mandatory.
Pololu EN is pulled to battery VIN internally: do not connect directly to CM4 GPIO.
Pololu duplicated power pads share names. Manual assembly with clearance above carrier required.
Battery: 2S-4S, normally 3S. Two solder pads only. Pololu solder-mounted on carrier.

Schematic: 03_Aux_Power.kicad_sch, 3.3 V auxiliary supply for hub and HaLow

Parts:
C20: 10u / 10V; C_0805_2012Metric; MPN CL21A106KAYNNNE; LCSC C15850
C21: 100n / 16V AVIN; C_0603_1608Metric; MPN CL10B104KB8NNNC; LCSC C1591
C22: 22u / 10V; C_1206_3216Metric; MPN 1206X226K160NT; LCSC C105480
C23: 10n / 16V SS; C_0603_1608Metric; MPN TCC0603X7R103M500CT; LCSC C376807
L20: 2.2u / XFL4020-222MEC; L_Coilcraft_XxL4020; MPN XFL4020-222MEC; LCSC C122469
TP20: +3V3_AUX; TestPoint_Pad_D1.5mm; JLCPCB Status EXCLUDE_FROM_JLCPCB_ASSEMBLY
U20: TPS62142RGTR; VQFN-16-1EP_3x3mm_P0.5mm_EP1.68x1.68mm; MPN TPS62142RGTR; LCSC C129331

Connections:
+3V3_AUX: C22.1, L20.2, TP20.1, U20.14 (VOS); also elsewhere on the board
+5V_MAIN: C20.1, C21.1, U20.10 (AVIN), U20.11 (PVIN), U20.12 (PVIN), U20.13 (EN); also elsewhere on the board
AUX_SS: C23.1, U20.9 (SS_TR)
AUX_SW: L20.1, U20.1 (SW), U20.2 (SW), U20.3 (SW)
GND: C20.2, C21.2, C22.2, C23.2, U20.5 (FB_FIXED_GND), U20.6 (AGND), U20.7 (FSW), U20.8 (DEF), U20.15 (PGND), U20.16 (PGND), U20.17 (EP_GND); also elsewhere on the board
HUB_RESET_N: U20.4 (PG); also elsewhere on the board

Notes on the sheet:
TPS62142 fixed 3.3 V / 2 A. CM4 3.3 V output is a separate rail; never join the two.
FSW=GND selects nominal 2.5 MHz; DEF=GND selects nominal 3.3 V. FB grounded for fixed-output device.
SS/TR=10nF; nominal soft start about 5ms. Power-good joins open-drain hub reset interlock.
Coil/capacitor effective values and cumulative HaLow decoupling need transient validation.

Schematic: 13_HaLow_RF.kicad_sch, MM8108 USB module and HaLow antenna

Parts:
C300: 2.2u / 10V; C_0603_1608Metric; MPN CL10A225KO8NNNC; LCSC C23630
C301: 10u / 10V VBAT pin10; C_0805_2012Metric; MPN CL21A106KAYNNNE; LCSC C15850
C302: 10u / 10V VBAT_TX pin24; C_0805_2012Metric; MPN CL21A106KAYNNNE; LCSC C15850
C303: 10u / 10V VDD_USB pin25; C_0805_2012Metric; MPN CL21A106KAYNNNE; LCSC C15850
C304: 100n / 16V VDDIO pin22; C_0603_1608Metric; MPN CL10B104KB8NNNC; LCSC C1591
C305, C306: DNP / matching; C_0402_1005Metric; JLCPCB Status EXCLUDE_FROM_JLCPCB_ASSEMBLY; not fitted
C307, C308, C309: 100n / 16V / local MM8108 bypass; C_0603_1608Metric; MPN CL10B104KB8NNNC; LCSC C1591
J300: Hirose U.FL-R-SMT-1; U.FL_Hirose_U.FL-R-SMT-1_Vertical; MPN U.FL-R-SMT-1(80); LCSC C88374
R300: 220k / 1%; R_0603_1608Metric; MPN FRC0603F2203TS; LCSC C2907013
R301: 0R / RF link; R_0402_1005Metric; MPN 0402WGF0000TCE; LCSC C17168
U300: MM8108-MF15457; MorseMicro_MM8108-MF15457; MPN MM8108-MF15457; LCSC C51941506

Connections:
+3V3_HALOW: C301.1, C302.1, C303.1, C304.1, C307.1, C308.1, C309.1, R300.1, U300.10 (VBAT), U300.22 (VDDIO), U300.24 (VBAT_TX), U300.25 (VDD_USB); also elsewhere on the board
GND: C300.2, C301.2, C302.2, C303.2, C304.2, C305.2, C306.2, C307.2, C308.2, C309.2, J300.2 (GND), U300.1 (GND), U300.3 (GND), U300.11 (GND), U300.20 (GND), U300.23 (GND), U300.26 (GND), U300.30 (GND), U300.38 (GND); also elsewhere on the board
HALOW_ANT: C306.1, J300.1 (RF), R301.2
HALOW_RESET_N: C300.1, R300.2, U300.4 (RESET_N)
HALOW_RF: C305.1, R301.1, U300.2 (ANT)
HALOW_USB_N: U300.27 (USB_D_N); also elsewhere on the board
HALOW_USB_P: U300.28 (USB_D_P); also elsewhere on the board

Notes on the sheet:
R300/C300 provide reset delay. Matching network: 0R series fitted, both shunt capacitors DNP.
ANT to U.FL: short 50-ohm RF route with ground stitching. Exact module footprint and land pattern still require review.
USB pins 27/28. All four supply pins use switched 3.3 V. Unused SDIO/JTAG/GPIO pins left open as reference.
USB network adapter circuit based on Morse Micro MM8108-MF15457 datasheet v4 figure 4.

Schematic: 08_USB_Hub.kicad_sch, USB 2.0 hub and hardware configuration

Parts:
C200: 100n / 10V / low-ESR / CRFILT; C_0603_1608Metric; MPN CL10B104KB8NNNC; LCSC C1591
C201: 100n / 10V / low-ESR / PLLFILT; C_0603_1608Metric; MPN CL10B104KB8NNNC; LCSC C1591
R200: 12k / 1%; R_0603_1608Metric; MPN FRC0603F1202TS; LCSC C2906989
R201, R202, R203, R204, R205, R206: 10k; R_0603_1608Metric; MPN 0603WAF1002T5E; LCSC C25804
U200: USB2514B-AEZC-TR; QFN-36-1EP_6x6mm_P0.5mm_EP4.1x4.1mm; MPN USB2514B-AEZC-TR; LCSC C16251

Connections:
+3V3_AUX: R204.1, R205.1, R206.1, U200.5 (VDDA33), U200.10 (VDDA33), U200.15 (VDD33), U200.23 (VDD33), U200.29 (VDDA33), U200.36 (VDDA33); also elsewhere on the board
+3V3_CM4: U200.27 (VBUS_DET); also elsewhere on the board
GND: C200.2, C201.2, R200.2, R201.2, R202.2, R203.2, U200.11 (TEST), U200.37 (VSS); also elsewhere on the board
HALOW_EN: U200.12 (PRTPWR1/BC_EN1); also elsewhere on the board
HALOW_FAULT_N: U200.13 (OCS_N1); also elsewhere on the board
HALOW_USB_N: U200.1 (USBDM_DN1/PRT_DIS_M1); also elsewhere on the board
HALOW_USB_P: U200.2 (USBDP_DN1/PRT_DIS_P1); also elsewhere on the board
HUB_CFG0: R201.1, U200.24 (SCL/SMBCLK/CFG_SEL0)
HUB_CFG1: R202.1, U200.25 (HS_IND/CFG_SEL1)
HUB_CRFILT: C200.1, U200.14 (CRFILT)
HUB_NONREM0: R204.2, U200.28 (SUSP_IND/LOCAL_PWR/NON_REM0)
HUB_NONREM1: R203.1, U200.22 (SDA/SMBDATA/NON_REM1)
HUB_P4_N: R205.2, U200.8 (USBDM_DN4/PRT_DIS_M4)
HUB_P4_P: R206.2, U200.9 (USBDP_DN4/PRT_DIS_P4)
HUB_PLLFILT: C201.1, U200.34 (PLLFILT)
HUB_RBIAS: R200.1, U200.35 (RBIAS)
HUB_RESET_N: U200.26 (RESET_N); also elsewhere on the board
HUB_UP_N: U200.30 (USBDM_UP); also elsewhere on the board
HUB_UP_P: U200.31 (USBDP_UP); also elsewhere on the board
HUB_XIN: U200.33 (XTALIN/CLKIN); also elsewhere on the board
HUB_XOUT: U200.32 (XTALOUT); also elsewhere on the board
USBA_EN: U200.16 (PRTPWR2/BC_EN2); also elsewhere on the board
USBA_FAULT_N: U200.17 (OCS_N2); also elsewhere on the board
USBA_N: U200.3 (USBDM_DN2/PRT_DIS_M2); also elsewhere on the board
USBA_P: U200.4 (USBDP_DN2/PRT_DIS_P2); also elsewhere on the board
USBB_EN: U200.18 (PRTPWR3/BC_EN3); also elsewhere on the board
USBB_FAULT_N: U200.19 (OCS_N3); also elsewhere on the board
USBB_N: U200.6 (USBDM_DN3/PRT_DIS_M3); also elsewhere on the board
USBB_P: U200.7 (USBDP_DN3/PRT_DIS_P3); also elsewhere on the board

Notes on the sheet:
VBUS_DET references the host CM4 3.3 V rail. HUB_RESET_N also depends on CM4 startup and AUX power-good.
CFG_SEL[1:0]=00: self-powered, individual switching and current sensing (datasheet table 5-1).
NON_REM[1:0]=01: only port 1 non-removable. Disabled port 4 has both data pins pulled up.
USB2514B: physical port 1=internal HaLow; ports 2/3=external USB A/B; port 4 disabled.

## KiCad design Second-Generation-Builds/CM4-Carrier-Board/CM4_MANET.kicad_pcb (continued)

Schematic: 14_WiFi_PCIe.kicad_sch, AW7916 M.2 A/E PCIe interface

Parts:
C400: 100n / 16V; C_0603_1608Metric; MPN CL10B104KB8NNNC; LCSC C1591
J400: APCI0085-P005A / M.2 E-key socket; M2_E_KEY_APCI0085-P005A; MPN APCI0085-P005A; LCSC C7498138
R400, R401: 10k; R_0603_1608Metric; MPN 0603WAF1002T5E; LCSC C25804
R402: 10k / host-domain pullup; R_0603_1608Metric; MPN 0603WAF1002T5E; LCSC C25804
U400: 74LVC1G07SE-7; SOT-353_SC-70-5; MPN 74LVC1G07SE-7; LCSC C67531

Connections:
+3V3_CM4: R402.1; also elsewhere on the board
+3V3_WIFI: C400.1, J400.2 (3V3), J400.4 (3V3), J400.72 (3V3), J400.74 (3V3), R400.1, R401.1, U400.5 (VCC); also elsewhere on the board
CM4_PCIE_RST_N: U400.2 (A); also elsewhere on the board
GND: C400.2, J400.1 (GND), J400.7 (GND), J400.18 (GND), J400.33 (GND), J400.39 (GND), J400.45 (GND), J400.51 (GND), J400.57 (GND), J400.63 (GND), J400.69 (GND), J400.75 (GND), U400.3 (GND); also elsewhere on the board
PCIE_CLKREQ_N: J400.53 (CLKREQ_N), R402.2; also elsewhere on the board
PCIE_CLK_N: J400.49 (REFCLK_N); also elsewhere on the board
PCIE_CLK_P: J400.47 (REFCLK_P); also elsewhere on the board
PCIE_RX_N: J400.43 (CARD_TX_N); also elsewhere on the board
PCIE_RX_P: J400.41 (CARD_TX_P); also elsewhere on the board
PCIE_TX_N: J400.37 (CARD_RX_N); also elsewhere on the board
PCIE_TX_P: J400.35 (CARD_RX_P); also elsewhere on the board
WIFI_ENABLE_N: J400.56 (W_DISABLE1_N), R401.2
WIFI_PERST_N: J400.52 (PERST_N), R400.2, U400.4 (Y)

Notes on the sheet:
All four power contacts (2,4,72,74) carry WiFi supply; connector must support at least 0.75 A per power contact.
CM4 already includes PCIe TX and REFCLK coupling. Confirm coupling on AW7916 TX before PCB release.
AsiaRF drawing names TX/RX from card perspective: card RX pins35/37 receive CM4 TX; card TX41/43 drive CM4 RX.
Exact 1A/contact E-key socket suffix, physical mating and footprint are release blockers. Generic 0.5A sockets rejected.

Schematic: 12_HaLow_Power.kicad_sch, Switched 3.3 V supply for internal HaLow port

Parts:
C260: 1u / 10V input; C_0603_1608Metric; MPN CL10A105KB8NNNC; LCSC C15849
R260: 26.1k / 1%; R_0603_1608Metric; MPN FRC0603F2612TS; LCSC C2933182
R261, R262: 100k; R_0603_1608Metric; MPN 0603WAF1003T5E; LCSC C25803
R263: 10k / discharge; R_0603_1608Metric; MPN 0603WAF1002T5E; LCSC C25804
TP260: +3V3_HALOW; TestPoint_Pad_D1.5mm; JLCPCB Status EXCLUDE_FROM_JLCPCB_ASSEMBLY
U260: TPS2553DBVR; SOT-23-6; MPN TPS2553DBVR; LCSC C55266

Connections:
+3V3_AUX: C260.1, R262.1, U260.1 (IN); also elsewhere on the board
+3V3_HALOW: R263.1, TP260.1, U260.6 (OUT); also elsewhere on the board
GND: C260.2, R260.2, R261.2, R263.2, U260.2 (GND); also elsewhere on the board
HALOW_EN: R261.1, U260.3 (EN); also elsewhere on the board
HALOW_FAULT_N: R262.2, U260.4 (FAULT_N); also elsewhere on the board
HALOW_ILIM: R260.1, U260.5 (ILIM)

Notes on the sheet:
Internal hub port 1 enables the HaLow supply. This is a 3.3 V embedded-device rail, not external USB VBUS.
The whole module, including VDDIO and VDD_USB, powers from the same switched rail.
TPS2553 26.1k/1% limit: 908-1081mA, nominal 989mA; design reservation 0.6 A pending peak measurement.
RESET RC is on HaLow sheet. Check turn-off discharge/re-enumeration and 3.0 V minimum at module under peak load.

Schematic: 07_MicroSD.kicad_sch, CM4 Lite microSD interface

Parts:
C120: 10u / 10V; C_0805_2012Metric; MPN CL21A106KAYNNNE; LCSC C15850
C121: 100n / 16V; C_0603_1608Metric; MPN CL10B104KB8NNNC; LCSC C1591
J120: Molex 5033981892; SDCARD_MOLEX_503398-1892; MPN 5033981892; LCSC C428492
R120: 12k / 1%; R_0603_1608Metric; MPN FRC0603F1202TS; LCSC C2906989
U120: RT9742GGJ5; SOT-23-5; MPN RT9742GGJ5; LCSC C250547

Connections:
+3V3_CM4: C121.1, R120.1, U120.5 (VIN); also elsewhere on the board
GND: C120.2, C121.2, J120.6 (VSS), J120.11 (SHIELD), U120.2 (GND); also elsewhere on the board
SD_CLK: J120.5 (CLK); also elsewhere on the board
SD_CMD: J120.3 (CMD); also elsewhere on the board
SD_DAT0: J120.7 (DAT0); also elsewhere on the board
SD_DAT1: J120.8 (DAT1); also elsewhere on the board
SD_DAT2: J120.1 (DAT2); also elsewhere on the board
SD_DAT3: J120.2 (DAT3); also elsewhere on the board
SD_PWR_ON: R120.2, U120.4 (EN); also elsewhere on the board
SD_VDD: C120.1, J120.4 (VDD), U120.1 (VOUT)

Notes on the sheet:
Molex 503398-1892 socket and switched 3.3 V follow CM4IO reference.
Keep SD traces short with uninterrupted ground reference. 32 GB U3 card supplied separately.
No external pull-ups on SD data/CMD: use the CM4 reference arrangement. Card detect unused.
SD_PWR_ON has a pull-up so card is powered during boot. SD_VDD_OVERRIDE remains unconnected on CM4.



Board: 6 copper layers, 76.0 x 56.0 mm, 122 parts (4 on the bottom side), 96 nets.

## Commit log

2026-05-05 Add initial project documentation to README
    Added detailed project information including overview, features, hardware components, connectivity, power system, wiring, and build guide.
2026-05-08 Add Bill of Materials documentation
    Added a detailed Bill of Materials for the core and power systems including parts, specifications, quantities, prices, and notes.
2026-06-17 added simple wire diagram
2026-07-13 Add standalone Lunpid enclosure section to README
    Added link for standalone Lunpid enclosure in README.
2026-07-13 Fix link for Standalone Lunpid enclosure in README
    Updated link for Standalone Lunpid enclosure to point to the correct directory and added file formats.
2026-08-16 docs: reorganize mesh radio repository
    [217000 battery + frame.SLDPRT, 217000 battery + frame.STEP, 3D_RAK19007 base module + booster.SLDPRT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]
2026-08-16 Update README to clarify project nature and requirements
    Clarified the nature of the repository as a prototype CAD release and emphasized the need for experience in various technical areas for building.
2026-08-17 docs: rename legacy builds to first generation
    [217000 battery + frame.SLDPRT, 217000 battery + frame.STEP, 80mm antenna SMA.SLDPRT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]
2026-08-17 Update README to reflect battery-side terminology
2026-08-17 docs: switch license to CC BY-NC-SA 4.0
2026-08-21 docs: prepare P4-Wio upload branch and BOM strategy
2026-08-21 docs: move twist-lock battery pack to top level
2026-08-21 docs: rename builds folder to second generation
    [Mpu5 antenna.STEP, P4-WIO.3MF, P4-WIO.STEP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]
2026-08-21 docs: clear P4-Wio files for replacement upload
    [Mpu5 antenna.STEP, P4-WIO.STEP, P4-WIO_v1.1.3MF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]
2026-08-21 docs: refresh P4-Wio and battery pack file lists
2026-09-19 feat(hardware): add CM4 carrier board KiCad project
    Add the latest synchronized CM4 MANET carrier source, bundled symbols, footprints, local 3D models, project documentation, and production-readiness report. Stale fabrication exports and machine-speci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
    [01_Input.kicad_sch, 02_WiFi_Power.kicad_sch, 03_Aux_Power.kicad_sch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]
